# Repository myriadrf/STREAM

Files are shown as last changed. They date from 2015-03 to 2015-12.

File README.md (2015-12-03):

# STREAM

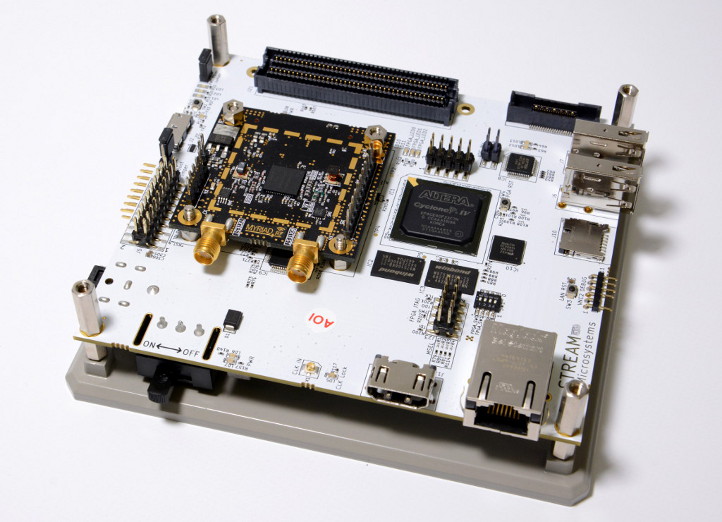
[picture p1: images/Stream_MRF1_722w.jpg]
STREAM board fitted with a Myriad-RF 1 module


[STREAM](https://myriadrf.org/projects/stream/) is a flexible platform for developing high-performance digital and RF designs using an Altera Cyclone IV FPGA and Lime Microsystems FPRF transceiver.

The original STREAM board incorporates SDRAM, Micro SD storage and a selection of other useful peripherals, with expansion via RFDIO and FMC mezzanine cards enabling use with both LMS6002-based Myriad-RF 1 and UNITE LMS7002M EVB RF modules.

uSTREAM is a low cost variant that incorporates a uRFDIO connector, enabling use with the uMyriadRF-6002 and uMyriadRF-7002 RF modules.

For more details about compatible Myriad-RF transceiver modules, see the [Reference Development Kit](https://myriadrf.org/projects/rdk/).

## Contents

The directory structure is as follows:

      apps/
          lms6_usb_distro_03v/        - uSTREAM + uMyriadRF-6002 examples
          lms7_usb_distro_01v/        - uSTREAM + uMyriadRF-7002 examples
          STREAM_LMS7EVB_distro_07v/  - STREAM + UNITE LMS7002EVB examples

      docs/                      - platform documentation

      hardware/<variant>/<version>/
          BOM/                   - bill of materials spreadsheet
          Case/                  - Aluminium case design
          Gerbers/               - Gerber CAM files
          KiCAD/                 - KiCAD schematic and layout files
          Manufacturing/         - Additional manufacturing information
          PDF/                   - Schematic and layout PDFs
          Reports/               - DRC, ERC and drill reports
              
      stream_openrisc_soc/
          bin/                   - pre-built FPGA and Linux images
          doc/                   - HTML documentation for the Stream OpenRISC SoC
          quartus/               - Quartus project archive for rebuilding the FPGA image
          src/                   - Source code for Stream-specific cores
          sw/                    - Example applications for communicating with LMS6002D

## Licensing

### Hardware

The hardware designs are licensed under a Creative Commons Attribution 3.0 Unported licence.

### FPGA design

For details of the FPGA design licensing please see the associated COPYING file(s). However, please note that this does not extend to any files provided with the Altera design tools and see the relevant files for the associated terms and conditions.

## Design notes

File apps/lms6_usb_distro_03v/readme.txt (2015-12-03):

CONTENTS
========

   I. Description of folders and files
  II. General notes
 III. ToDo

I. Description of folders and files
===================================

  readme.txt                - This file
  fx3/                      - FX3 USB microcontroller related
   |- firmware_img          - Contains compiled firmware image for FX3 USB microcontroller
  gateware                  - FPGA related
   |- bitstreams            - Contains compiled FPGA bitstreams
       |- lms6usb_trx.rbf   - FPGA biststream file. Download it to FPGA using LMS-suite Programmer
       |- lms6usb_trx_compresed.rbf   - FPGA biststream file. Download it to FPGA using LMS-suite Programmer
       |- lms6usb_trx.sof   - FPGA biststream file. Download it to FPGA using Quartus programmer
  gui                       - Software to control MyriadRF board
   |- lms-suite.exe         - Windows GUI to control/program FPGA
   |- lms6usb_settings_v1.ini  - GUI project file to test WFM Tx and FFT Viewer
   |- lms-suite_wfm
       |- onetone.wfm       - One tone test waveform file
       |- wcdma.wfm         - WCDMA test waveform file

II. General notes
==================

  Note 1: FX3 drivers, utilities and documentation must be downloaded from Cypress. 
  Note 2: FX3 MCU must be programmed before FPGA.
  Note 3: LD2 LED will start to flash after FX3 MCU is programmed successfully.
  Note 4: FPGA must be programmed before LMS6 configuration. LD5 starts to flash after succesfull FPGA programming.  
  Note 5: Set TX and RX interface clock and phase shift to 90deg. in "LMS6002USB Stick" module from "Modules" menu.	 
  Note 6: Set "Data format" to "Stream" in FFTviewer.
  Note 7: Set "Sampling frequency" to Rxfreq/2 in FFTviewer.
  Note 8: TCXO control voltage may be controlled using a "LMS6002USB Stick" module from "Modules" menu.

III. ToDo
=========

  1. RPi connector - needs to be considered what to implement.

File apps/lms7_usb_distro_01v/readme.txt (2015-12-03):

CONTENTS
========

   I. Description of folders and files
  II. General notes
 III. ToDo

I. Description of folders and files
===================================

  readme.txt                     - This file
  ReleaseNotes.txt              - Distribution release change log
  fx3/                           - FX3 USB microcontroller related
   |- firmware_img               - Contains compiled firmware image for FX3 USB microcontroller
  gateware                       - FPGA related
   |- bitstreams                 - Contains compiled FPGA bitstreams
       |- lms7_ustream_trx.rbf   - FPGA biststream file. Download it to FPGA using LMS-suite Programmer
       |- lms7_ustream_trx.sof   - FPGA biststream file. Download it to FPGA using Quartus programmer
  qii_projects                   - Quartus II project of gateware
  gui                            - Software to control MyriadRF board
   |- lms7suite.exe              - Windows GUI to control the boards
   |- ustream_trx.ini            - GUI project file to test WFM Tx and FFT Viewer
   |- lms7suite_wfm
   |   |- onetone.wfm            - One tone test waveform file
   |   |- wcdma.wfm              - WCDMA test waveform file
   |- lms7suite_mcu              - LMS7002M internal MCU related files

II. General notes
==================

  Note 1: FX3 drivers, utilities and documentation must be downloaded from Cypress. 
  Note 2: FX3 MCU must be programmed before FPGA.
  Note 3: LD2 LED will start to flash after FX3 MCU is programmed successfully.
  Note 4: FPGA must be programmed before LMS7 configuration. LD5 starts to flash after succesfull FPGA programming.  

III. ToDo
=========

  1. RPi connector - needs to be considered what to implement.

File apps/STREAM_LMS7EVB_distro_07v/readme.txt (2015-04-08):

CONTENTS
========

   I. Description of folders and files
  II. General notes
 III. Required PCB Modifications

I. Description of folders and files
===================================

  readme.txt                - this file
        docs/                     - Quick start and user guides
	fx3/                      - FX3 USB microcontroller related
	 |- firmware_img          - Contains compiled firmware image for FX3 USB microcontroller
	gateware                  - FPGA related
	 |- bitstreams            - Contains compiled FPGA bitstreams
	     |- lms7_trx_61MHz.rbf   - FPGA biststream file. Download it to FPGA using LMS-suite Programmer
             |- lms7_trx_61MHz.sof   - FPGA biststream file. Download it to FPGA using Quartus programmer
	     |- lms7_trx_122MHz.rbf  - FPGA biststream file. Download it to FPGA using LMS-suite Programmer
             |- lms7_trx_122MHz.sof  - FPGA biststream file. Download it to FPGA using Quartus programmer
	 |- qii_projects          - Contains FPGA projects
	gui                       - Software to control MyriadRF board
	 |- lms7suite.exe         - GUI to control/program FPGA
	 |- wfm_tx_rx_61MHz.ini   - GUI project file to test WFM Tx and FFT Viewer, with 61.44MHz
	 |- wfm_tx_rx_122MHz.ini  - GUI project file to test WFM Tx and FFT Viewer, with 122.88MHz
	 |- onetone1.wfm          - One tone test waveform file
	 |- wcdma31.wfm           - WCDMA test waveform file
	lms_vcp_drivers           - Windows Virtual COM Port drivres for LMS7EVB
        lms7evb
         |-LMS7002EVBv2_e.hex     - Firmware for LMS7EVB USB microcontroller

II. General notes
==================

  	Note 1: FX3 MCU must be programmed before FPGA.
	Note 2: LD1 LED will start to flash after FX3 MCU is programmed successfully.
	Note 3: FPGA must be programmed before LMS7EVB configuration. Led (lan_led in schematic) on Ethernet connector starts to blink after succesfull FPGA programming.  
	Note 4: After programming FPGA and LMS7EVB configuration FPGA GPIO0 (pin 1 of J1 connector) will on/off for ~1s period.
	Note 5: Jumpers J22 (STREAM board) and JP2 position 1-2 (LMS7EVB board) has to be on if power is required from FMC connector for LMS7EVB. 

III. Required PCB Modifications
===============================

  Some resistors must be fitted on Streamer and LMS7EVB boards to be able control LMS7EVB via FMC connector.

  Streamer board modifications:
  Fit these resistors: R189, R190, R191, R192, R193, R194

  EVB7 board modifications:
  Fit these resistors: 	R91, R92, R93, R94, R95, R96

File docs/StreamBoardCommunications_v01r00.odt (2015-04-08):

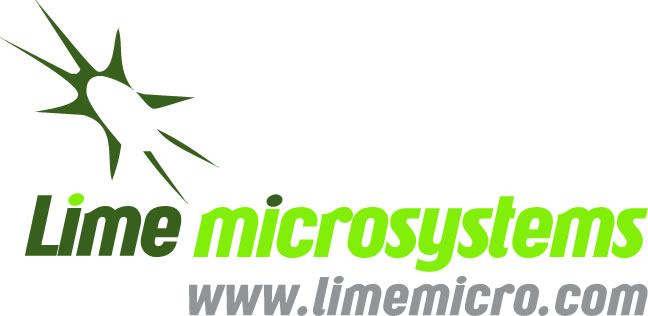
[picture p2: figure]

Lime Microsystems Limited

Surrey Tech Centre

Occam Road

The Surrey Research Park

Guildford, Surrey GU2 7YG

United Kingdom

Tel: +44 (0) 1483 685 063

Fax: +44 (0) 1428 656 662

e-mail: enquiries@limemicro.com

Stream Board Communications

Chip version: | LMS7002Mr2
Chip revision: | 02
Document version: | 03
Document revision: | 03
Last modified: | 03/04/2015 12:22:35

Contents

Revision History

Version v01r00

Released: 19 Jan, 2015

Initial version.

Version v01r01

Released: 03 Feb, 2015

Added FPGA programming description and example, changed document structure.

Version v01r02

Released: 18 Mar, 2015

Chapter 3 added.

Version v01r03

Released: 23 Mar, 2015

Chapter 4 added.

Chapter 2 updated.

IQ Samples data formats for PC and FX3 communications

### Uncompressed data format

Stream board samples uses 1 bit for I or Q channel selection and 12 bits for amplitude. One pair of I and Q samples makes up one frame. Each frame is transferred using 4 bytes as shown in Table 1.This data format is used for uploading and downloading samples.

Table 1 Samples data buffer

Buffer byte index | Data (8-bits) | Frame
0 | [7:0] I0 LSB | 0
1 | 0x00 + [3:0] I0 MSB
2 | [7:0] Q0 LSB
3 | 0x10 + Q0 MSB
4 | [7:0] I1 LSB | 1
5 | 0x00 + [3:0] I1 MSB
6 | [7:0] Q1 LSB
7 | 0x10 + Q1 MSB

Stream Board PC and FX3 communications

Stream board can be connected to the PC by USB 2.0 or USB 3.0. The software can perform SPI registers writing and reading operations over USB device’s control endpoints using LMS64C control protocol, see [1] for more information. The control endpoints should be configured as shown in Table 2.

Table 2 USB control endpoints configuration

Field | In Endpoint | Out Endpoint
Request Code | 0xC0 | 0xC1
Value | 0x0000 | 0x0000
Index | 0x0000 | 0x0000

The following commands are supported in Stream board bridge MCU (FX3):

- CMD_GET_INFO
- CMD_LMS_RST
- CMD_SI5351_WR
- CMD_SI5351_RD
- CMD_LMS6002_WR
- CMD_LMS6002_RD
- CMD_LMS7002_WR
- CMD_LMS7002_RD
- CMD_ADF4002_WR
- LMS_BRDSPI16_WR
- LMS_BRDSPI16_RD
- CMD_ALTERA_FPGA_GW_WR

### Getting board information

Send a CMD_GET_INFO command to the bridge MCU to get an infomation about the hardware as described in [1]. In case of Stream board information is returned by MCU as shown in Table 3.

Table 3 Board information

Field | Value
FW_ver | 2
Dev_type | 8
Protocol_ver | 1
HW_ver | 2
EXP_ID | 0

### Reseting LMS chip

Send a CMD_LMS_RST command to the bridge MCU to to reset the LMS chip as described in [1].

### Communicating with LMS transceivers

Variuos expansion boards may be connected to the Stream board. Expansion boards may be populated with LMS6002D or LMS7002M transceivers. The commands CMD_LMS6002_WR, CMD_LMS6002_RD, CMD_LMS7002_WR and CMD_LMS7002_RD are designed to setup and read setup data to these transceivers. Check [1] for more information.

### Communicating with Si5351

Stream board has Si5351 clock synthesizer onboard. The commands CMD_SI5351_WR and CMD_SI5351_RD are dedicated for Si5351 clock synthesizer setup. See [1] for more information.

### Communicating with ADF4002

Stream board has ADF4002 PLL onboard. The command CMD_ADF4002_WR is dedicated for ADF4002 setup. It is not possible to read the configuration data from ADF4002 hence no corresponding command. See [1] for more information.

### FPGA modules setup

FPGA gateware on Stream board is controlled by 16 bit memory registers, which can be read or written by using LMS64C data protocol and CMD_BRDSPI16_WR and CMD_BRDSPI16_RD commands as described in [1]. The SPI registers are shown in Table 4.

Table 4 Stream board registers

Address (15 bits) | Bits | Description
0x0005 | 15 – 5 4 3 2 1 0 | Unused CH_SEL: Selects Rx channel for streaming to FX3 0 – DIQ1(default) 1 – DIQ2 STREAM_RXDSRC: Selects Rx data source: 0 – NCO(default) 1 – ADC STREAM_RXEN: Enables data streaming from FPGA to FX3 0 – Disabled(default) 1 – Enabled STREAM_TXEN: Enables data streaming from RAM 0 – Disabled 1 – Enabled (default) STREAM_LOAD: Enables data loading 0 – Enabled(default) 1 – Disabled Default: 0000000 00000010

### FPGA programming

FPGA programming is performed by sending data to USB device’s control end point. Data needs to be encapsulated in LMS64C packet, using CMD_ALTERA_FPGA_GW_WR command, as described in [1].

Example C++ program for FPGA programming is given in 1.10.3 chapter.

### IQ samples writing

IQ Samples writing is performed by sending data to USB device’s bulk end point, which has address 0x01. Before that Stream board has to be configured to accept incoming data.

The general steps for IQ samples writing are:

1. Enable STREAM_LOAD and disable STREAM_TXEN, STREAM_RXEN.
2. Transfer samples data to USB Endpoint whose address is 0x01. Samples writing can be done either in one transaction, or several successive transactions.
3. Disable STREAM_LOAD and enable STREAM_TXEN.

Minimal C++ program for writing IQ samples is given in 21.10.1 chapter.

### IQ samples reading

IQ Samples reading is performed by reading data from USB device’s bulk end point, which has address 0x81. Before that Stream board has to be configured to send out data samples.

The general steps for IQ samples reading are:

1. Enable STREAM_RXEN.
2. Read data samples from USB Endpoint whose address is 0x81. Reading can be repeated indefinitely.
3. After reading is done. Disable STREAM_RXEN.

Minimal C++ program for reading IQ samples is given in 21.10.2 chapter.

### FX3 communication examples

#### IQ Samples writing example

This program is written in C++ on Windows operating system. USB communications are performed using CyAPI library, it can be downloaded from EZ-USB FX3 Software Development Kit for Windows (http://www.cypress.com/?docID=42388&dlm=1). The program reads given WFM file, converts it to 12 bit values and uploads to Stream board.

#include <windows.h>

#include "CyAPI/CyAPI.h"

#include <iostream>

#include <stdio.h>

#include <vector>

#define CTR_W_REQCODE 0xC1

#define CTR_W_VALUE 0x0000

#define CTR_W_INDEX 0x0000

#define CTR_R_REQCODE 0xC0

#define CTR_R_VALUE 0x0000

#define CTR_R_INDEX 0x0000

#define CMD_BRDSPI_WR 0x55//16 bit spi for stream

#define CMD_BRDSPI_RD 0x56//16 bit spi for stream

using namespace std;

int ReadWFM(const char *filename, std::vector< std::pair<int, int> > &iq_pairs)

{

FILE *fpin;

unsigned char c1, c2, c3, c4;

double iin, qin; // IQ inputs

int iint, qint; // IQ integer versions

int cnt = 0;

fpin = fopen(filename, "rb");

if( fpin == NULL)

{

printf("Input file can not be opened.");

return -1;

}

while( fscanf(fpin, "%c%c%c%c", &c1, &c2, &c3, &c4) == 4 )

{

cnt++;

c1 &= 0xFF;

c2 &= 0xFF;

c3 &= 0xFF;

c4 &= 0xFF;

if( c1&0x80 ) iin = (double)(-1*(1<<15) + ((c1&0x7F)<<8) + c2);

else iin = (double)(((c1&0x7F)<<8) + c2);

if( c3&0x80 ) qin = (double)(-1*(1<<15) + ((c3&0x7F)<<8) + c4);

else qin = (double)(((c3&0x7F)<<8) + c4);

iint = (int)(iin);

qint = (int)(qin);

iint = iint >> 4;

qint = qint >> 4;

iq_pairs.push_back( std::pair<int, int>(iint, qint) );

};

fclose(fpin);

return 0;

}

int main(int argc, char** argv)

{

if(argc < 2)

{

cout << "wfm filename required\n";

return 0;

}

vector< pair<int,int> > iq_pairs;

if(ReadWFM(argv[1], iq_pairs) != 0)

{

cout << "Error reading wfm file\n" << endl;

return -1;

}

const long dataBufLength = iq_pairs.size()*2*sizeof(short);

unsigned char *dataBuf = new unsigned char[dataBufLength];

//construct data buffer

int bufPos = 0;

for(int i=0; i<iq_pairs.size() && bufPos < dataBufLength; ++i)

{

short i_sample = iq_pairs[i].first;

short q_sample = iq_pairs[i].second;

dataBuf[bufPos] = i_sample & 0xFF; // I LSB

dataBuf[bufPos+1] = (i_sample>>8) & 0x0F; // iq select 0, I MSB

dataBuf[bufPos+2] = q_sample & 0xFF; // Q LSB

dataBuf[bufPos+3] = 0x10 | ((q_sample>>8) & 0x0F); // iq select 1, Q MSB

bufPos += 4;

}

CCyUSBDevice USBDevice;

//end points for spi communications

CCyControlEndPoint *InCtrlEndPt = NULL;

CCyControlEndPoint *OutCtrlEndPt = NULL;

//end point for samples uploading

CCyUSBEndPoint *OutEndPt = NULL;

if( USBDevice.DeviceCount() == 0)

{

cout << "USB device not found\n";

return -1;

}

//expecting that only one device is connected

else if(USBDevice.Open(0))

{

InCtrlEndPt = new CCyControlEndPoint(*USBDevice.ControlEndPt);

OutCtrlEndPt = new CCyControlEndPoint(*USBDevice.ControlEndPt);

InCtrlEndPt->ReqCode = CTR_R_REQCODE;

InCtrlEndPt->Value = CTR_R_VALUE;

InCtrlEndPt->Index = CTR_R_INDEX;

OutCtrlEndPt->ReqCode = CTR_W_REQCODE;

OutCtrlEndPt->Value = CTR_W_VALUE;

OutCtrlEndPt->Index = CTR_W_INDEX;

for (int i=0; i<USBDevice.EndPointCount(); ++i)

{

if(USBDevice.EndPoints[i]->Address == 0x01)

{

OutEndPt = USBDevice.EndPoints[i];

long len = OutEndPt->MaxPktSize * 64;

OutEndPt->SetXferSize(len);

break;

}

}

}

else

{

cout << "Failed to open USB device\n";

return -2;

}

if(InCtrlEndPt && OutCtrlEndPt && OutEndPt)

{

unsigned char ctrbuf[64];

unsigned char inbuf[64];

long len = 64;

//Read memory register

memset(ctrbuf, 0, 64);

memset(inbuf, 0, 64);

ctrbuf[0] = CMD_BRDSPI_RD;

ctrbuf[1] = 0;

ctrbuf[2] = 0x01;

ctrbuf[8] = 0x00;

ctrbuf[9] = 0x05;

OutCtrlEndPt->Write(ctrbuf, len);

len = 64;

InCtrlEndPt->Read(inbuf, len);

memset(ctrbuf, 0, 64);

ctrbuf[0] = CMD_BRDSPI_WR;

ctrbuf[1] = 0;

ctrbuf[2] = 0x01;

ctrbuf[8] = 0x00;

ctrbuf[9] = 0x05;

ctrbuf[10] = inbuf[10];

//enable STREAM_LOAD, disable STREAM_TXEN, STREAM_RXEN

ctrbuf[11] = inbuf[11] & ~0x7;

len = 64;

OutCtrlEndPt->Write(ctrbuf, len);

len = 64;

InCtrlEndPt->Read(inbuf, len);

//transfer data buffer to board

long bToSend = dataBufLength;

OutEndPt->XferData(dataBuf, bToSend);

//Read memory register

memset(ctrbuf, 0, 64);

memset(inbuf, 0, 64);

ctrbuf[0] = CMD_BRDSPI_RD;

ctrbuf[1] = 0;

ctrbuf[2] = 0x01;

ctrbuf[8] = 0x00;

ctrbuf[9] = 0x05;

len = 64;

OutCtrlEndPt->Write(ctrbuf, len);

len = 64;

InCtrlEndPt->Read(inbuf, len);

memset(ctrbuf, 0, 64);

ctrbuf[0] = CMD_BRDSPI_WR;

ctrbuf[1] = 0;

ctrbuf[2] = 0x01;

ctrbuf[8] = 0x00;

ctrbuf[9] = 0x05;

ctrbuf[10] = inbuf[10];

ctrbuf[11] = inbuf[11] | 0x3; //disable STREAM_LOAD, enable STREAM_TXEN

len = 64;

OutCtrlEndPt->Write(ctrbuf, len);

len = 64;

InCtrlEndPt->Read(inbuf, len);

}

else

{

cout << "Failed to find USB end points\n";

return -3;

}

return 0;

}

#### IQ Samples reading example

This program is written in C++ on Windows operating system. USB communications are performed using CyAPI library, it can be downloaded from EZ-USB FX3 Software Development Kit for Windows (http://www.cypress.com/?docID=42388&dlm=1). The program reads single buffer of IQ samples from Stream board.

#include <windows.h>

#include "CyAPI/CyAPI.h"

#include <iostream>

#include <vector>

#define CTR_W_REQCODE 0xC1

#define CTR_W_VALUE 0x0000

#define CTR_W_INDEX 0x0000

#define CTR_R_REQCODE 0xC0

#define CTR_R_VALUE 0x0000

#define CTR_R_INDEX 0x0000

#define CMD_BRDSPI_WR 0x55//16 bit spi for stream

#define CMD_BRDSPI_RD 0x56//16 bit spi for stream

using namespace std;

int main(int argc, char** argv)

{

CCyUSBDevice USBDevice;

//end points for spi communications

CCyControlEndPoint *InCtrlEndPt = NULL;

CCyControlEndPoint *OutCtrlEndPt = NULL;

//end point for samples uploading

CCyUSBEndPoint *InEndPt = NULL;

if( USBDevice.DeviceCount() == 0)

{

cout << "USB device not found\n";

return -1;

}

//expecting that only one device is connected

else if(USBDevice.Open(0))

{

InCtrlEndPt = new CCyControlEndPoint(*USBDevice.ControlEndPt);

OutCtrlEndPt = new CCyControlEndPoint(*USBDevice.ControlEndPt);

InCtrlEndPt->ReqCode = CTR_R_REQCODE;

InCtrlEndPt->Value = CTR_R_VALUE;

InCtrlEndPt->Index = CTR_R_INDEX;

OutCtrlEndPt->ReqCode = CTR_W_REQCODE;

OutCtrlEndPt->Value = CTR_W_VALUE;

OutCtrlEndPt->Index = CTR_W_INDEX;

for (int i=0; i<USBDevice.EndPointCount(); ++i)

{

if(USBDevice.EndPoints[i]->Address == 0x81)

{

InEndPt = USBDevice.EndPoints[i];

long len = InEndPt->MaxPktSize * 64;

InEndPt->SetXferSize(len);

break;

}

}

}

else

{

cout << "Failed to open USB device\n";

return -2;

}

if(InCtrlEndPt && OutCtrlEndPt && InEndPt)

{

const int buffer_size = 4096*64; // single transaction size

unsigned char *buffer = NULL;

buffer = new unsigned char[buffer_size];

if(buffer == 0)

{

cout << "error allocating buffers\n";

return -4;

}

memset(buffer, 0, buffer_size);

unsigned char ctrbuf[64];

unsigned char inbuf[64];

long len = 64;

//Read memory register

memset(ctrbuf, 0, 64);

memset(inbuf, 0, 64);

ctrbuf[0] = CMD_BRDSPI_RD;

ctrbuf[1] = 0;

ctrbuf[2] = 0x01;

ctrbuf[8] = 0x00;

ctrbuf[9] = 0x05;

OutCtrlEndPt->Write(ctrbuf, len);

len = 64;

InCtrlEndPt->Read(inbuf, len);

memset(ctrbuf, 0, 64);

ctrbuf[0] = CMD_BRDSPI_WR;

ctrbuf[1] = 0;

ctrbuf[2] = 0x01;

ctrbuf[8] = 0x00;

ctrbuf[9] = 0x05;

ctrbuf[10] = 0;

ctrbuf[11] = inbuf[11] | 0x4; //Enable STREAM_RXEN

len = 64;

OutCtrlEndPt->Write(ctrbuf, len);

len = 64;

InCtrlEndPt->Read(inbuf, len);

//read IQ samples to buffer

long bToSend = buffer_size;

InEndPt->XferData(buffer, bToSend); //this is blocking operation, if board //is not sending any data, program will be stuck at this point

short tempInt = 0;

short* buf;

buf = (short*)buffer;

vector<short> iq_samples;

int framestart = 0; // can be either 1 or 0, depending from chip parameters

//frame start might change it's position in data buffer, so it is

//needed to find the start of the first frame for each transfer

unsigned int fs = 0;

for(fs=0; fs<buffer_size/sizeof(short); ++fs)

{

if( ((buf[fs]&0x1000)>0) == framestart)

break;

++fs;

}

for(; fs<buffer_size/sizeof(short); ++fs)

{

tempInt = buf[fs] & 0x0FFF;

//shifting 4 bits to left then right, to restore number sign

tempInt = tempInt << 4;

tempInt = tempInt >> 4;

iq_samples.push_back(tempInt);

}

delete[] buffer;

//Here iq_samples will be ready for further processing

//Inside the iq_samples, depending on detected frame start position,

//there might be non equal count of I and Q samples.

//Read memory register

memset(ctrbuf, 0, 64);

memset(inbuf, 0, 64);

ctrbuf[0] = CMD_BRDSPI_RD;

ctrbuf[1] = 0;

ctrbuf[2] = 0x01;

ctrbuf[8] = 0x00;

ctrbuf[9] = 0x05;

len = 64;

OutCtrlEndPt->Write(ctrbuf, len);

len = 64;

InCtrlEndPt->Read(inbuf, len);

//write memory register

memset(ctrbuf, 0, 64);

ctrbuf[0] = CMD_BRDSPI_WR;

ctrbuf[1] = 0;

ctrbuf[2] = 0x01;

ctrbuf[8] = 0x00;

ctrbuf[9] = 0x05;

ctrbuf[10] = 0;

ctrbuf[11] = inbuf[11] & ~0x4; // Disable STREAM_RXEN

len = 64;

OutCtrlEndPt->Write(ctrbuf, len);

len = 64;

InCtrlEndPt->Read(inbuf, len);

}

else

{

cout << "Failed to find USB end points\n";

return -3;

}

return 0;

}

#### FPGA programming example

This program is written in C++ on Windows operating system. USB communications are performed using CyAPI library, it can be downloaded from EZ-USB FX3 Software Development Kit for Windows (http://www.cypress.com/?docID=42388&dlm=1). The program reads given RBF file, and uploads it to FPGA.

#include <windows.h>

#include "CyAPI/CyAPI.h"

#include <iostream>

#include <fstream>

#include <vector>

#define CTR_W_REQCODE 0xC1

#define CTR_W_VALUE 0x0000

#define CTR_W_INDEX 0x0000

#define CTR_R_REQCODE 0xC0

#define CTR_R_VALUE 0x0000

#define CTR_R_INDEX 0x0000

#define STATUS_COMPLETED_CMD 0x01

#define BITSTREAM_FILE "bitstream.rbf"

using namespace std;

int main(int argc, char** argv)

{

CCyUSBDevice USBDevice;

//end points for spi communications

CCyControlEndPoint *InCtrlEndPt = NULL;

CCyControlEndPoint *OutCtrlEndPt = NULL;

if( USBDevice.DeviceCount() == 0)

{

cout << "USB device not found\n";

return -1;

}

//expecting that only one device is connected

else if(USBDevice.Open(0))

{

InCtrlEndPt = new CCyControlEndPoint(*USBDevice.ControlEndPt);

OutCtrlEndPt = new CCyControlEndPoint(*USBDevice.ControlEndPt);

InCtrlEndPt->ReqCode = CTR_R_REQCODE;

InCtrlEndPt->Value = CTR_R_VALUE;

InCtrlEndPt->Index = CTR_R_INDEX;

OutCtrlEndPt->ReqCode = CTR_W_REQCODE;

OutCtrlEndPt->Value = CTR_W_VALUE;

OutCtrlEndPt->Index = CTR_W_INDEX;

}

else

{

cout << "Failed to open USB device\n";

return -2;

}

if(InCtrlEndPt && OutCtrlEndPt)

{

unsigned char *m_data = NULL; //bitstream data

long m_data_size = 0; // bitstream file size

//First load bitstream file into memory

fstream fin;

fin.open(BITSTREAM_FILE, ios::in|ios::binary);

if(!fin.good())

{

fin.close();

cout << "File " << BITSTREAM_FILE << " not found\n";

return -2;

}

fin.seekg(0, ios_base::end);

m_data_size = fin.tellg();

m_data = new unsigned char[m_data_size];

fin.seekg(0, ios_base::beg);

fin.readsome((char*)m_data, m_data_size); //read file into memory

fin.close();

//set programming mode

// 0-bitstream to FPGA

// 1-bitstream to FLASH

// 2-bitstream from FLASH

int prog_mode = 0;

//Split bitstream data into 32 byte chunks and send to board

int pktSize = 32;

int data_left = m_data_size; //data left to send

unsigned char* data_src = m_data; //data source pointer

//total number of packet that will be sent, +1 programming end packet

int portionsCount = m_data_size/pktSize + (m_data_size%pktSize > 0) + 1;

int portionNumber; //packet index counter

int status = 0;

unsigned char ctrbuf[64];

unsigned char inbuf[64];

memset(ctrbuf, 0, 64);

ctrbuf[0] = 0x53; // CMD_ALTERA_FPGA_GW_WR = 0x53

ctrbuf[1] = 0;

ctrbuf[2] = 56; // indicate that 56 data bytes will be in the packet

for(portionNumber=0; portionNumber<portionsCount; ++portionNumber)

{

int offset = 8; //control packet offset to data field

memset(&ctrbuf[offset], 0, 56); //set packet data to zeros

ctrbuf[offset+0] = prog_mode;

//set set bitstream chunk index

ctrbuf[offset+1] = (portionNumber >> 24) & 0xFF;

ctrbuf[offset+2] = (portionNumber >> 16) & 0xFF;

ctrbuf[offset+3] = (portionNumber >> 8) & 0xFF;

ctrbuf[offset+4] = portionNumber & 0xFF;

//set how many bytes of bitstream will be in the packet

//on the end of programming last packet with data_cnt 0 needs to be sent

unsigned char data_cnt = data_left > pktSize ? pktSize : data_left;

ctrbuf[offset+5] = data_cnt;

memcpy(&ctrbuf[offset+24], data_src, data_cnt); //copy chunk of bitstream to packet

data_src+=data_cnt; //advance the source pointer

cout << "portion: " << portionNumber << "/" << portionsCount << endl;

//send packet to board

long len = 64;

OutCtrlEndPt->Write(ctrbuf, len);

len = 64;

memset(inbuf, 0, 64);

InCtrlEndPt->Read(inbuf, len);

//calculate data left to send

data_left -= data_cnt;

status = inbuf[1]; //check sent packet status

if(status != STATUS_COMPLETED_CMD)

{

//error occoured, terminate programming

cout << "Programming failed! Status: " << (int)status << endl;

return -1;

}

}

cout << "Programming finished, " << m_data_size << " bytes sent!\n";

delete []m_data;

return 0;

}

else

{

cout << "Failed to find USB end points\n";

return -3;

}

return 0;

}

Stream Board FX3 and FPGA communications

### Introduction

Communication between FX3 USB microcontroller and FPGA are performed using GPIF II interface configured as slave FIFO with 16 bit width data bus. Implementation is based on AN65974 application note from Cypress.

### GPIF II related connections between FX3 and FPGA

FX3 and FPGA GPIF II related connections are as shown in Figure 1.

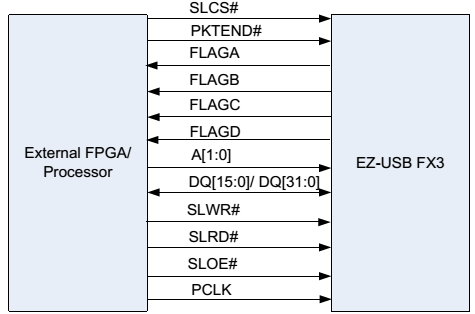
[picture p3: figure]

Figure 1 FX3 and FPGA GPIF II related connection

Detailed description of the signals is provided in Table 5.

Table 5 FX3 and FPGA GPIF II related connection details

Signal Name | Schematic Signal Name | FPGA Pin | Signal Description
SLCS# | FX3_CTL[0] | L7 | Chip select signal for the Slave FIFO interface. It must be asserted to access Slave FIFO.
SLWR# | FX3_CTL[1] | M4 | Write strobe for the Slave FIFO interface. It must be asserted for performing write transfers to Slave FIFO.
SLRD# | FX3_CTL[3] | M7 | Read strobe for the Slave FIFO interface. It must be asserted for performing read transfers from Slave FIFO.
SLOE# | FX3_CTL[2] | M8 | Output enable signal. It causes the data bus of the Slave FIFO interface to be driven by FX3. It must be asserted for performing read transfers from Slave FIFO.
FLAGA, FLAGB, FLAGC, FLAGD | FX3_CTL[4], FX3_CTL[5], FX3_CTL[6], FX3_CTL[8] | M5, P7, M3, N8 | Flag outputs from FX3. The FLAGs indicate the availability of an FX3 socket. FLAGA, FLAGB are used for Slave FIFO write operation and FLAGC, FLAGD are used for Slave FIFO read operation.
A[1:0] | FX3_CTL[11], FX3_CTL[12] | N7, N5 | 2-bit address bus of Slave FIFO.
DQ[15:0] | FX3_DQ[0..15] | R2, R1, V2, V1, U2, U1, R5, T3, P4, P5, N2, P2, P1, M1, N1, P3 | 16-bit data bus of Slave FIFO.
PKTEND# | FX3_CTL[7] | L6 | Assert to write a short packet or a zero-length packet to Slave FIFO.
PCLK | FX3_PCLK | M2 | Slave FIFO interface clock.

### StreamIN data transfers (from FPGA to FX3)

StreamIN data transmits the data from FPGA to FX3 and then to the PC.

To implement StreamIN data transfers some signals, listed in Table 5, may be connected to the high or low level, as shown in Table 6. note please that active (asserted) signal level is low.

Table 6 Used and unused signals to drive GPIF II interface from FPGA for StreamIN

Signal Name | Connect to | Explanation
SLCS# | Low | Assert to access Slave FIFO.
SLWR# | From FPGA data write logic. | Assert for performing write transfers to Slave FIFO.
SLRD# | High | Read strobe for the Slave FIFO interface is not used for StreamIN transfers.
SLOE# | High | Data are driven from FPGA.
FLAGA | To FPGA data write logic. | FLAGA indicates Slave FIFO full when asserted.
FLAGB | To FPGA data write logic. | FLAGB is partial flag and indicates Slave FIFO water level. Becomes asserted when there is room for 2 words to write.
FLAGC | To FPGA data write logic. | Not used.
FLAGD | To FPGA data write logic. | Not used.
A[1:0] | Low, Low | 2-bit address bus of Slave FIFO is "00".
DQ[15:0] | From FPGA data write logic. | 16-bit data bus of Slave FIFO.
PKTEND# | High | Do not use a short packet or a zero-length packet feature.
PCLK | From FPGA | Slave FIFO interface clock, provided from FPGA.

Check an application note AN65974 from Cypress, chapter " Design Example 1: Interfacing an Xilinx FPGA to FX3’s Synchronous Slave FIFO Interface" for more detailed explanation on how to implement StreamIN interface between FX3 and FPGA.

### StreamOUT data transfers (from FX3 to FPGA)

StreamOUT data transmits the data from PC to FX3 and then to FPGA.

To implement StreamIN data transfers some signals, listed in Table 5, may be connected to the high or low level, as shown in Table 7. note please that active (asserted) signal level is low.

Table 7 Used and unused signals to drive GPIF II interface from FPGA for StreamOUT

Signal Name | Connect to | Explanation
SLCS# | Low | Assert to access Slave FIFO.
SLWR# | High | Write strobe for the Slave FIFO interface is not used for StreamOUT transfers.
SLRD# | From FPGA data read logic. | Assert for performing read transfers from Slave FIFO.
SLOE# | From FPGA data read logic. | Assert when data are driven from FX3.
FLAGA | To FPGA data write logic. | Not used.
FLAGB | To FPGA data write logic. | Not used.
FLAGC | To FPGA data write logic. | FLAGC indicates Slave FIFO empty when asserted.
FLAGD | To FPGA data write logic. | FLAGD is partial flag and indicates Slave FIFO water level. Becomes asserted when there 0 not read words.
A[1:0] | High, High | 2-bit address bus of Slave FIFO is "11".
DQ[15:0] | To FPGA data read logic. | 16-bit data bus of Slave FIFO.
PKTEND# | High | Do not use a short packet or a zero-length packet feature.
PCLK | From FPGA | Slave FIFO interface clock, provided from FPGA.

Check an application note AN65974 from Cypress, chapter " Design Example 1: Interfacing an Xilinx FPGA to FX3’s Synchronous Slave FIFO Interface" for more detailed explanation on how to implement StreamIN interface between FX3 and FPGA.

References

1. Lime Microsystems, LMS64C Control Protocol, Description.

Serial Port Interface

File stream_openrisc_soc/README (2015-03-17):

doc/
- HTML documentation for the Stream OpenRISC SoC
bin/
- stream.sof : Pre-built FPGA image
- vmlinux    : Pre-built Linux image
quartus/
- Quartus project archive for rebuilding the FPGA image
src/
- Source code for Stream-specific cores
- src/fx3 : FX3 communication controller
- src/myriadrf : Peripheral core for communicating with LMS6002D transceivers
- src/or1k_bootloaders : A collection of bootloaders for OpenRISC 1000
- src/stream : Stream OpenRISC SoC top-level core
- src/wb_ram : Altera-specific version of the Wishbone Block RAM core
- src/wb_streamer : Wishbone-compatible DMA Streamer

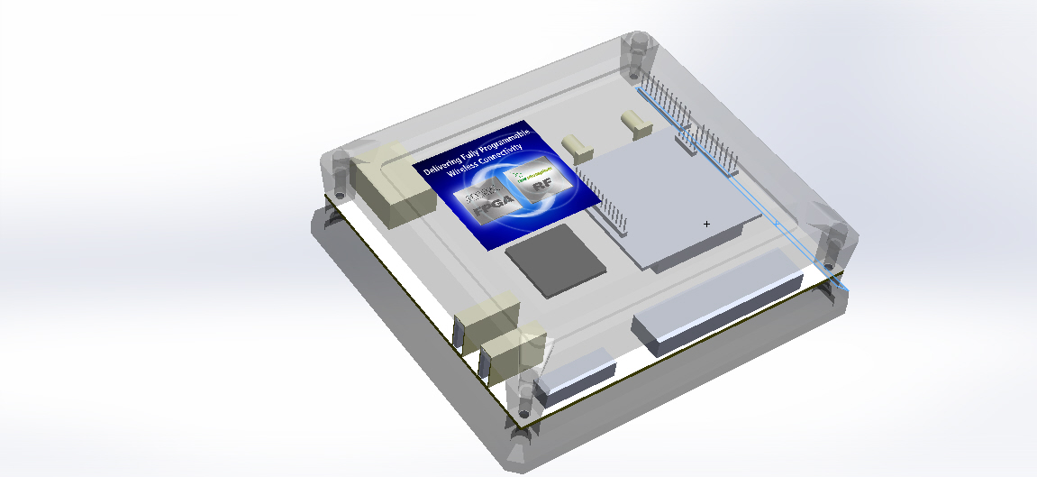
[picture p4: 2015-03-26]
hardware/STREAM/v2/v2r1/Case/STREAM_enclosure_render.jpg

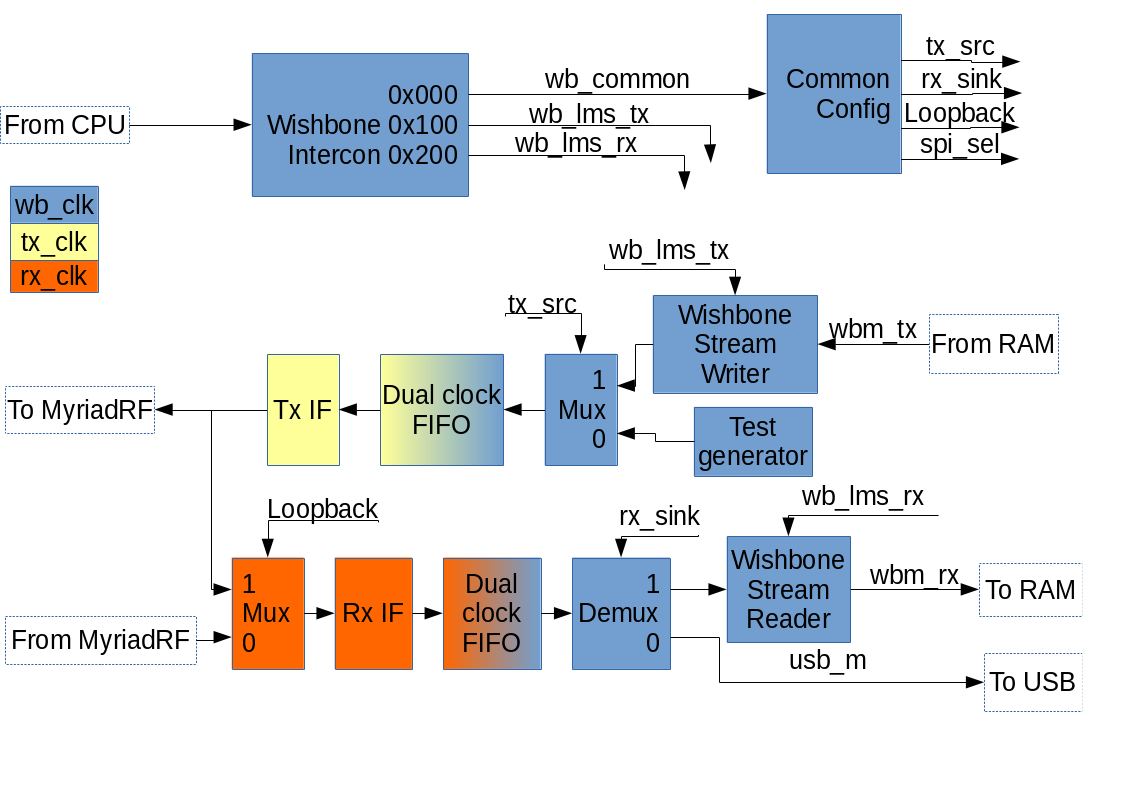
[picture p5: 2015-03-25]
stream_openrisc_soc/doc/dataflow.png

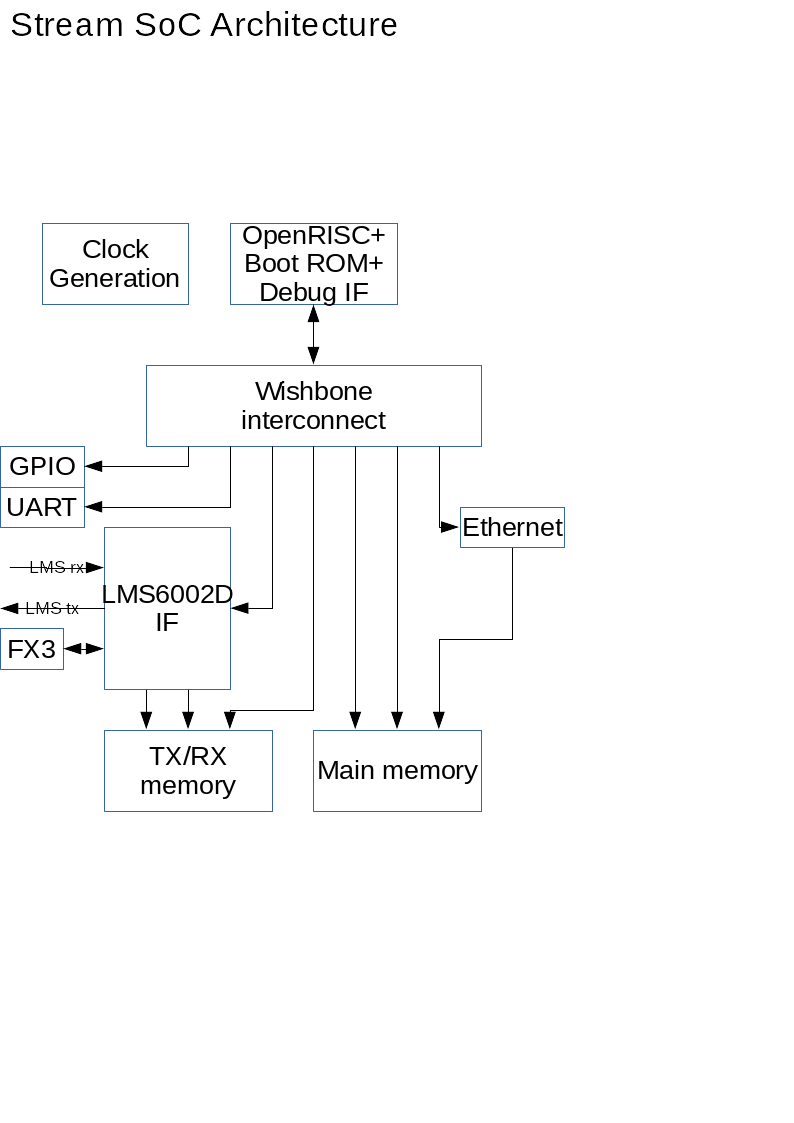
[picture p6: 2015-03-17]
stream_openrisc_soc/doc/arch.png

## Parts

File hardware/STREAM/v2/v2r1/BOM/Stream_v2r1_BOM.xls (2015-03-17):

Component | QTY | Reference | Footprint | Supplier | Supllier Part Nr | Manufacturer | Manu Part Nr | Description | Value | Assemble
0.22UF_0402 | 1 | C192 | C_SM0402 | Digi-Key | 445-5944-1-ND | TDK Corporation | C1005X5R1E224K050BC | CAP CER, 0.22UF, 25V, 10%, X5R, 0402, | 0.22uF
0.33UF_0603 | 2 | C144 C161 | SMD0603 | Farnell | 1759404RL | MULTICOMP | MCCA000526 | MLCC 0603 X5R 16V 0.33UF | 0.33uF
2.2UF_0603 | 9 | C146 C147 C148 C149 C150 C176 C177 C178 C259 | C_SM0603 | Digi-Key | 311-1450-1-ND | Yageo | CC0603ZRY5V6BB225 | CAP CER, 2.2UF, 10V, Y5V, 0603, | 2.2uF
2.2NF_0402 | 2 | C142 C157 | SMD0402 | Digi-Key | 1276-1054-1-ND | Samsung Electro-Mechanics America, Inc | CL05B222KB5NNNC | CAP CER 2200PF 50V 10% X7R 0402 | 2.2nF
4.7UF_0805 | 8 | C210 C212 C296 C298 C299 C300 C301 C303 | C_SM0805 | DigiKey | 490-6450-1-ND | Murata Electronics North America | GRM219R60J475KE19D | CAP CER, 4.7UF, 6.3V, 10%, X5R, 0805, | 4.7uF
220UF_AL_CAP | 1 | C164 | 6.3mm_Al_cap | 493-6367-1-ND | CAP ALUM 220UF 16V 20% SMD | Digi-Key | UCD1C221MCL1GS | Nichicon | 220uF
100NF_0402 | 89 | C1 C2 C3 C4 C5 C6 C7 C8 C9 C10 C11 C12 C13 C14 C15 C16 C17 C18 C19 C20 C21 C22 C23 C24 C25 C26 C27 C28 C29 C30 C31 C34 C37 C38 C39 C40 C41 C44 C45 C46 C47 C48 C63 C64 C66 C67 C68 C69 C70 C71 C74 C75 C76 C77 C78 C82 C83 C84 C85 C86 C87 C88 C89 C90 C91 C92 C104 C154 C171 C173 C175 C179 C180 C186 C195 C196 C203 C204 C221 C224 C227 C230 C239 C249 C304 C305 C313 C314 C315 | C_SM0402 | DigiKey | 399-3027-1-ND | KEMET | C0402C104K8PACTU | CAP, CER, 0.1UF, 10V, 10%, X5R, 0402, | 100nF
13PF_0402 | 2 | C42 C43 | C_SM0402 | DigiKey | 490-5925-1-ND | Murata Electronics North America | GRM1555C1H130JA01D | CAP CER, 13PF, 50V, 5%, NPO, 0402, | 13pF
1UF_0402 | 15 | C49 C55 C73 C153 C169 C170 C198 C208 C209 C222 C225 C228 C231 C240 C254 | C_SM0402 | Digi-Key | 490-6298-1-ND | Murata Electronics North America | GRM155R61A105KE15J | CAP, CER, 1UF, 10V, 10%, X5R, 0402, | 1uF
47PF_0402 | 4 | C51 C53 C54 C56 | C_SM0402 | DigiKey | 311-1021-1-ND | Yageo | CC0402JRNPO9BN470 | CAP CER, 47PF, 50V, 5%, NPO, 0402, | 47pF
1UF_0402 | 2 | C57 C151 | C_SM0402 | Digi-Key | 311-1377-1-ND | Yageo | CC0402ZRY5V5BB105 | CAP, CER, 1UF, 6.3V, Y5V, 0402, | 1uF
10NF_0402 | 14 | C58 C118 C127 C128 C129 C130 C132 C133 C135 C138 C139 C159 C165 C172 | C_SM0402 | DigiKey | 311-1349-1-ND | Yageo | CC0402KRX7R9BB103 | CAP CER, 10000PF, 50V, 10%, X7R, 0402, | 10nF
7PF_0402 | 2 | C80 C81 | C_SM0402 | DigiKey | 445-10817-1-ND | TDK Corporation | C1005CH1H070C050BA | CAP CER, 7PF, 50V, CH, 0402, | 7pF
100NF_0402 | 20 | C93 C99 C111 C112 C113 C114 C115 C117 C119 C120 C122 C123 C125 C126 C131 C134 C136 C137 C167 C168 | C_SM0402 | DigiKey | 399-3027-1-ND | KEMET | C0402C104K8PACTU | CAP, CER, 0.1UF, 10V, 10%, X5R, 0402, | 100nF
100PF_0402 | 10 | C100 C101 C102 C103 C105 C106 C107 C108 C109 C110 | C_SM0402 | Digi-Key | 311-1024-1-ND | Yageo | CC0402JRNPO9BN101 | CAP CER, 100PF, 50V, 5%, NPO, 0402, | 100pF
10UF_0805 | 1 | C166 | C_SM0402 | Digi-Key | 445-11388-1-ND | TDK Corporation | C2012JB0J106K125AB | CAP CER, 10UF, 6.3V, 10%, JB, 0805, | 10uF
15PF_0402 | 1 | C183 | C_SM0402 | DigiKey | 1276-1179-1-ND | Samsung Electro-Mechanics America, Inc | CL05C150JB5NNNC | CAP CER 15PF 50V 5% NP0 0402 | 15pF
10NF_0402 | 7 | C187 C220 C223 C226 C229 C235 C244 | C_SM0402 | DigiKey | 311-1349-1-ND | Yageo | CC0402KRX7R9BB103 | CAP CER, 10000PF, 50V, 10%, X7R, 0402, | 10nF
47NF_0402 | 1 | C190 | C_SM0402 | DigiKey | 490-6042-1-ND | Murata Electronics North America | GCM155R71C473KA37D | CAP CER, 0.047uF, 16V, 10%, X7R, 0402, | 47nF
1UF_0402 | 3 | C191 C194 C200 | C_SM0402 | Digi-Key | 490-6298-1-ND | Murata Electronics North America | GRM155R61A105KE15J | CAP, CER, 1UF, 10V, 10%, X5R, 0402, | 1uF
47NF_0402 | 1 | C193 | C_SM0402 | DigiKey | 490-6042-1-ND | Murata Electronics North America | GCM155R71C473KA37D | CAP CER, 0.047uF, 16V, 10%, X7R, 0402, | 47nF
7PF_0402_NF | 2 | C219 C316 | C_SM0402 | DigiKey | 445-10817-1-ND | TDK Corporation | C1005CH1H070C050BA | CAP CER, 7PF, 50V, CH, 0402, | 7pF | NOFIT
1UF_0603 | 1 | C59 | C_SM0603 | Digi-Key | 311-1372-1-ND | Yageo | CC0603ZRY5V7BB105 | CAP, CER, 1UF, 16V, Y5V, 0603, | 1uF
10UF_0603 | 4 | C62 C72 C79 C306 | C_SM0603 | Digi-Key | 311-1448-1-ND | Yageo | CC0603MRX5R5BB106 | CAP, CER, 10UF, 6.3V, 20%, X5R, 0603, | 10uF
22UF_0805 | 1 | C65 | C_SM0805 | Digi-Key | 445-1422-1-ND | TDK Corporation | C2012X5R0J226M125AC | CAP CER, 22UF, 6.3V, 20%, X5R, 0805, | 22uF
22UF_0805 | 8 | C116 C121 C124 C317 C318 C319 C320 C321 | C_SM0805 | Digi-Key | 587-1958-1-ND | Taiyo Yuden | LMK212BJ226MG-T | CAP CER, 22UF, 10V, 20%, X5R, 0805, | 22uF
10UF_0805 | 3 | C152 C158 C163 | C_SM0805 | Digi-Key | 445-11388-1-ND | TDK Corporation | C2012JB0J106K125AB | CAP CER, 10UF, 6.3V, 10%, JB, 0805, | 10uF
22UF_0805 | 4 | C199 C205 C206 C207 | C_SM0805 | Digi-Key | 587-1958-1-ND | Taiyo Yuden | LMK212BJ226MG-T | CAP CER, 22UF, 10V, 20%, X5R, 0805, | 22uF
100UF_1206 | 9 | C50 C52 C182 C197 C211 C214 C216 C217 C218 | C_SM1206 | DigiKey | 490-4539-1-ND | Murata Electronics North America | GRM31CR60J107ME39L | CAP CER, 100UF, 6.3V, 20%, X5R, 1206, | 100uF
47UF_1206 | 1 | C181 | C_SM1206 | DigiKey | 490-3907-1-ND | Murata Electronics North America | GRM31CR60J476ME19L | CAP CER, 47UF, 6.3V, 20%, X5R, 1206, | 47uF
22UF_1206_X5R | 2 | C188 C189 | C_SM1206 | Digi-Key | 490-4739-1-ND | Murata Electronics North America | GRM31CR61C226ME15L | CAP CER, 22UF, 16V, 20%, X5R, 1206, | 22uF
47UF_1206 | 2 | C201 C202 | C_SM1206 | DigiKey | 490-3907-1-ND | Murata Electronics North America | GRM31CR60J476ME19L | CAP CER, 47UF, 6.3V, 20%, X5R, 1206, | 47uF
100NF_0201 | 52 | C32 C33 C35 C36 C174 C185 C232 C233 C234 C236 C237 C238 C241 C242 C243 C245 C246 C247 C248 C250 C251 C252 C253 C255 C256 C257 C258 C260 C261 C262 C263 C266 C267 C268 C270 C271 C272 C273 C274 C275 C276 C277 C279 C280 C284 C285 C288 C289 C290 C291 C292 C293 | SM0402 | DigiKey | 490-3167-1-ND | Murata Electronics North America | GRM033R60J104KE19D | CAP CER 0.1UF 6.3V 10% X5R 0201 | 100nF
10PF_0402 | 4 | C60 C61 C184 C308 | SMD0402 | Digi-Key | 311-1014-1-ND | Yageo | CC0402JRNPO9BN100 | CAP, CER, 10PF, 50V, 5%, NPO, 0402, | 10pF
22PF_0402 | 5 | C94 C95 C96 C143 C160 | SMD0402 | DigiKey | 311-1018-1-ND | Yageo | CC0402JRNPO9BN220 | CAP CER, 22PF, 50V, 5%, NPO, 0402, | 22pF
100NF_0402 | 3 | C97 C98 C307 | SMD0402 | DigiKey | 311-1047-1-ND | Yageo | CC0402ZRY5V7BB104 | CAP, CER, 0.1UF, 16V, Y5V, 0402, | 100nF
22NF_0402 | 2 | C141 C156 | SMD0402 | DigiKey | 311-1378-1-ND | Yageo | CC0402KRX7R9BB103 | CAP CER, 0.022UF, 16V, 10%, X7R, 0402, | 22nF
10NF_0402 | 2 | C309 C311 | SMD0402 | DigiKey | 311-1349-1-ND | Yageo | CC0402KRX7R9BB103 | CAP CER, 10000PF, 50V, 10%, X7R, 0402, | 10nF
220PF_0402 | 1 | C310 | SMD0402 | DigiKey | 311-1035-1-ND | Yageo | CC0402KRX7R9BB221 | CAP CER, 220PF, 50V, 10%, X7R, 0402, | 220pF
22UF_0805 | 2 | C145 C162 | SMD0805 | Digi-Key | 445-1422-1-ND | TDK Corporation | C2012X5R0J226M125AC | CAP CER, 22UF, 6.3V, 20%, X5R, 0805, | 22uF
10UF_1206 | 2 | C140 C155 | SMD1206 | Digi-Key | 311-1376-1-ND | Yageo | CC1206ZKY5V7BB106 | CAP, CER, 10UF, 16V, Y5V, 1206, | 10uF
PMEG2010AEB_NF | 1 | D6 | SC-79 | Digi-Key | 568-6502-1-ND | NXP Semiconductors | PMEG2010AEB,115 | DIODE SCHOTTKY, 20V, 1A, SOD523, | NF | NOFIT
TS4148 | 2 | D2 D12 | SM0805 | Farnell | 8150206RL | TAIWAN SEMICONDUCTOR | TS4148 RY | DIODE 0.5A 0805 100V | TS4148
20BQ030 | 2 | D1 D10 | SMB | Digi-Key | 20BQ030PBFCT-ND | Vishay Semiconductor Diodes Division | VS-20BQ030TRPBF | DIODE SCHOTTKY, 30V, 2A, DO214AA, | 20BQ030
MMSZ5222BT1G | 1 | D7 | SOD-123 | Digi-Key | MMSZ5222BT1GOSCT-ND | ON Semiconductor | MMSZ5222BT1G | DIODE ZENER 2.5V 500MW SOD123 | MMSZ5222BT1G
FB_600R_0402 | 1 | FB1 | SM0402 | Digi-Key | 445-2162-1-ND | TDK Corporation | MMZ1005S601C | FERRITE CHIP BEAD, 600 OHM, SMD, | 600 Ohm @ 100MHz, 0.3A
FIDUCIAL | 6 | FD1 FD2 FD3 FD4 FD5 FD6 | Fiducial
FR_220R_0402 | 2 | FR1 FR2 | R_SM0402 | Digi-Key | 445-9329-1-ND | TDK Corporation | MPZ1005S221E | FERRITE, CHIP, 220 OHM, 0402, | 100MHz/220/0.9A
FR_600R_0402 | 3 | FR8 FR10 FR12 | R_SM0402 | 445-2162-1-ND | Digi-Key | FERRITE, CHIP, BEAD, 600 OHM, SMD, | MMZ1005S601C | TDK Corporation | 600R
FR_600R_0402 | 1 | FR21 | R_SM0402 | 445-2162-1-ND | Digi-Key | FERRITE, CHIP, BEAD, 600 OHM, SMD, | MMZ1005S601C | TDK Corporation | 100MHz/600/0.3A
FR_600R_0805_2A | 8 | FR13 FR14 FR15 FR16 FR17 FR18 FR19 FR20 | R_SM0805 | 445-2206-1-ND | Digi-Key | FERRITE, CHIP, BEAD, 600 OHM, SMD, | MPZ2012S601AT000 | TDK Corporation | 100MHz/600/2A
TPS51100DGQ | 1 | IC16 | 10MSOP | Digi-Key | IC REG, 3A, SINK/SOURCE, DDR, 10MSOP, | TPS51100DGQ | 296-17851-5-ND | Texas Instruments | TPS51100DGQ
SN74AVC2T245 | 1 | IC13 | 10UQFN | 296-23684-1-ND | Digi-Key | IC BUS, TRANSCVR, TRI-ST DL, 10UQFN | SN74AVC2T245RSWR | Texas Instruments | SN74AVC2T245
CYUSB3013 | 1 | IC6 | 121-TFBGA | Mouser | 727-CYUSB3013-BZXC | Cypress Semiconductor | CYUSB3013-BZXC | USB Interface, IC EZUSB, SuperSpeedCtrl X16, 256KB, | CYUSB3013
LMK00105 | 1 | IC12 | 24LLP | Digi-Key | LMK00105SQ/NOPBCT-ND | Texas Instruments | LMK00105SQ/NOPB | IC, CLK BUFFER, 2:5, 200MHZ, 24LLP, | LMK00105
EN5339QI | 1 | IC23 | 24QFN | Digi-Key | DC/DC CONVERTER, 0.6-4.6V, 14W, | EN5339QI | 544-2854-1-ND | Altera | EN5339QI
VNC2-48L1B | 1 | IC8 | 48-LQFP | Digi-Key | 768-1049-1-ND | FTDI, Future Technology Devices International Ltd | VNC2-48L1B-REEL | IC USB, HOST/DEVICE, CTRL, 48-LQFP, | VNC2-48L1B
TFP410 | 1 | IC9 | 64-TQFP | Digi-Key | 296-21249-1-ND | Texas Instruments | TFP410MPAPREP | IC, TRANSMITTER DIGITAL, 64-HTQFP, | TFP410
EN2390_2PARTS | 1 | IC22 | 76QFN | Digi-Key | DC/DC CONVERTER, 0.75-3.3V, 30W, | EN2390QI | 544-2942-1-ND | Altera | EN2390QI
W9751G6KB-25 | 2 | IC2 IC3 | 84WBGA | Digi-Key | W9751G6KB-25-ND | Winbond Electronics | W9751G6KB-25 | IC, DDR2, SDRAM, 512M, 2.5NS, 84WBGA, | W9751G6KB-25
NCP59151-ADJ | 1 | IC24 | D2PAK-5 | Digi-Key | NCP59151DS50R4GOSCT-ND | ON Semiconductor | NCP59151DS50R4G | IC REG LDO 5V 1.5A D2PAK | NCP59151
EP4CE40F23C7N | 1 | IC1 | LMS_SyntCLK1 | EP4CE40F23C7N | Altera | IC, FPGA, 328 I/O, 484FBGA, | EP4CE40F23C7N | Digi-Key | 544-2687-ND
SI5351C | 1 | IC11 | QFN20 | DigiKey | 336-2402-5-ND | Silicon Laboratories Inc | SI5351C-B-GM | IC, CLK GENERATOR, 160MHZ, 20QFN, | SI5351C
KSZ9021GN | 1 | IC10 | QFN64 | Farnell | KSZ9021GN | MICREL SEMICONDUCTOR | LAN8720A-CP-TR | TXRX, ETHERNET, GB GMII/MII, 64QFN | KSZ9021GN
M25P40 | 1 | IC5 | SOIC-8 | Digi-Key | IC FLASH, 4MBIT, 75MHZ, 8SO, | M25P40-VMN6TPB | M25P40-VMN6TPBCT-ND | Micron Technology Inc | M25P40
M25P16 | 1 | IC15 | SOIC-8 | Digi-Key | IC FLASH, 16MBIT, 75MHZ, 8SO, | M25P16-VMN6TP | M25P16-VMN6TPCT-ND | Micron Technology Inc | M25P16
MIC37122Y_ADJ | 5 | IC14 IC18 IC19 IC20 IC21 | SOIC8 | Digi-Key | 576-4334-1-ND | Micrel Inc | MIC37122YM TR | IC, REG LDO, ADJ, 1A, 8SOIC, | MIC37122
SRV05-4 | 1 | IC7 | SOT-23-6 | F4204CT-ND | SRV05-4HTG | Digi-Key | TVS, DIODE, 6VWM, 15VC, SOT23-6, | Littelfuse Inc | SRV05-4
SP3010-04UTG | 1 | IC4 | uDFN-10 | Digi-Key | F3507TR-ND | Littelfuse Inc | SP3010-04UTG | TVS ARRAY, ESD, 4CH, .45PF, 8KV, UDFN, | SP3010-04UTG
AMP_MICTOR38 | 1 | J13 | AMP_Mictor38 | 2-5767004-2 | A32308-ND | CONN RECEPT, 38POS, .025, VERT SMD, | TE Connectivity | Digi-Key | AMP_Mictor38
FMC_FEMALE_LOW_COUNT | 1 | J21 | FMC_Female | ASP-134603-01 | ASP-134603-01 | FMC | Samtec | Samtec | ASP-134603-01_Socket
FX10B_80S_8 | 1 | J20 | FX10B_80S_8 | CONN RECEPT, 80POS, W/O, POST, SMD, | Digi-Key | FX10B-80S/8-SV(71) | H11236-ND | Hirose Electric Co Ltd | FX10B_80S_8
HDMI | 1 | J12 | HDMI_Conn | 10029449-111RLF | 609-4614-1-ND | CONN HDMI, RECPT, 19POS, SMT, R/A, | FCI | Digi-Key | HDMI
USD | 1 | J10 | MicroSD | 114-00841-68 | 114-00841-68-1-ND | CONN MICRO SD CARD PUSH-PULL R/A | Amphenol Commercial Products | Digi-Key | MicroSD_card
PINHEADER_1X2_TH | 1 | J22 | Pinhead_1x2_TH | 5-146285-2 | 5-146285-2-ND | CONN, HEADR, BRKWAY, .100 2POS, STR, | Digi-Key | TE Connectivity | PinH_2_TH
PINHEADER_1X6_2MM_TH_RIGHT | 1 | J11 | Pinhead_1x6_2mm_TH_right | 952-2286-ND | M22-2530605 | SIL VERTICAL PC TAIL PIN HEADER | Digi-Key | Harwin Inc | PinH_1x6_2mm_TH_right
JTAG_PIN_2X10_SMD_WALL | 1 | J5 | Pinhead_2x10_SMD_wall | S9188-ND | SBH11-NBPC-D10-SM-BK | CONN HEADER, 2.54MM, 20POS, GOLD | Digi-Key | Sullins Connector Solutions | JTAG_Connetor
PINHEADER_2X5_TH_WALL | 1 | J1 | Pinhead_2x6_TH_WALL | Digi-Key | S9169-ND | Sullins Connector Solutions | SBH11-PBPC-D05-ST-BK | CONN HEADER, 2.54MM, 10POS, GOLD, | PinH_2x5_TH
PINHEADER_2X5_TH_WALL | 1 | J23 | Pinhead_2x6_TH_WALL | S9169-ND | SBH11-PBPC-D05-ST-BK | CONN HEADER, 2.54MM, 10POS, GOLD, | Digi-Key | Sullins Connector Solutions | PinH_2x5_TH
PINHEADER_1X2_SMD | 1 | J3 | PINHEADER_1x2_SMD | M20-8770246 | 952-1913-ND | 2POS, SIL, VERTICAL, SMT, HEADER, | Digi-Key | Harwin Inc | PinH_2_SMD
PINHEADER_2X2 | 1 | J8 | PINHEADER_2X2 | Digi-Key | WM9514-ND | Molex Inc | 15912040 | CONN HEADER 4POS TIN SMD
PINHEADER_2X8_SMD_RA | 1 | J4 | PINHEADER_2X8_SMD_RA | Digi-Key | 3M9508TR-ND | 3M | 961216-5500-AR-PR | CONN, HEADER, R/A, 16POS, GOLD, SMD, | PinH_2X8_SMD_RA
PWR_JACK__FC681495 | 1 | J18 | PWR_JACK_TH | 2353934 | Farnell | CLIFF ELECTRONIC COMPONENTS | CONNECTOR, RECEPTACLE, DC POWER, 2.5MM, | FC681495 | PWR_JACK
RJ45_L829-1J1T-43 | 1 | J9 | RJ45_L829-1J1T-43 | Digi-Key | 380-1110-ND | Bel Fuse Inc | L829-1J1T-43 | CONN MAGJACK 1PORT 1000 BASE-T | RJ45
USB2_A | 2 | J6 J7 | TH-USB2_A | DigiKey | AE10400-ND | Assmann WSW Components | A-USB/2-A-E-R | CONN, USB-A, RECEPT, VERTICAL, 2.0, | USB2_A
USB3_MICROB_SMD | 1 | J2 | USB3_microB_SMD | 151-1130-1-ND | Digi-Key | EDAC Inc | MICRO USB 3.0 SMD TYPE | 690-010-295-484 | MICRO_USB3_B
470NH_0603 | 1 | L1 | L_SM0603 | Coilcraft | 0603AF-271XJRU | Coilcraft | 0603AF-271XJRU | Inductor, 470 nH, 0603, 5%, | 470nH
22UH_XAL60XX_SERIES | 2 | L2 L3 | XAL60xx series | Coilcraft | XAL6060-223MEB | Coilcraft | XAL6060-223MEB | SMT power inductor 22 uH | 22uH
LED_0603_YELLOW | 3 | LD1 LD2 LD3 | LD_0603 | 160-1836-1-ND | Lite-On Inc | DigiKey | LTST-C194KSKT | LED, YELLOW, RECT, CLEAR, 0603, | Yellow
LED_0603_GREEN | 9 | LD4 LD6 LD7 LD8 LD9 LD10 LD11 LD12 LD13 | LD_0603 | 516-1425-1-ND | Avago Technologies US Inc. | DigiKey | HSMG-C190 | LED, 570NM, GREEN, DIFF, 0603, SMD, | Green
LED | 1 | LD5 | LED_0603 | Digi-Key | 475-1409-1-ND | OSRAM Opto Semiconductors Inc | LG Q971-KN-1 | LED, CHIPLED, 570NM, GREEN, 0603, SMD, | Green
MOUNTHOLLE | 4 | MH1 MH2 MH3 MH4 | MH
BSS138PS | 2 | Q1 Q2 | SOT-363 | DigiKey | 568-8393-1-ND | NXP Semiconductors | BSS138PS,115 | MOSFET 2N-CH 60V 0.32A 6TSSOP | BSS138PS
0R_0402_NF | 20 | R1 R2 R3 R4 R22 R104 R105 R146 R189 R190 R191 R192 R193 R194 R266 R268 R272 R273 R274 R276 | R_SM0402 | Digi-Key | 311-0.0JRCT-ND | Yageo | RC0402JR-070RL | RES, 0.0 OHM,1/16W, JUMP, 0402 SMD, | 0R | NOFIT
0R_0402 | 25 | R38 R39 R40 R41 R42 R46 R58 R79 R80 R81 R113 R114 R118 R137 R139 R150 R155 R161 R162 R208 R269 R275 R278 R279 R281 | R_SM0402 | Digi-Key | 311-0.0JRCT-ND | Yageo | RC0402JR-070RL | RES, 0.0 OHM,1/16W, JUMP, 0402 SMD, | 0R
0R_0402_NF | 5 | R119 R125 R127 R151 R277 | R_SM0402 | Digi-Key | 311-0.0JRCT-ND | Yageo | RC0402JR-070RL | RES, 0.0 OHM,1/16W, JUMP, 0402 SMD, | 0R | NOFIT
0R_0402_NF | 1 | R199 | R_SM0402 | Digi-Key | 311-0.0JRCT-ND | Yageo | RC0402JR-070RL | RES, 0.0 OHM,1/16W, JUMP, 0402 SMD, | 0R
0R_0805 | 2 | R145 R160 | SM0805 | Digi-Key | P0.0ACT-ND | Panasonic Electronic Components | ERJ-6GEY0R00V | RES 0.0 OHM 1/8W JUMP 0805 SMD | 0R
10R_0402 | 1 | R116 | SMD0402 | Digi-Key | 311-10JRCT-ND | Yageo | RC0402JR-0710RL | RES, 10 OHM, 1/16W, 5%, 0402, SMD, | 10R
22R_0402 | 10 | R56 R57 R59 R60 R61 R62 R102 R103 R128 R300 | R_SM0402 | Digi-Key | 311-22.0LRCT-ND | Yageo | RC0402FR-0722RL | RES, 22.0 OHM, 1/16W, 1%, 0402, SMD, | 22R
47R_0402 | 3 | R122 R123 R124 | SMD0402 | Digi-Key | 311-47.0LRCT-ND | Yageo | RC0402FR-0747RL | RES, 47 OHM, 1/16W, 1%, 0402, SMD, | 47R
51R_0402 | 2 | R67 R143 | SMD0402 | Digi-Key | 311-51JRCT-ND | Yageo | RC0402JR-0751RL | RES, 51 OHM, 1/16W, 5%, 0402, SMD, | 51R
56R_0201 | 82 | R6 R7 R8 R9 R10 R11 R13 R14 R15 R16 R17 R18 R71 R126 R138 R152 R172 R173 R174 R178 R182 R183 R184 R185 R186 R187 R188 R209 R210 R211 R212 R213 R214 R215 R216 R217 R218 R219 R220 R221 R222 R223 R224 R225 R226 R227 R228 R229 R230 R231 R232 R233 R234 R235 R236 R237 R238 R239 R240 R241 R242 R243 R244 R245 R246 R247 R248 R249 R250 R251 R252 R253 R254 R255 R256 R257 R258 R259 R260 R261 R262 R263 | SMD0201 | Digi-Key | 1276-3594-1-ND | Samsung Electro-Mechanics America, Inc | RC0603F560CS | RES 56 OHM 1/20W 1% 0201 | 56R
100R_0402_1% | 1 | R99 | R_SM0402 | Digi-Key | 311-100LRCT-ND | Yageo | RC0402FR-07100RL | RES, 100 OHM, 1/16W, 1%, 0402, SMD, | 100R, 1%
200R/1%_0402 | 1 | R31 | R_SM0402 | Digi-Key | 311-200LRCT-ND | Yageo | RC0402FR-07200RL | RES, 200 OHM, 1/16W, 1%, 0402 SMD, | 200R/1%
200R/1%_0402 | 1 | R280 | R_SM0402 | Digi-Key | 311-200LRCT-ND | Yageo | RC0402FR-07200RL | RES, 200 OHM, 1/16W, 1%, 0402 SMD, | 200R/1%
220R_0402 | 1 | R83 | R_SM0402 | Digi-Key | 311-220JRCT-ND | Yageo | RC0402JR-07220RL | RES, 220 OHM, 1/16W, 5%, 0402, SMD, | 220R
330R_0402 | 1 | R112 | SMD0402 | Digi-Key | 311-330JRCT-ND | Yageo | RC0402JR-07330RL | RES, 330 OHM, 1/16W, 5%, 0402, SMD, | 330R
470R_0402 | 7 | R19 R20 R21 R63 R64 R140 R157 | R_SM0402 | Digi-Key | P470DECT-ND | Panasonic Electronic Components | ERA-2AED471X | RES, 470 OHM, 1/16W, .5%, 0402 SMD, | 470R
470R_0402 | 2 | R111 R117 | SMD0402 | Digi-Key | P470DECT-ND | Panasonic Electronic Components | ERA-2AED471X | RES, 470 OHM, 1/16W, .5%, 0402 SMD, | 470R
510R_0603 | 1 | R65 | R_SM0603 | DigiKey | 311-510HRCT-ND | Yageo | RC0603FR-07510RL | RES, 510 OHM, 1/10W, 5%, 0603, SMD, | 510
750R_0402 | 2 | R12 R159 | R_SM0402 | Digi-Key | 541-750LCT-ND | Vishay Dale | CRCW0402750RFKED | RES, 680 OHM, 1/16W, 1%, 0402, SMD, | 750R
806R_0402 | 2 | R135 R154 | R_SM0402 | Digi-Key | P806DCCT-ND | Panasonic Electronic Components | ERA-2AEB8060X | RES, 806,OHM, 1/16W .1%, 0402 SMD, | 806R
1K_0402 | 14 | R5 R87 R91 R93 R97 R101 R107 R109 R110 R133 R134 R153 R156 R201 | R_SM0402 | Digi-Key | RMCF0402FT1K00CT-ND | Stackpole Electronics Inc | RMCF0402FT1K00 | RES, 1K OHM, 1/16W, 1%, 0402, | 1K
1K_0402_NF | 1 | R95 | R_SM0402 | Digi-Key | RMCF0402FT1K00CT-ND | Stackpole Electronics Inc | RMCF0402FT1K00 | RES, 1K OHM, 1/16W, 1%, 0402, | 1K | NOFIT
1K_0402 | 1 | R120 | SMD0402 | Digi-Key | RMCF0402FT1K00CT-ND | Stackpole Electronics Inc | RMCF0402FT1K00 | RES 1K OHM 1/16W 1% 0402 | 1k
1K5_0402 | 1 | R136 | R_SM0402 | Digi-Key | 311-1.5KJRCT-ND | Yageo | RC0402JR-071K5L | RES,1.5K OHM, 1/16W, 5%, 0402, SMD, | 1K5
2K2_0402 | 1 | R115 | SMD0402 | Digi-Key | 311-2.20KLRCT-ND | Yageo | RC0402FR-072K2L | RES, 2.20K OHM, 1/16W, 1%, 0402, SMD, | 2K2
2K32_0402 | 1 | R70 | R_SM0402 | Digi-Key | RMCF0402FT2K32CT-ND | Stackpole Electronics Inc | RMCF0402FT2K32 | RES, 2.32K, OHM, 1/16W, 1%, 0402,, | 2K32
2K4_0402 | 1 | R165 | R_SM0402 | Digi-Key | 311-2.4KJRCT-ND | Yageo | RC0402JR-072K4L | RES, 2.4K OHM, 1/16W, 5%, 0402, SMD, | 2K4
3K_0402 | 1 | R158 | R_SM0402 | Digi-Key | 541-3.00KLCT-ND | Vishay Dale | CRCW04023K00FKED | RES 3.00K OHM 1/16W 1% 0402 SMD | 3k
3K9_0402 | 1 | R270 | R_SM0402 | DigiKey | P3.90KLCT-ND | Panasonic Electronic Components | ERJ-2RKF3901X | RES SMD 3.9K OHM 1% 1/10W 0402 | 3K9
4K7_0402 | 6 | R73 R74 R163 R167 R283 R284 | R_SM0402 | DigiKey | 311-4.7KJRCT-ND | Yageo | RC0402JR-074K7L | RES, 4.7K OHM, 1/16W, 5%, 0402, SMD, | 4K7
4K7_0402 | 10 | R23 R24 R25 R27 R28 R29 R72 R76 R77 R271 | R_SM0603 | DigiKey | 311-4.7KJRCT-ND | Yageo | RC0402JR-074K7L | RES, 4.7K OHM, 1/16W, 5%, 0402, SMD, | 4K7
4K75_0402 | 1 | R169 | R_SM0402 | Digi-Key | 311-4.75KLCT-ND | Yageo | RC0402FR-074K75L | RES, 4.75K OHM, 1/16W, 1%, 0402, SMD, | 4K75
4K99_0603 | 1 | R82 | R_SM0603 | Digi-Key | 311-4.99KHRCT-ND | Yageo | RC0603FR-074K99L | RES, 4.99K OHM, 1/10W, 1%, 0603, SMD, | 4k99
5K1_0402 | 1 | R176 | R_SM0402 | Digi-Key | 311-5.10KLRCT-ND | Yageo | RC0402FR-075K1L | RES 5.1K OHM 1/16W 1% 0402 SMD | 5k1
5K49_0402 | 2 | R52 R144 | SMD0402 | Digi-Key | 311-5.49KLRCT-ND | Yageo | RC0402FR-075K49L | RES, 5.49K, OHM, 1/16W, 1%, 0402, SMD, | 5K49
6.04K/1%_0402 | 1 | R30 | R_SM0402 | Digi-Key | 541-6.04KLCT-ND | Vishay Dale | CRCW04026K04FKED | RES, 6.04K OHM, 1/16W, 1%, 0402 SMD, | 6.04K/1%
10K_0402 | 33 | R32 R33 R34 R35 R36 R37 R44 R66 R68 R69 R75 R78 R85 R88 R89 R94 R98 R121 R129 R141 R142 R147 R148 R149 R164 R166 R196 R198 R200 R202 R264 R265 R267 | R_SM0402 | Digi-Key | 311-10.0KLRCT-ND | Yageo | RC0402FR-0710KL | RES 10K OHM 1/16W 1% 0402 SMD | 10K
10K_0402_NF | 12 | R45 R47 R84 R86 R90 R92 R96 R100 R106 R108 R195 R197 | R_SM0402 | Digi-Key | 311-10.0KLRCT-ND | Yageo | RC0402FR-0710KL | RES, 10.0K OHM, 1/16W, 1%, 0402, SMD, | 10K | NOFIT
15K_0402 | 1 | R170 | R_SM0402 | Digi-Key | 311-15.0KLRCT-ND | Yageo | RC0402FR-0715KL | RES, 15.0K OHM, 1/16W, 1%, 0402, SMD, | 15K
15K8_0402 | 2 | R49 R130 | SMD0402 | Digi-Key | 541-15.8KLCT-ND | Vishay Dale | CRCW040215K8FKED | RES, 15.8K OHM, 1/16W, 1%, 0402, SMD, | 15K8
16K5_0402 | 1 | R177 | R_SM0402 | Digi-Key | A102643CT-ND | TE Connectivity | 5-1879215-5 | RES, 16.5K OHM, 1/16W, 0.1%, 0402, SMD, | 16K5
22K1_0402 | 1 | R132 | SMD0402 | Digi-Key | 311-22.1KLRCT-ND | Yageo | RC0402FR-0722K1L | RES, 22.1K, OHM, 1/16W, 1%, 0402, SMD, | 22K1
24K9_0402 | 1 | R51 | SMD0402 | Digi-Key | 1276-3454-1-ND | Samsung Electro-Mechanics America, Inc | RC1005F2492CS | RES 24.9K OHM 1/16W 1% 0402 | 24k9
28K_0402 | 2 | R50 R131 | SMD0402 | Digi-Key | 311-28.0KLRCT-ND | Yageo | RC0402FR-0728KL | RES, 28.0K, OHM, 1/16W, 1%, 0402, SMD, | 28K
33K_0402 | 1 | R282 | R_SM0402 | Digi-Key | RHM33KCDCT-ND | Rohm Semiconductor | MCR01MRTF3302 | RES SMD 33K OHM 1% 1/16W 0402 | 33K
75K_0402 | 1 | R175 | R_SM0402 | Digi-Key | RMCF0402FT75K0CT-ND | Stackpole Electronics Inc | RMCF0402FT75K0 | RES 75K OHM 1/16W 1% 0402 | 75k
100K_0402 | 3 | R26 R168 R179 | R_SM0402 | Digi-Key | 311-100KJRCT-ND | Yageo | RC0402JR-07100KL | RES, 100K OHM, 1/16W, 5%, 0402, SMD, | 100K
100K_0402 | 4 | R43 R48 R171 R203 | R_SM0402 | Digi-Key | 311-100KJRCT-ND | Yageo | RC0402JR-07100KL | RES, 100K OHM, 1/16W, 5%, 0402, SMD, | 100K
348K_0402 | 2 | R180 R181 | R_SM0402 | Digi-Key | 1276-4247-1-ND | Samsung Electro-Mechanics America, Inc | RC1005F3483CS | RES, 348K OHM, 1/16W, 1%, 0402, | 348K
RA4_22R | 7 | R53 R54 R55 R204 R205 R206 R207 | R_array | Digi-Key | RES ARRAY, 22 OHM, 4 RES, 0804, | Yageo | YC124-JR-0722RL | YC124J-22CT-ND | 22R
SW_TACTILE | 2 | SW2 SW4 | SW_B3U-1000P | B3U-1000P | Digi-Key | Omron Electronics Inc-EMC Div | SW1020CT-ND | SWITCH, TACTILE, SPST-NO, 0.05A, 12V, | SW_Tactile
SW_TACTILE | 1 | SW3 | SW_B3U-1000P | B3U-1000P | Digi-Key | Omron Electronics Inc-EMC Div | SW1020CT-ND | SWITCH, TACTILE, SPST-NO, 0.05A, 12V, | SW_Tactile
SW_DIP_4POLES | 1 | SW1 | SW_DIP_4poles | Digi-Key | SW1080-ND | Omron Electronics Inc-EMC Div | A6H-4101 | SWITCH DIP 4POLES STD SMD 24V | SW_4way
SW_ON-OFF | 1 | SW5 | Switch_On_Off | Digi-Key | CKC5102-ND | C&K Components | L102021ML04Q | SWITCH SLIDE, SPDT, 4A, 125V, | SW_On-Off
TP | 4 | TP1 TP2 TP4 TP5 | ~
NCP380HSN05AAT1G | 3 | U4 U5 U6 | 5-TSOP | Digi-Key | NCP380HSN05AAT1GOSCT-ND | ON Semiconductor | NCP380HSN05AAT1G | IC CURRENT LIMIT SWITCH 5-TSOP | NCP380HSN05AAT1G
ADF4002 | 1 | U2 | LFCSP 20 | Digi-Key | ADF4002BCPZ-RL7CT-ND | Analog Devices Inc | ADF4002BCPZ-RL7 | IC, PLL, FREQUENCY, SYNTH, 20-LFCSP, | ADF4002
LP5900SD-3.3 | 1 | U8 | SC70 | Digi-Key | LP5900SD-3.3/NOPBCT-ND | NATIONAL SEMICONDUCTOR | LP5900SD-3.3/NOPB | IC REG, LDO, 3.3V, 0.15A, 6WSON, | LP5900SD-3.3
SC4524 | 2 | U3 U7 | SOIC-8 | Farnell | 1892639 | SEMTECH | SC4524CSETRT | IC, DC-DC CONV, 2MHz, 8-SOIC | SC4524
ADCS7476AIMF | 2 | U9 U10 | SOT-23-6 | Digi-Key | ADCS7476AIMF/NOPBCT-ND | Texas Instruments | ADCS7476AIMF/NOPB | IC ADC 12BIT 1MSPS SOT-23-6
U.FL | 1 | X1 | U.FL | Digi-Key | WM5587CT-ND | Molex Inc | 734120110 | CONN UMC RCPT STR 50 OHM SMD
TCXO_19.2MHZ | 1 | XO1 | 4-SMD | 405C35B19M20000 | CRYSTAL 19.200000MHZ, 13PF, SMD, | CTS-Frequency Controls | CTX648CT-ND | Digi-Key | 19.2MHz
TCXO_12MHZ_7M | 1 | XO2 | 4-SMD | 887-1316-1-ND | 7M-12.000MEEQ-T | TXC CORPORATION | CRYSTAL, 12MHZ, 10PF, SMD, | Digi-Key | 12MHz
TCXO_25MHZ_ABM8 | 1 | XO3 | 4-SMD | 535-9140-1-ND | ABM8-25.000MHZ-B2-T | ABRACON | CRYSTAL, 25MHZ, 18PF, SMD, | Digi-Key | 25MHz
TCXO_25MHZ_ABM8 | 1 | XO4 | 4-SMD | 535-9140-1-ND | ABM8-25.000MHZ-B2-T | ABRACON | CRYSTAL, 25MHZ, 18PF, SMD, | Digi-Key | 25MHz | NOFIT
RACON_TXCO_PLUTO+ | 1 | XO5 | SMD_TXCO_Pluto+ | 30.72MHz, RPT7050A, Pluto+, | E6245LF | E6245LF | Rakon | Rakon | E6245LF_30.72MHz

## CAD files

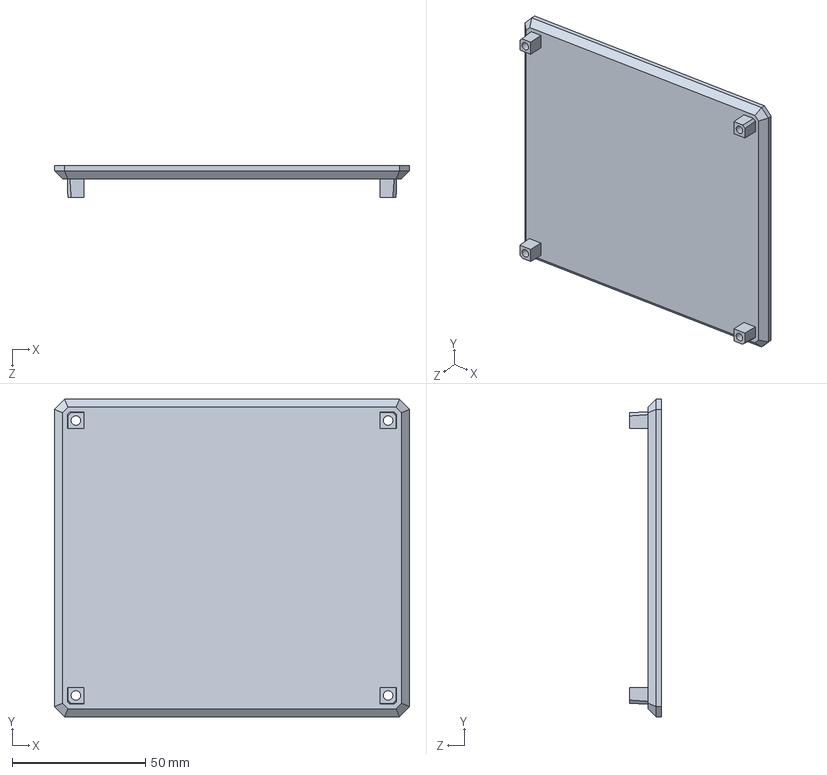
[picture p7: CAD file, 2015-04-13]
hardware/STREAM/v2/v2r1/Case/STREAM_enclosure_base.SLDPRT
133.0 x 119.0 x 12.0 mm

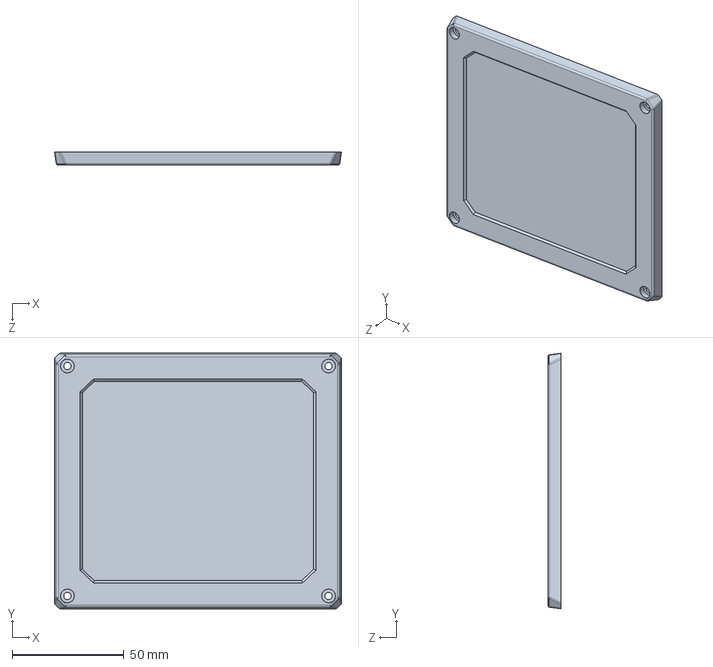
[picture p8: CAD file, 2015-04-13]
hardware/STREAM/v2/v2r1/Case/STREAM_enclosure_top.SLDPRT
128.6 x 114.6 x 6.00 mm

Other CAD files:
apps/lms7_usb_distro_01v/gateware/qii_projects/uStream_mrf7_trx_restored/signal_tap/pll_phase.stp
apps/lms7_usb_distro_01v/gateware/qii_projects/uStream_mrf7_trx_restored/signal_tap/phy_clk.stp
hardware/STREAM/v2/v2r1/Case/STREAM_enclosure_base.IGS
hardware/STREAM/v2/v2r1/Case/STREAM_enclosure_top.IGS

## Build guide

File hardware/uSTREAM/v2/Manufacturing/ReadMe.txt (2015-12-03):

Board Description
-----------------

board designation           : uSTREAM
board version		    : v2	
board type                  : Lead Free
board size                  : 122.6 mm x 45.8 mm
board thickness             : 1.6 mm +/- 10 %
board material              : IT-180A
number of layers            : 12

Top layer copper foil thickness: 17.5 um
Dielectric thickness between Top layer and 2nd, Bottom and 11th layers: 173 um (6.8 mils)
Dielectric between Top layer and 2nd, Bottom and 11th layers relative permittivity (Er): 4.2

minimum finished hole size  :  200 um
minimum spacing             :  100 um
minimum track width         :  100 um

drill diameters             : finished hole

plating finish (both sides) : immersion gold
                              0.05-0.10 um of gold over
                              2.50-5.00 um of nickel

Important Notes
---------------

DRCs must be run on Gerber files before building boards.

All through hole vias may be plated shut.

Solder mask : white, both sides.

Silkscreen : black epoxy ink, both sides.

Electrical test : 100 % netlist.

Boards are to be individually bagged.

Design software used:  KiCad

Controlled Impedance
--------------------
  * 90 Ohm coupled microstrip line (Top, Bottom layers) track width 0.3 mm

Board Stackup
----------------

 Solder Paste Front		: uSTREAM-F_Paste.gtp
 Silk Screen Front		: uSTREAM-F_SilkS.gto
 SolderMask Front		: uSTREAM-F_Mask.gts

1. Front Layer			: uSTREAM-F_Cu.gtl
2. Inner 10			: uSTREAM-Inner10_Cu.gbr 
3. Inner 9			: uSTREAM-Inner9_Cu.gbr
4. Inner 8		        : uSTREAM-Inner8_Cu.gbr
5. Inner 7	                : uSTREAM-Inner7_Cu.gbr
6. Inner 6		        : uSTREAM-Inner6_Cu.gbr
7. Inner 5	                : uSTREAM-Inner5_Cu.gbr
8. Inner 4                      : uSTREAM-Inner4_Cu.gbr
9. Inner 3                      : uSTREAM-Inner3_Cu.gbr
10. Inner 2                     : uSTREAM-Inner2_Cu.gbr
11. Inner 1                     : uSTREAM-Inner1_Cu.gbr																
12. Back Layer			: uSTREAM-B_Cu.gbl

 SolderMask Back		: uSTREAM-B_Mask.gbs
 Silk Screen Back		: uSTREAM-B_SilkS.gbo
 Solder Paste Back      	: uSTREAM-B_Paste.gbp

--------------------------------------------------
 PCB edges           	: uSTREAM-Edge_Cuts.gbr

 Drill map            	: uSTREAM-drl_map.pho
         	 	: uSTREAM-NPTH-drl_map.pho

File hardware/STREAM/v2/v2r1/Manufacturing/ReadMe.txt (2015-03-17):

Board Description
-----------------

board designation           : STREAM
board version		    : v2 r1	
board type                  : Lead Free
board size                  : 130 mm x 145 mm
board thickness             : 1.6 mm +/- 10 %
board material              : IT-180A
number of layers            : 12

Top layer copper foil thickness: 17.5 um
Dielectric thickness between Top layer and 2nd layer: 173 um (6.8 mils)
Dielectric between Top layer and 2nd layer relative permittivity (Er): 4.2

minimum finished hole size  :  200 um
minimum spacing             :  100 um
minimum track width         :  100 um

drill diameters             : finished hole

plating finish (both sides) : immersion gold
                              0.05-0.10 um of gold over
                              2.50-5.00 um of nickel

Important Notes
---------------

DRCs must be run on Gerber files before building boards.

All through hole vias may be plated shut.

Solder mask : white, both sides, halogen free.

Silkscreen : black epoxy ink, halogen free, both sides.

Electrical test : 100 % netlist.

Boards are to be individually bagged.

Design software used:  KiCad

Controlled Impedance
--------------------

  * 100 Ohm coupled microstrip line (Top layer) track width 0.28 mm

Board Stackup
----------------

 Solder Paste Front		: Stream-F_Paste.gtp
 Silk Screen Front		: Stream-F_SilkS.gto
 SolderMask Front		: Stream-F_Mask.gts

1. Front Layer			: Stream-F_Cu.gtl
2. Inner 1                      : Stream-Inner1_Cu.gbr
3. Inner 2                      : Stream-Inner2_Cu.gbr
4. Inner 3                      : Stream-Inner3_Cu.gbr
5. Inner 4                      : Stream-Inner4_Cu.gbr
6. Inner 5	                : Stream-Inner5_Cu.gbr
7. Inner 6		        : Stream-Inner6_Cu.gbr
8. Inner 7	                : Stream-Inner7_Cu.gbr
9. Inner 8		        : Stream-Inner8_Cu.gbr	
10. Inner 9			: Stream-Inner9_Cu.gbr
11. Inner 10			: Stream-Inner10_Cu.gbr 																
12. Back Layer			: Stream-B_Cu.gbl

 SolderMask Back		: Stream-B_Mask.gbs
 Silk Screen Back		: Stream-B_SilkS.gbo
 Solder Paste Back      	: Stream-B_Paste.gbp

--------------------------------------------------
 PCB edges           	: Stream-Edge_Cuts.gbr
 Drawings		: MYRIAD_RF-Dwgs_User.gbr

 Drill map            	: Stream-drl_map.pho
         	 	: Stream-NPTH-drl_map.pho

Reports folder
--------------
                  
Stream.net
Stream-drl.rpt
Stream.cmp
Stream.rpt

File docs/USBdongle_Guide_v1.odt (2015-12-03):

Lime Microsystems Ltd


Surrey Technology Centre

Occam Road

Surrey Research Park

Guildford, Surrey GU2 7YG

United Kingdom

Tel: +44 (0) 1483 685 063

Fax: +44 (0) 1428 656 662

e-mail: enquiries@limemicro.com

LMS6002/LMS7002

USB Dongle User Guide

- User guide to configure dongle with lms_suite and Raspbian OS -

REVISION HISTORY

The following table shows the revision history of this document:

Date | Version | Description of Revisions
01/12/15 | 1.0 | Initial version

Table of Contents

# Introduction

USB dongle consist of uSTREAM and uMyriadRF6002 or uMyriadRF7002. It is a low cost, software defined radio (SDR) platform, based on LMS6002D/LMS7002M transceiver and Altera Cyclone IV FPGA. The platform connects to a standard PC via the USB3 interface and turns it to a universal wireless communication tool.

The highly flexible LMS6002D/LMS7002M transceiver enables developers to work on the wide range of wireless communications applications in industry, education and research, which are used in a frequency range from 300MHz to 3.8GHz (LMS6002D) and 100kHz to 3.8GHz (LMS7002M).

The USB dongle is an open source platform and all example applications/software is available to download from myriadrf.org website [link (https://myriadrf.org/)].

This document provides the following information:

- SDR hardware description
- Programming with FX3 firmware and running FPGA bitstreams
- Working with Raspberry Pi

# Complete Development Package

Complete USB dongle content showed in Figure 1.

Figure 1 Complete USB dongle package

Development kit content:

- uSTREAM board and uMyriadRF6002 or uMyriadRF7002 board
- 2 x UFL to SMA cable
- USB stick containing:
  - lms-suite GUI and register setup for LMS6002D/LMS7002M transceiver
  - FPGA demo bitstreams and project design files
  - USB3 controller drivers
  - Waveforms
  - Windows drivers
  - Raspbian OS scripts

# uSTREAM Key Features

The main uSTREAM components are highlighted in the Figure 2.

Figure 2 uSTREAM components

- FPGA Features
  - Cyclone IV EP4CE10F17C8N device in 256-pin FBGA
  - 10’320 LEs
  - 414 Kbits embedded memory
  - 23 embedded 18x18 multipliers
  - 4 PLLs
- FPGA Configuration
  - JTAG mode configuration
  - Serial mode configuration via Cypress FX3
- Memory Devices
  - 512M (32M x 16) bit DDR2 SDRAM
- USB Interface
  - Cypress FX3 Supper Speed USB 3rd generation controller (CYUSB3013)
- Connections
  - 40-pin Raspberry Pi socket
- Clock System
  - 30.72MHz on board TCXO
  - 8-bit DAC (TCXO frequency adjustment)
- Board Size 31mm x 108mm (1.22” x 4.25”)

## USB Dongle architecture

The digital signals are driven from the PC via USB3.0 controller (or Raspberry Pi connector), Altera FPGA and to the DAC within the LMS6002D to produce analog I&Q output, then mixed with an adjustable frequency RF carrier through the quadrature modulator. The resulting RF signal is transmitted to the analyser through the TX RF output, see Figure 3.

The incoming RF signal is converted to baseband through the quadrature de-modulator, digitized through the ADC, processed in the FPGA and sent to the PC via USB3.0 controller (or Raspberry Pi connector). The digitized signal can be analysed with LimeSuite software.

uSTREAM

uMyriadRF

6002/7002

TXRF TXdig

RXRF RXdig

connector

Raspberry Pi connector

USB3.0 A connector

Altera

Cyclone IV

FX3

USB3.0 MCU

FLASH

DDR2 SDRAM

CLKs

circuit

Figure 3. USB dongle block diagram

The TCXO frequency (+/- 100 Hz) can be adjusted via FPGA to correct for the frequency error.

# Getting Started with USB dongle

The USB dongle comes with LimeSuite software, which enables to control the LMS6002D or LMS7002M transceiver, run the “FFTviewer” to analyse the ADC spectrum, load wanted waveforms to FPGA. Two example waveforms are available in the kit:

- Single tone generated in the digital domain by a programmable logic-based
- W-CDAM TM1 with 64ch waveform

## DEMO Setup

The demo setup is showed in Figure 4 . This demo uses single control software “lms-suite.exe” to control USB dongle.

Figure 4 Demo Setup for USB dongle

## DEMO Procedure

The DEMO procedure is common for both uMyriadRF6002 and uMyriadRF7002.

Steps are showed below:

1. Connect USB dongle to PC/Laptop
2. Connect lms-suite.exe software to the dongle
3. Setup USB dongle by loading register pre-set file
4. Load waveform for Tx Path
5. Run FFTviewer to analyse receiver

### Connect USB dongle to PC/Laptop

The USB dongle comes preprogrammed and ready to use. Once board is connected to PC or laptop, after few seconds firmware will load from memory and LD6, LD7 will lit and LD2, LD5 start flashing indicating that the board is ready for operation.

### Connect lms-suite.exe software to the dongle

When DEMO setup is ready, run the “lms-suite.exe” software, select Options, Communication Settings in top menu. New pop-up window should appear. Select COM port dedicated to the USB dongle. See figure Figure 5.

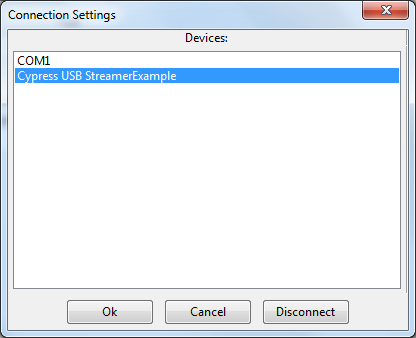
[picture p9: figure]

Figure 5 Comunicaton port selection for USB dongle

When board is successfully connected, you should see the indication in bottom of the main GUI window, see figure Figure 6.

Figure 6 lms7suite board connections indication

NOTE: If Communication Setting window shows up as empty, install windows drivers for the board. Please follow the procedures described in the chapter “USB3 Windows driver installation procedure USB3 Windows driver installation procedure”.

### Setup USB dongle by loading LMS6002D/LMS7002M register pre-set file

When board is connected to the lms_suite software, the registers for the transceiver IC can be configured by loading the configuration file. In order to do that, press Open button in the GUI front panel. See Figure 7.

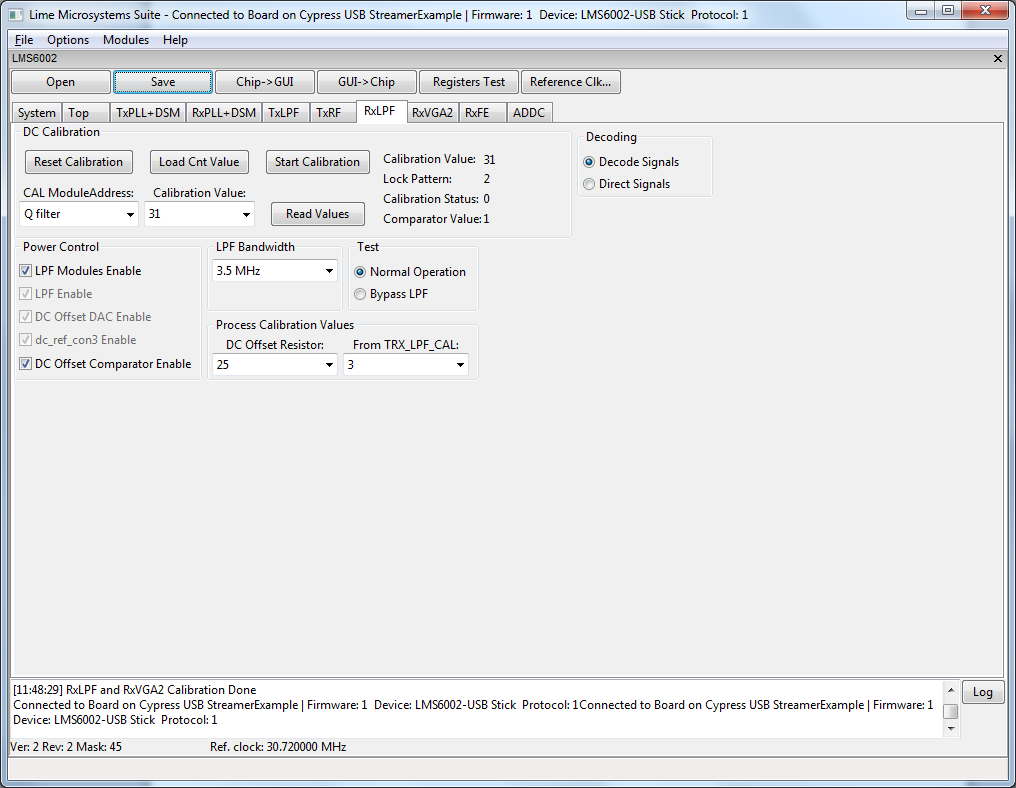
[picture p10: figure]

Figure 7 Select the pre-set file for transceiver

Select the lms6usb_reguister_settings.ini file in the ..\ lms6_usb_distro_03v\gui location, and press OPEN (for LMS7002M - lms7usb_reguister_settings.ini file in the ..\ lms7_usb_distro_01v\gui location).

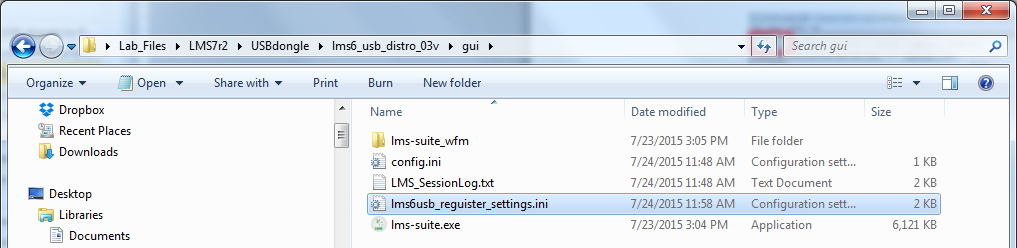
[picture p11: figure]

Figure 8 Select the lms6usb_reguister_settings.ini file

In order for the changes to take effect press GUI Chip, as shown below in .

At this point you should see the TX LO at 2140 MHz on analyser screen.

NOTE: If TX LO appears to be not locked, select the TxPLL+ DSM tab on the GUI, press Calculate and Tune.

NOTE: The register pre-set file configures transceiver to transmit 2140 MHz and receive signal at 1950 MHz.

### Load waveform for Tx Path

The programed FPGA is acting as waveform player for LMS6002D/LMS7002M transceiver. In order to load the waveform, select Modules from top menu, then FPGA Controls from the drop down menu. See Figure 9.

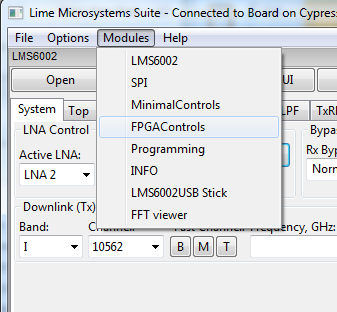
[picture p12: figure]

Figure 9 Select FPGA Control window

New window will appear in the bottom of the GUI, offering you to load supplied waveforms or custom waveforms. Please select to load WCDMA waveform by clocking on W-CDMA button. See Figure 10.

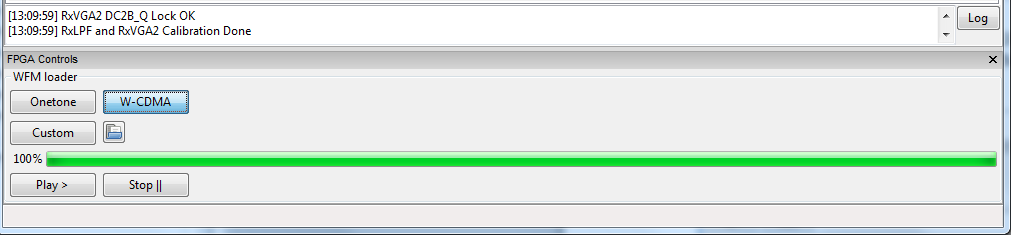
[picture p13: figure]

Figure 10 Waveform selection

### Run FTTviewer to analyze receiver spectrum

FFTviewer module is a part of lms_suite software. To run FFTviewer, go to top menu, select Modules and choose FFTviewer.

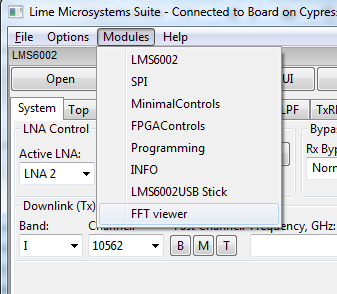
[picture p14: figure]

Figure 11 lms_suite module menu to select FFTviewer

FFTviewer control window will appear. Before start capturing data, set the Sampling frequency, select windowing function and press Start. See Figure 12.

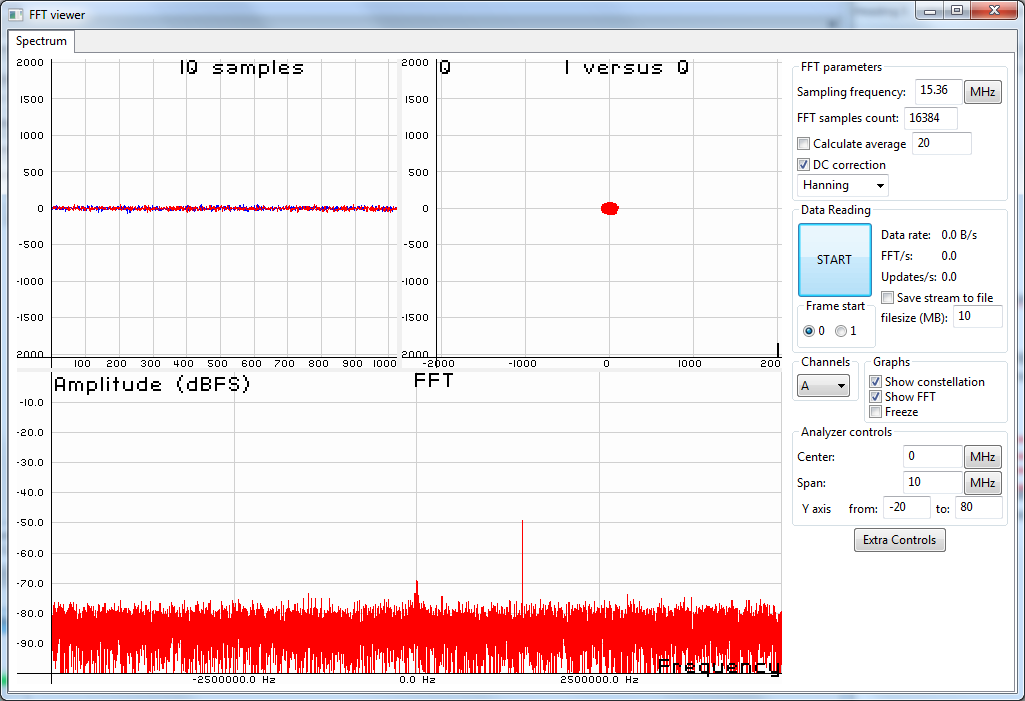
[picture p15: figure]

Figure 12 FFTviewer Controls

At this point, the FFTviewer start capturing data. Connect the generator to USB dongle receiver path. In the Figure 13 showed the FFTviewer data capture with 1 MHz CW signal offset from LO.

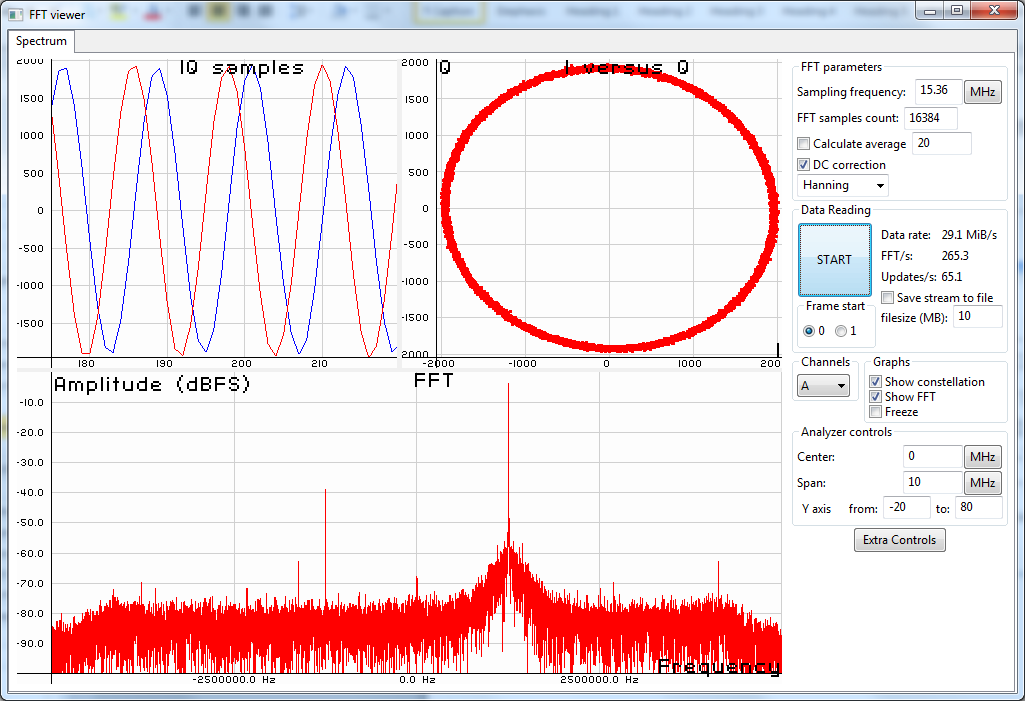
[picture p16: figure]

Figure 13 FFTviewer window in operation

# Connecting USB dongle to Raspberry Pi

The USB dongle has an option to connect to Raspberry Pi board through 40-pin connector, as shown in the Figure 14.

Figure 14. USB dongle (uMyriadRF6002 ver.) connected to Raspberry Pi

## Controlling USB dongle (uMyriadRF6002 version)via Raspbian OS

Before connecting both board together, the FPGA bitsream has to be updated. To do that, please follow the instructions showed in “Load bitstream to FPGALoad bitstream to FPGA” chapter, and load the …/RPi_prog/LMS6002spi_150721.rbf file. This enables the SPI interface control for LMS6002D chip through the Raspberry Pi connector.

### Enabling Raspberry Pi SPI interface

Plug the USB dongle on the Raspberry Pi and power ON. Once Raspbian OS is loaded, follow the steps below to setup up the SPI interface:

1. Use Raspberry Pi Software configuration tool - in LXTerminal * run command:

sudo raspi-config

2. Enable SPI interface through Advanced options. For detailed guidance please use “Enabling The SPI Interface On The Raspberry Pi” tutorial from this [link (http://www.raspberrypi-spy.co.uk/2014/08/enabling-the-spi-interface-on-the-raspberry-pi/)].
3. Set up the SPI interface on the Raspberry Pi Computer with python. The detailed constructions can be found in the “Simple SPI on Raspberry Pi” tutorial from this [link (http://www.100randomtasks.com/simple-spi-on-raspberry-pi)].

*NOTE: It is strongly recommended to update LXTerminal tool to the latest version, to do that select Advanced -> Update in start menu.

### Run Python script from command line

Copy LMS6002spi_latest.py and TXsetup_latest.py to Python SPI development directory:

pi/py-spidev/

Then run TXsetup script – in LXTerminal run command:

cd /home/pi/py-spidev

sudo python TXsetup_latest.py

See Figure 15

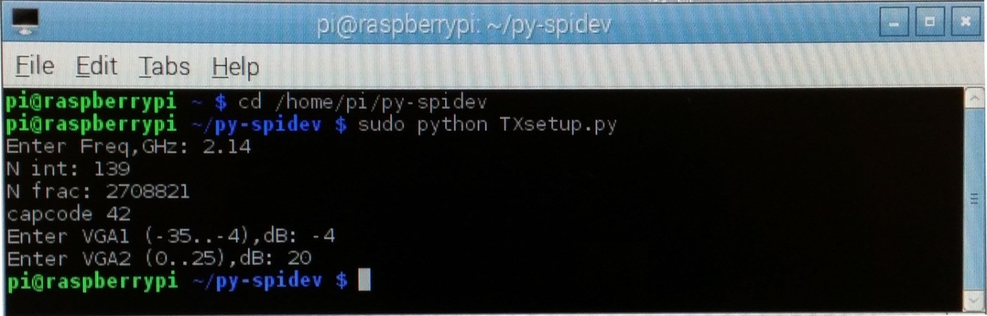
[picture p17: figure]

Figure 15 LMS6002D TX setup using Raspberry Pi command line

This will configure LMS6002D chip to transmit LO at 2140MHz as shown in the Figure 16.

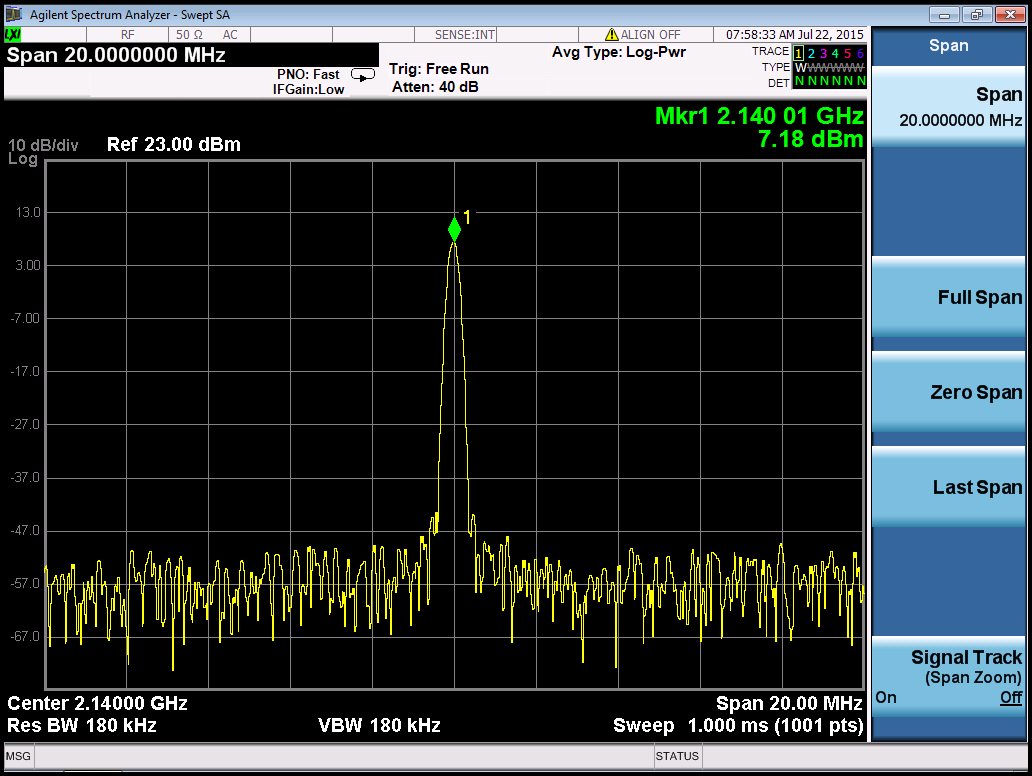
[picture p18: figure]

Figure 16 TXsetup.py sets LMS6002D LO to 2.14GHz

Also LMS6002D registers can be set by command line running LMS6002spi_150721.py script.

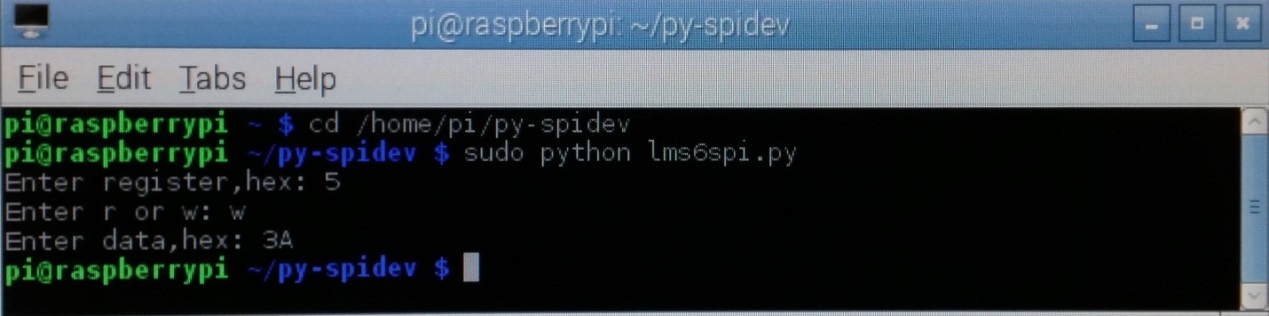
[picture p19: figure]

Figure 17 LMS6002D registers setup using Raspberry Pi command line

# Single-board PCs suitable for USB dongle

Table 1. Single-board PCs

Single-board PC | Connection to USB dongle | Comments
Raspberry Pi (https://www.raspberrypi.org/) | 40-pin Pinheader
BeagleBoneBlack (http://www.ti.com/tool/beaglebk?DCMP=PPC_Google_TI&k_clickid=2dda6974-ff30-4db1-84c1-457b59fd3d32) | 2x 46-pin sockets | Adapter needed
Odroid-XU3 (http://www.hardkernel.com/main/products/prdt_info.php?g_code=G140448267127) | USB3.0 Host
Odroid-C1 (http://www.hardkernel.com/main/products/prdt_info.php?g_code=G141578608433) | 40-pin Pinheader
UDOO (http://www.udoo.org/) | 36-pin socket | Adapter needed
Cudieboard (http://cubieboard.org/) | 48-pin Pinheader | External dongle supply needed
Marsboard (http://www.marsboard.com/) | 2x 50-pin sockets | Adapter needed
A13-OLinuXino (https://www.olimex.com/wiki/A13-OLinuXino) | 40-pin Pinheader | Connect pin 39 to dongle’s 2 pin, external dongle supply needed

# Appendix I

This chapter guides through the USB3 interface installation for the USB dongle on Windows.

## FX3 microcontroller drivers installation

The communication between USB dongle and PC (lms_suite) is done via the USB3 interface. Initially, USB dongle comes with preprogramed drivers and ready to use. If new drivers require to be installed or firmware update, the steps have to be taken:

- Install windows drivers. Follow chapter “USB3 Windows driver installation procedure USB3 Windows driver installation procedure”.
- Install USB3 microcontroller drivers. Follow chapter “Firmware installation for USB microcontroller Firmware installation for USB microcontroller”.

## USB3 Windows driver installation procedure

When USB dongle is connected, follow the installation procedure below.

1. Press “Start Menu” and right click on “Computer”, select “Properties” and “Device Manager”.

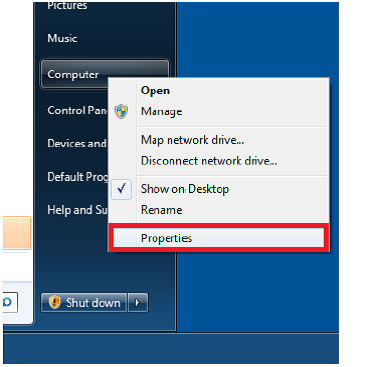
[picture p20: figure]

Figure 18 Open computer properties

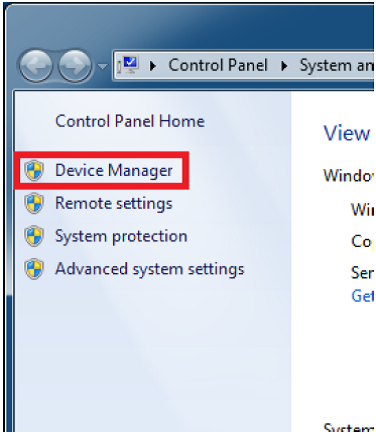
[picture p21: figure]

Figure 19 Open device manager

2. When USB dongle is plugged in, on “Device Manager” menu it appears as “WestBridge” under “Other devices”. Right click on the “WestBridge” and select “Update Driver Software”.

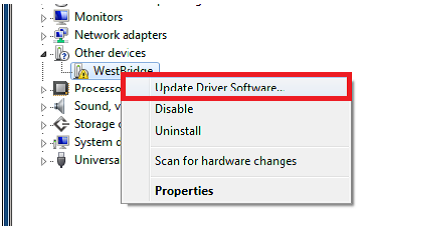
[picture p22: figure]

Figure 20 Update driver software

3. Select driver installation manually and choose driver from the following location:

..\lms6_usb_distro_03v\fx3\drivers\bin.

Choose the driver which is suitable for the operating system running:

- Windows XP (wxp)
- Windows Vista (vista)
- Windows 7 (win7)
- Windows 8 (win8)

CPU type:

- x86(32bit-i386)
- x64(64bit-amd64)

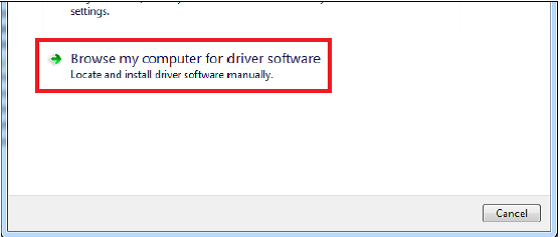
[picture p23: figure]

Figure 21 Browse for driver software

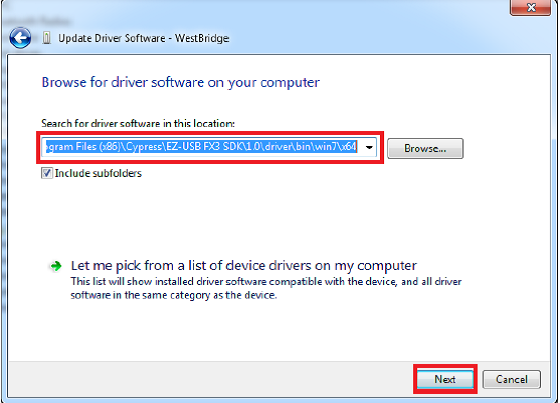
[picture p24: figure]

Figure 22 Select driver location

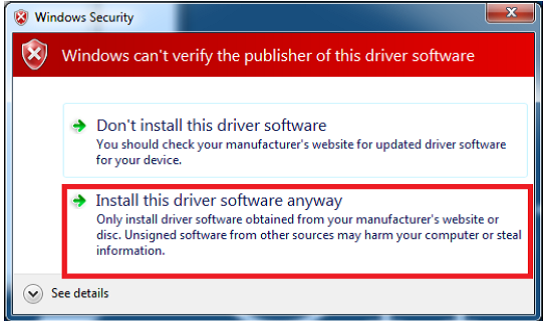
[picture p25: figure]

Figure 23 Confirm installation of unsigned driver

4. After successful installation “Cypress USB BootLoader” will appear under USB controller devices.

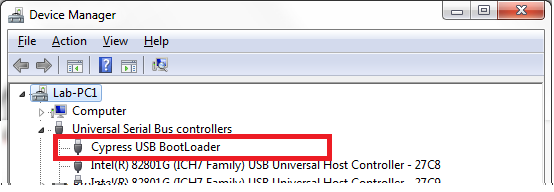
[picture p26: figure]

Figure 24 Device manager window after installation

NOTE: If you are using Windows 7 64 bit OS, you must disable Driver Signature Enforcement. To do this, Restart you PC, press F8 at startup and choose Disable Driver Signature Enforcement. This step is required to done once.

NOTE: If you are using Windows 8 or later, to disable driver signature enforcement manual can be found in this [link (https://learn.sparkfun.com/tutorials/disabling-driver-signature-on-windows-8/disabling-signed-driver-enforcement-on-windows-8)].

## Firmware installation for USB microcontroller

For USB microcontroller firmware installation, please use the “CyControl.exe” (..\lms6_usb_distro_03v\fx3\software folder).

Cypress FX3 USB microcontroller has an integrated boot loader, which starts automatically after power-up or reset.

If FLASH memory is empty or connector J5 (on uSTREAM) is open, USB3 microcontroller boots-up with factory firmware. Run the “USB Control Center” application and in the menu select "Cypress USB BootLoader" line as shown in Figure 25.

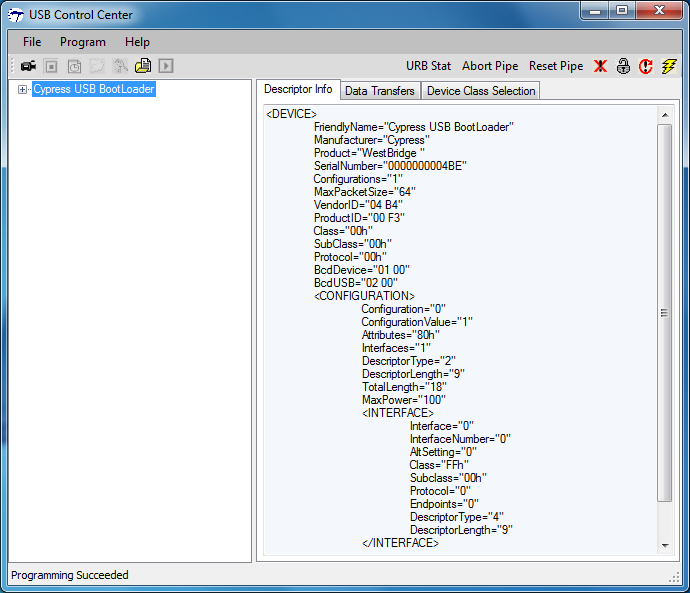
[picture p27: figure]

Figure 25 Default FX3 firmware, supplied by internal logic

There are two ways of uploading the firmware to USB3 microcontroller:

- Program internal RAM memory. Follow procedure described in chapter “Uploading firmware to the FX3 RAM Uploading firmware to the FX3 RAM”. The memory will be cleared after first power cycle.
- Program external FLASH memory connected to USB3 controller. Follow procedure described in chapter “Uploading firmware to empty FLASH Uploading firmware to empty FLASH”. The USB3 microcontroller will boot from FLASH memory after every power-on.

### Uploading firmware to the FX3 RAM

Start “CyControl.exe” application and select Cypress USB BootLoader as shown in Figure 25. Choose menu command Program FX3 RAM. In the new pop-up window, select lms6002-usb (GPIO PS, FLASH, compressed ) 2015 06 25.img file provided (..\\lms6_usb_distro_03v\fx3\firmware_img folder) and press Open. Status bar of the USB Control Center application will indicate Programming RAM. This message will change to the Programming succeeded after programming is done.

If you expand Cypress USB StreamerExample line in USB Control Center application now, you will see different USB configuration as shown in Figure 26.

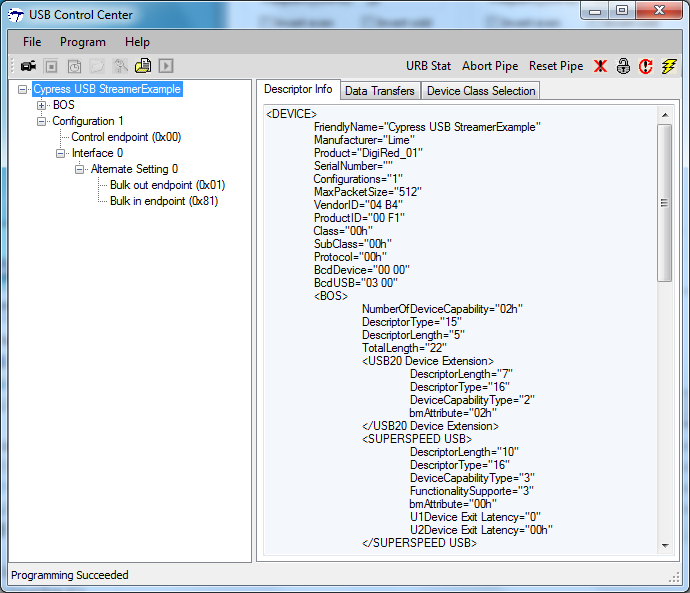
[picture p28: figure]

Figure 26 FX3 after custom firmware is downloaded

### Uploading firmware to empty FLASH

If external FLASH is empty, short the jumper J5 and connect USB dongle to the PC. Start “CyControl.exe” application and select Cypress USB BootLoader as shown in Figure 25. Choose menu command Program FX3 SPI FLASH. In the status bar you will see Waiting for Cypress Boot Programmer device to enumerate.... and after some time window will appear. Select provided lms6002-usb (GPIO PS, FLASH, compressed ) 2015 06 25.img file (..\lms6_usb_distro_03v \fx3\firmware_img folder) and press Open. Status bar of the USB Control Center application will indicate Programming of SPI FLASH in Progress…. This message will change to the Programming succeeded after FLASH programming is done.

NOTE: USB3 microcontroller mi will boot firmware uploaded to FLASH each time after power-on if jumper J5 is shorted.

### Uploading firmware to non-empty external FLASH memory

To update external FLASH memory with new firmware, follow these steps:

1. Disconnect USB dongle from USB port.
2. Make sure that jumper J5 is open.
3. Connect USB dongle to USB port.
4. Short jumper J5.
5. Do the steps described in section Uploading firmware to empty FLASH.

# Appendix II

This section describes how to load custom bitstream to USB dongle FPGA.

## Load bitstream to FPGA

The Altera Cyclone IV FPGA which sits on the USB dongle can be programmed using “lms7suite”software. To call FPGA programing function, go to Modules form top menu and select Programing form the drop down menu. See Figure 27.

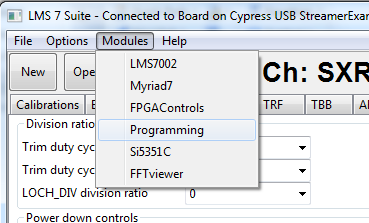
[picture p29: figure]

Figure 27 lms7suite module menu to select FPGA programing tool

New control section should appear in the bottom of the main window, as shown in the Figure 28.

Figure 28 FPGA programing tool interface

Software loads raw binary files (*.rbf) to FPGA and it offers couple options to do that, see Figure 29.

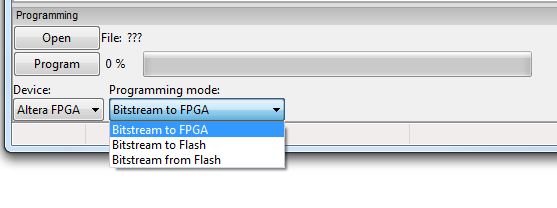
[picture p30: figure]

Figure 29 FPGA programing options

The programing functions are described below:

1. Bitstream to FPGA – this function loads selected *.rbf file from PC to FPGA. Select your wanted bitstream file by clicking Open and initiate FPGA programing by clicking on Program.
2. Bitstream to FLASH – this function loads selected *.rbf file from PC to external FPGA FLASH memory. Select your wanted bitstream file by clicking Open and initiate FLASH memory programing by clicking on Program.
3. Bitstream from FLASH - loads bitstream from external FPGA FLASH memory to FPGA. To initiate programing click on Program button.

The new massage will come up when the programing is finished.

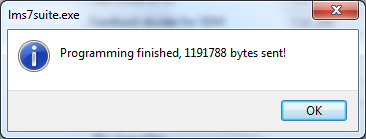
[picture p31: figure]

Figure 30 Successfully FPGA programing massage

USB Dongle User Guide

Version: 1.0 Last modified: 01/12/2015

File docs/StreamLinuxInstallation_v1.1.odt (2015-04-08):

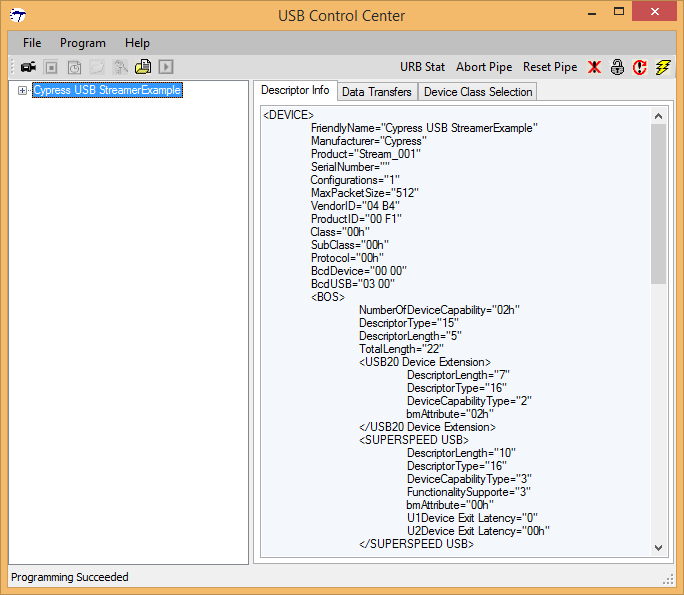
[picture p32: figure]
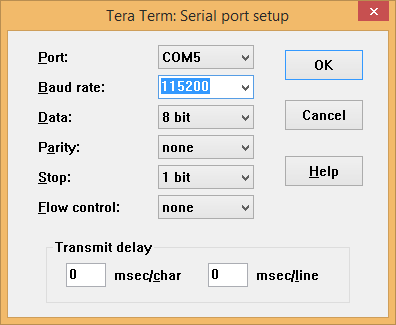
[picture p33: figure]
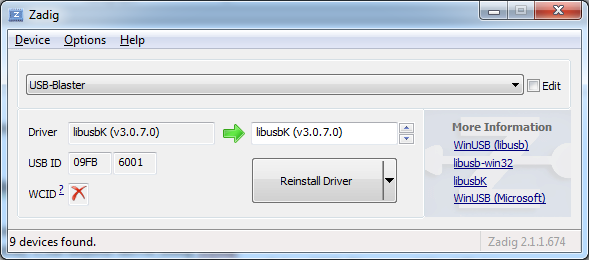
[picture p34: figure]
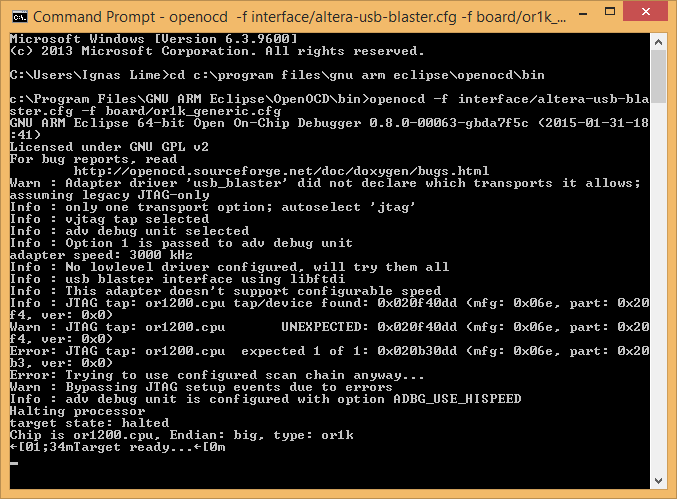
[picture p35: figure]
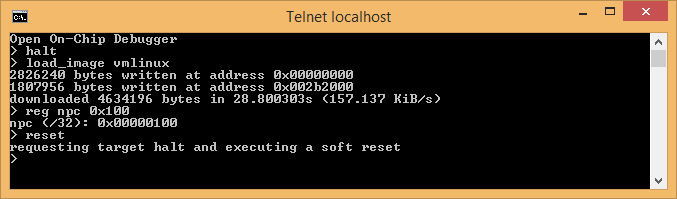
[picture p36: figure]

Lime Microsystems Limited

Surrey Technology Centre

Occam Road

The Surrey Research Park

Guildford, Surrey GU2 7YG

United Kingdom

Tel: +44 (0) 1483 685 063

Fax: +44 (0) 1428 656 662

e-mail: enquiries@limemicro.com

STREAM Development kit

User Guide

- User Guide for Linux OS Installation -

REVISION HISTORY

The following table shows the revision history of this document:

Date | Version | Description of Revisions
27/02/2015 | 1.0 | Initial version
03/04/2015 | 1.1 | Added document licence info (Creative Commons Attribution 3.0 Unported)

Table of Contents

Table of Figures

# Requirements

Required Software:

- CyControl (Cypress USB control center)
- OpenOCD (>=0.8.0) (http://sourceforge.net/projects/gnuarmeclipse/files/OpenOCD/)
- Tera Term (http://logmett.com/index.php?/download/tera-term-485-freeware.html)
- Zadig (http://zadig.akeo.ie/)

Required Hardware:

- Altera USB Blaster
- 3.3V USB-to-Serial cable (http://www.digikey.com/product-search/en?pv493=455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)
- USB A to microB cable

Current manual describes how to load Linux image to FPGA via FX3 controller.

Information regarding software architecture and links to source codes are available in \Stream\stream_openrisc_soc_v2\doc directory.

# Step by step instructions

## Step 1. Installing USB drivers

Use J2 USB3.0 to connect to PC.

To install Cypress FX3 USB3.0 (IC6) drivers navigate driver installer to \Stream\Stream_LMS7EVB_distro_05v\fx3\drivers\bin\

## Step 2. Load FX3 firmware

Run CyControl from \Stream\Stream_LMS7EVB_distro_05v\fx3\software

Press Program → FX3 → RAM → navigate to …\fx3\firmware_img\usb_trx_V2 → Open.

“Cypress USB BootLoader” should change to “Cypress USB StreamerExample”.

Figure . CyControl Cypress USB StreamerExample should appear

## Step 3. LMS7Suite for FPGA programming

Run LMS7Suite from \Stream\Stream_LMS7EVB_distro_05v\gui directory.

Go to Options → Connection Settings → Cypress USB StreamerExample (Stream) → OK

Now connection between FX3 controller and PC is set.

Now it is time to load RISC architecture in to FPGA: go to Programming section. Press Open and navigate to \Stream\stream_openrisc_soc_v2\bin\stream.rbf. Press Program.

Figure . FPGA programming via LMS7Suite

## Step 4. Serial connection setup

Connect 3.3V USB-to-Serial cable to J1 (FPGA GPIOs header).

Pin 1: FPGA RX pin (orange)

Pin 3: FPGA TX pin (yellow)

Pin 10: GND (black)

Establish connection using Tera Term via Serial Port.

Figure . Tera Term Serial Port setup

FPGA is not ready yet, so Terminal window is empty.

## Step 5. Altera USB Blaster

Connect Altera USB Blaster to J23 FPGA JTAG header.

Install USB-Blaster driver using Zadig.

Run Zadig → Options → List All Devices. Select USB-Blaster and libusbK driver.

Figure . Zadig driver installer

## Step 6. OpenOCD installation

Install OpenOCD.

Copy vmlinux (Linux image) from \stream_openrisc_soc_v2\bin to OpenOCD installation directory C:\Program Files\GNU ARM Eclipse\OpenOCD\bin

Run Windows Command Prompt.

Change current directory to OpenOCD installation directory:

cd C:\Program Files\GNU ARM Eclipse\OpenOCD\bin

Launch OpenOCD with:

Openocd –f interface/altera-usb-blaster.cfg –f board/or1k_generic.cfg

Figure . Launching OpenOCD

## Step 7. Installing Linux

Turn ON Windows Telnet (Control Panel → Programs → Turn Windows features on or off)

Open a new Command Prompt window and connect to the OpenOCD proxy with telnet localhost 4444.

Run the following command to load the Linux image halt; load_image vmlinux; reg npc 0x100; reset.

Figure . Loading Linux image

The Linux boot process should now start in the terminal connected to the serial console.

After the boot is complete you should be greeted by a message saying Please press Enter to activate this console.

Press Enter and you can start using Linux commands.

Figure . Linux loading completed

LMS7002EVB and Stream board User Guide

© Copyright 2015 Lime Microsystems CC BY 3.0 Version: 1.1

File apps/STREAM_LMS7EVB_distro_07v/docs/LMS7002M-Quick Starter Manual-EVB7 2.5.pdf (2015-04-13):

LMS7002M Quick Starter Manual for EVB7 kit

Lime Microsystems

Surrey Tech Centre
Occam Road
The Surrey Research Park
Guildford
Surrey GU2 7YG
United Kingdom
Tel: | +44 (0) 1483 685 063
Fax: | +44 (0) 1428 656 662
e-mail: | enquiries@limemicro.com

# LMS7002EVB Quick Start Manual

© Copyright 2014-2015 Lime Microsystems CC BY 3.0

Version: 2.5 Last modified: 04/13/2015

The information contained in this document is subject to change without prior notice. Lime Microsystems assumes no responsibility for its use, nor for infringement of patents or other rights of third parties. Lime Microsystems' standard terms and conditions apply at all times.

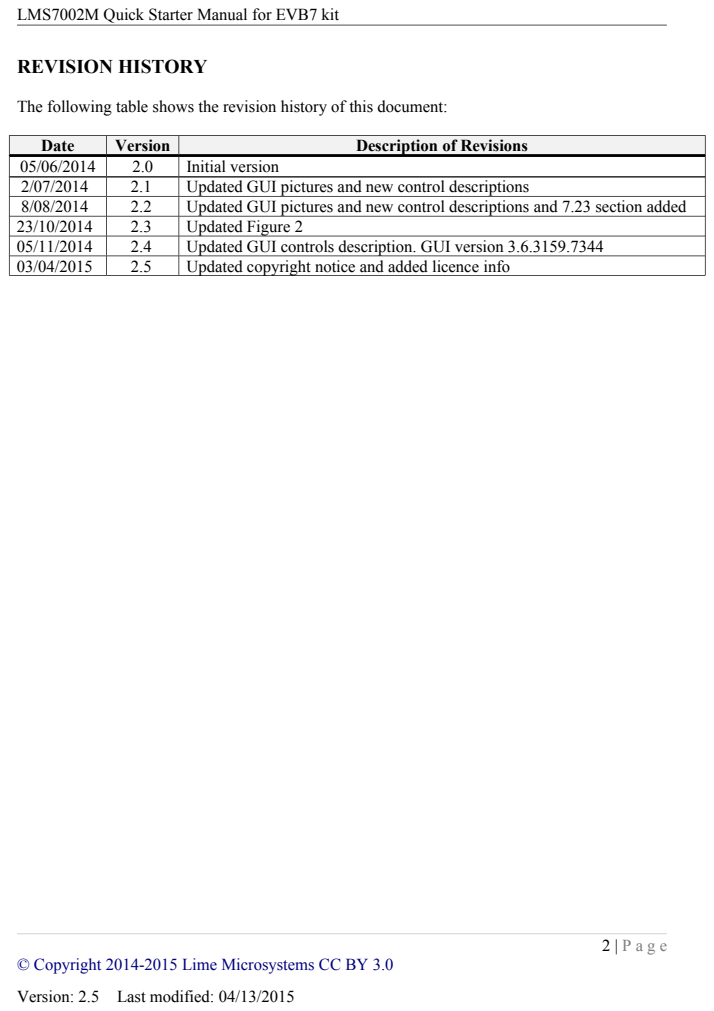
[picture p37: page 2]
REVISION HISTORY; Date; Version; Description of Revisions; Initial version; Updated GUI pictures and new control descriptions; Updated GUI pictures and new control descriptions and 7.23 section added; Updated Figure 2; Updated GUI controls description. GUI version 3.6.3159.7344; Updated copyright notice and added licence info

The following table shows the revision history of this document:

© Copyright 2014-2015 Lime Microsystems CC BY 3.0

# Contents

3 | P a g e
© Copyright 2014-2015 Lime Microsystems CC BY 3.0

4 | P a g e
© Copyright 2014-2015 Lime Microsystems CC BY 3.0

### 1.35 CDS | 72 1.36 BIST | 73 1.37 SPI | 74 1.38 Introduction | 77 1.39 Recommended Test Equipment | 77 1.40 Agilent MXG Setup | 78

1.40.1. Setting Common Mode Voltage | 78
1.40.2. Enabling the Arbitrary Waveform Generator | 79
1.40.3. Downloading *.wfm Files to the Signal Generator | 80
| 82
NOTICE OF DISCLAMER | 83

### Table of Figures

Figure 1 Development System Content | 9
Figure 2 Board block diagram | 11
Figure 3 Device Manager content | 14
Figure 4 Device properties | 15
Figure 5 Update Driver Wizard | 15
Figure 6 Hardware wizard. Install driver manually | 16
Figure 7 Check for new communication port | 17
Figure 8 GUI communication settings | 18
Figure 9 GUI detected device and firmware version | 19
Figure 10 Tx Test Setup | 21
Figure 11 SXT register setup procedure | 22
Figure 12 TBB register setup procedure | 23
Figure 13 Basic TX testing using DC offset resulting in LO leakage | 23
Figure 14 Basic TX testing using WCDMA modulation | 24
Figure 15 Rx Test Setup | 25
Figure 16 SXR register setup procedure | 26
Figure 17 SXR register setup procedure | 27
Figure 18 SXR register setup procedure | 28
Figure 19 RX analog output on Spectrum Analyser | 29
5 | P a g e
© Copyright 2014-2015 Lime Microsystems CC BY 3.0

6 | P a g e
© Copyright 2014-2015 Lime Microsystems CC BY 3.0

# Introduction

The Lime Development System is a comprehensive hardware and software combination that allows users to evolve and refine a wireless sub-system. It can be combined with a baseband processor such as an FPGA or DSP processor to develop a comprehensive wireless solution.

The EVB7 module is a high-speed wireless communication module, based on the LMS7002M fully programmable RF transceiver. It is designed to support 2G, 3G, 4G/LTE radio systems with both time-division duplex (TDD) and frequency-division duplex (FDD) applications, M2M and software defined radios. The wireless communication module covers the frequency range of 100 kHz to 3.8 GHz, including licensed and unlicensed bands. The channel bandwidth is programmable from less than 100 kHz to 108 MHz through a combination of analog and digital filtering via the easy-to-use GUI software.

The EVB7 provides system designers with the ability to connect the board to any type of baseband, FPGA or CPU and allow them to implement their ideas for various wireless communication applications.
This document describes how to make a quick start with the LMS7002M using the EVB7 module. Section begins by listing the contents of the Quick Start kit. Section gives a general description of the evaluation board features. Section describes the procedure for obtaining and installing the LMS7002M control software “Control LMS7002M” for both Windows and Linux platforms. Section describes how to connect and use the EVB and LMS7002M control software “Control LMS7002M” for the Quick Start example configurations. Section describes in detail the EVB connectors and hardware options. Section describes in detail how to use the
LMS7002M control software “Control LMS7002M”. Section 1.38 describes calibration procedures. Appendix 1 details the recommended test and measurement equipment, and how to set up the test equipment to work with EVB7 and the LMS7002M.
7 | P a g e
© Copyright 2014-2015 Lime Microsystems CC BY 3.0

# Development System Content

Figure 1 Development System Content

Complete development kit content consists of:
- Hardware
- 1 – LMS7002EVB v3 board
- 1 - Power supply cable that connects the EVB7 board to any lab power supply unit
- 1 - USB-A to Micro-USB-B cable
- USB stick with software
- Software:
- LMS7002M GUI “Control_LMS7002M”
- Windows drivers
- Documentation:
- Quick Starter Manual
- LMS7002M datasheet
- Complete PCB database
- Register map document
- Generator waveforms
8 | P a g e
© Copyright 2014-2015 Lime Microsystems CC BY 3.0

# Overview of the Development Board

Figure 2 Board block diagram

A photograph of the development board is shown in Figure 1. A block diagram of the board is shown in Figure 2. The connections are shown in blue, the LMS7002M chip is shown in green, and the other parts are shown in orange. The core of the board is the LMS7002M transceiver chip, which has multiple RF, analogue and digital interfaces.

The evaluation board includes RF matching networks for the LMS7002M. These matching networks include wideband transformers to allow operation over the entire frequency range. However, the matching networks have been optimized for operation over selected frequency bands and offer the best performance in these bands. Connectors are provided for 4 RF transmitter outputs and 6 RF receiver inputs. Further details of the matching networks are provided in section 1.16.5.

The evaluation board includes connectors for the baseband analogue differential receiver outputs and differential transmitter inputs. Additionally, on board high speed differential to single ended converters allow the EVB7 receivers to indirectly drive 50R test equipment such as spectrum analysers for baseband testing.

The evaluation board includes a clock generation block, which by default, is a standalone 30.72 MHz low phase noise TXCO. TXCOs at other frequencies can also be fitted and three different footprints are supported. The EVB7 can be easily modified to operate with external clock sources. It can also be synchronized to the standard 10 MHz reference of measurement equipment via an on board PLL. Details of the required changes on EVB7 are given in section 1.16.1 and 1.16.2.
9 | P a g e
© Copyright 2014-2015 Lime Microsystems CC BY 3.0

EVB7 includes two kinds of digital I/O, one for control only, and two for data and control.

The USB interface is used to control the LMS7002M SPI via the LMS7002M control software. The USB port is converted to SPI by an on board microcontroller.

The FMC connector or the 44 pin header can be used for the buffered digital interface and can be connected to compatible platforms such as the Lime “Stream” board. The Lime “Stream” board also provides connections to general purpose lab equipment such as pattern generators and logic analysers. A pin list for the digital interface can be found in section 1.15. The logic level for the digital interface can be set by modifying EVB7 and is described in section 1.16.4. Additionally these connectors can be used to control the SPI but require the board modifications described in 1.16.3.

A 7th order LC filter can be selected between the analogue output of the LMS7002M and its digital inputs by using the LMS7002M control software. This allows additional filtering at 100 kHz (IF BW) for 2G applications.

The board includes memory to work with the LMS7002M internal microcontroller. This is intended to provide calibration support for the LMS7002M and is currently under development. The memory is programmed via the LMS7002M control software and the USB/SPI interface.

Test points are provided for various test signals including the LMS7002M internal peak and RSSI detectors as well as various PLL test signals.

More detailed information on the connectors for the evaluation board can be found in section
1.14. Information about PCB options supported is in section 1.16.
10 | P a g e
© Copyright 2014-2015 Lime Microsystems CC BY 3.0

# Installing the LMS7002M Control Software

### 1.1 Introduction to installing the software

To operate the EVB7 board, the LMS7002M Control Software, “LMS7002M Control” has to be downloaded from http://www.limemicro.com and installed. The software consists of three parts.
- The main LMS7002M control Software, which provides a GUI to control the chip.
- The USB driver “USB to LMS7002M”, which provides an interface between the PC and the EVB7 SPI microcontroller.
- The EVB7 microcontroller firmware, which is preinstalled on the board prior to shipping.

Section 1.1 describes the how to download the software from the Lime Microsystems web page.

Sections 1.2, 1.3 and 1.4 describe the set up for the Windows Operating System. Section 1.2 describes the installing of the “USB to LMS7002M” driver. Section 1.3 describes the Windows OS set up. Section 1.4 describes how to identify which USB port is being used.

Section 1.5 describes installing the USB driver in a typical Linux distribution. Section 1.6 describes how to start the “LMS7002M Control Software”.

Section 1.7 describes how to connect the EVB7 with the “LMS7002M Control Software” via the USB interface.

A simple demonstration of the “LMS7002M Control Software” is given in section . A detailed description of the “LMS7002M Control Software” is given in section .

### 1.2 Downloading the Software

To get started with the EVB7 board control software, download the latest version from www.limemicro.com.

### 1.3 Windows USB Setup

The steps to setup “Control LMS7002M” software are as follows (please note that these steps may vary based on the specific version of Windows software being used and you may need to be logged in as Administrator to accomplish them):

1. Connect EVB7 board to your PC via the USB cable.
11 | P a g e
© Copyright 2014-2015 Lime Microsystems CC BY 3.0

2. Go to Control Panel > System > Device Manager
3. Locate USB to LMS7002M under Other devices and press right click to select Properties (Figure 3)

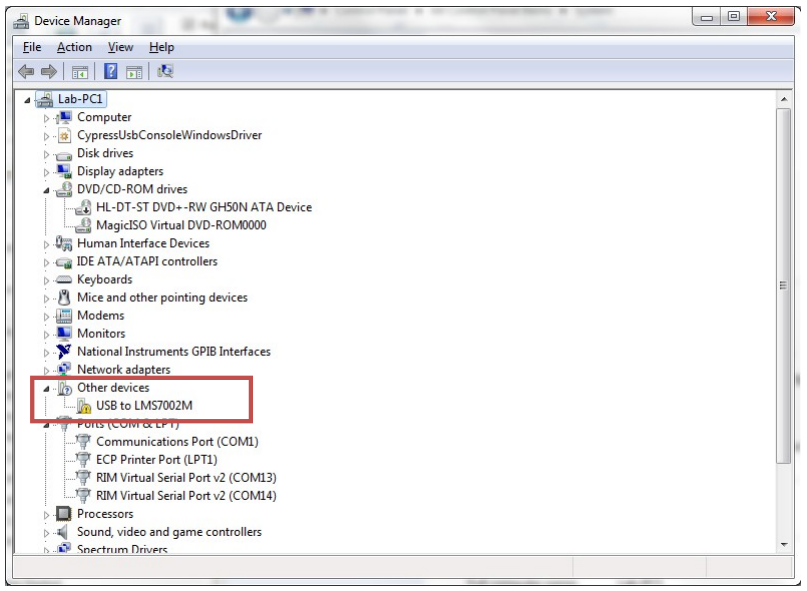
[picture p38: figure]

Figure 3 Device Manager content

4. When a new window pops-up press Update driver (Figure 4)
12 | P a g e
© Copyright 2014-2015 Lime Microsystems CC BY 3.0

Figure 4 Device properties

5. Select Browse my computer for driver software, locate the driver provided with EVB7 board and press Next (Figure 5)

Figure 5 Update Driver Wizard.

6. If the Windows Security window appears, select Install this driver software anyway (Figure 6)
13 | P a g e
© Copyright 2014-2015 Lime Microsystems CC BY 3.0

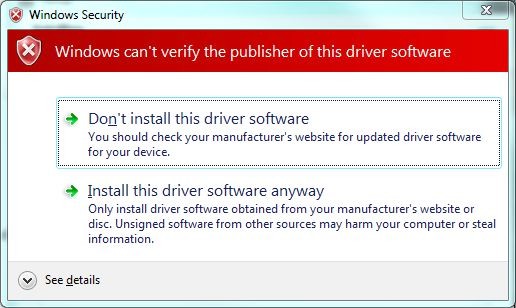
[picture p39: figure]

Figure 6 Hardware wizard. Install driver manually

Windows should proceed to install drivers at this stage. Generally, once the above steps have been taken for the EVB7, these steps do not need to be repeated.

IMPORTANT:
Before running the control software, unplug then plug your device back into your computer.
14 | P a g e
© Copyright 2014-2015 Lime Microsystems CC BY 3.0

### 1.4 Determining Serial Port

After driver installation, Windows will assign to your EVB7 board a serial port. To check your board serial port number, please follow these steps:

1. Go to Control Panel > System > Device Manager
2. Locate USB Virtual Serial Port under Ports (COM & LPT)

Note that in this system example it has enumerated as COM2 (Figure 7).

Figure 7 Check for new communication port

15 | P a g e
© Copyright 2014-2015 Lime Microsystems CC BY 3.0

### 1.5 Linux Setup

For Linux users, there is no need to install USB drivers, as the system will assign drivers automatically once the EVB7 board is connected to PC.

To determine port number the easiest is via the command line and type command:

$ setserial -g /dev/ttyS[0123]

### 1.6 Starting Control LMS7002M Software

Apply +5V to the board and start “Control LMS7002M” software. The application must be run under administrator privileges. To do that, right click on the “Control LMS7002M” icon and select Run as an Administrator. This will provide administrator privileges, which are required for EVB7 board communication via USB.

### 1.7 Connecting

Once the Windows driver is installed and the control software has been lunched, click on Options>Connection Settings. The Connection Setting windows will pop-up (Figure 8).

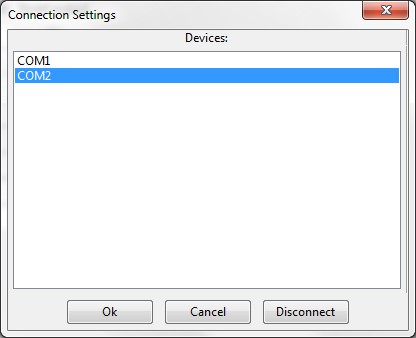
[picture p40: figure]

Figure 8 GUI communication settings.

Select the dedicated USB port number of the EVB board. In this case, it is COM2, and press OK.

16 | P a g e
© Copyright 2014-2015 Lime Microsystems CC BY 3.0

The GUI device name and firmware version will appear in the bottom (Figure 9), once connection with the board is established.

Figure 9 GUI detected device and firmware version

# Getting started with the EVB

### 1.8 Introduction to using the EVB7

The EVB7 allows powerful demonstrations of the LMS7002M transceiver. In this quick start guide, we demonstrate the board operating with analogue inputs and outputs. A future version is planned to demonstrate the board operating with digital inputs and outputs and the Lime “Speed” board.

Section 1.9 describes the set up of the transmitter, with section 1.9.1 describing how to set up the SXT (TX PLL) and section 1.9.2 describing how to set up the TX analogue baseband and RF tabs of the LMS7002M Control software. Section 1.11 describes the set up of the transceiver for basic tests, with section 1.11.1 describing how to set up the SXR (RX PLL) and section 1.11.2 and 1.11.3 describing how to set up the RX analogue baseband and RF tabs of the LMS7002M Control software.

The analogue quick start demonstration assumes the user has all the equipment listed in Appendix 1.39. Users with less equipment can use the set up of Section 1.13.

17 | P a g e
© Copyright 2014-2015 Lime Microsystems CC BY 3.0

### 1.9 Transmitter Setup and Basic Testing

To test the Tx path, the Agilent generator is used as an external baseband source. This is connected to the Tx path via the analog inputs and generates a WCDMA modulation signal at socket X1 (TX1_A) as shown in Figure 10. To generator settings are described in section 1.40 (Appendix A).

Figure 10 Tx Test Setup

### 1.9.1. SXT/SXR tab setup

After power up, connect the GUI to the board and select the SXT/SXR tab. To configure the Tx LO to 2140 MHz, do the following:

1. Select the B/SXT in the configuration channels window to control TxPLL
2. Enable Tx PLL VCO (Deselect).
3. Type the wanted frequency in Frequency, GHz box. In this case, 2140 MHz.
4. Press Calculate followed by Tune.

See Figure 11 below to check selections.

18 | P a g e
© Copyright 2014-2015 Lime Microsystems CC BY 3.0

Figure 11 SXT register setup procedure

### 1.9.2. TRF tab setup

The TRF tab controls the TX RF gain and output path. By default the Tx RF gain is set to maximum ( TXPAD gain control set to ‘0’) and TXFE output selection set to Band 1 ( to X1 on EVB7 board) as the output path. For this test, we are not going to change these settings.

### 1.9.3. TBB tab setup

In the TBB tab the baseband gain and filter bandwidth are controlled. Follow the instructions below set up TBB:

1. Select the A/SXR to control channel A.
2. Enabled Tx IQ analog input path to current amplifier.
3. Set Frontend gain to your wanted.
4. Configure the base band filter settings. By default, high band filter (LPFH_TBB) is power on.

See Figure 12 below to check selections.

19 | P a g e
© Copyright 2014-2015 Lime Microsystems CC BY 3.0
Step 1

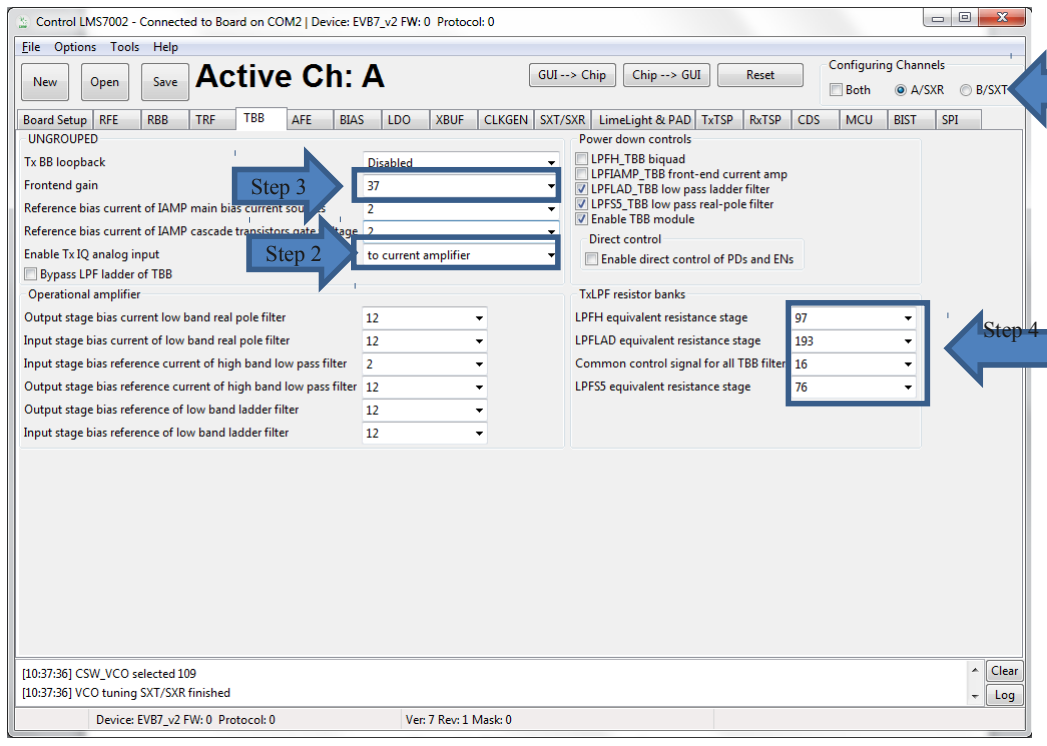
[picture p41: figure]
Step 4; Step 2; Step 3

Figure 12 TBB register setup procedure

Note: the register preset file for Tx test ‘TX_2140_MHz_demo_setup.ini’ is supplied with design kit. You can load it by clicking menu button Open>> locate and select the file in ../LMS7GUI folder/ ‘TX_2140_MHz_demo_setup.ini’ >> select Open, followed by GUI--> Chip button. The select SXT/SXR tab and retune synthesizer.

### 1.10 Testing the TX Output

When the transmitter is configured as shown in section 1.9, the TX1_A output (socket X1) can be connected to a spectrum analyzer (SA). With the SA you can now observe the results of this basic operational test (Figure 13). The test is looking at the DC offset from the un-programmed data DAC as LO leakage and the example shown below is measuring a value of -26.8dBm.

Figure 13 Basic TX testing using DC offset resulting in LO leakage

20 | P a g e
© Copyright 2014-2015 Lime Microsystems CC BY 3.0
Step 1

When the baseband is enabled, the WCDMA modulation can be tested and the results of Figure 14 can be obtained with the MXG Spectrum Analyser.

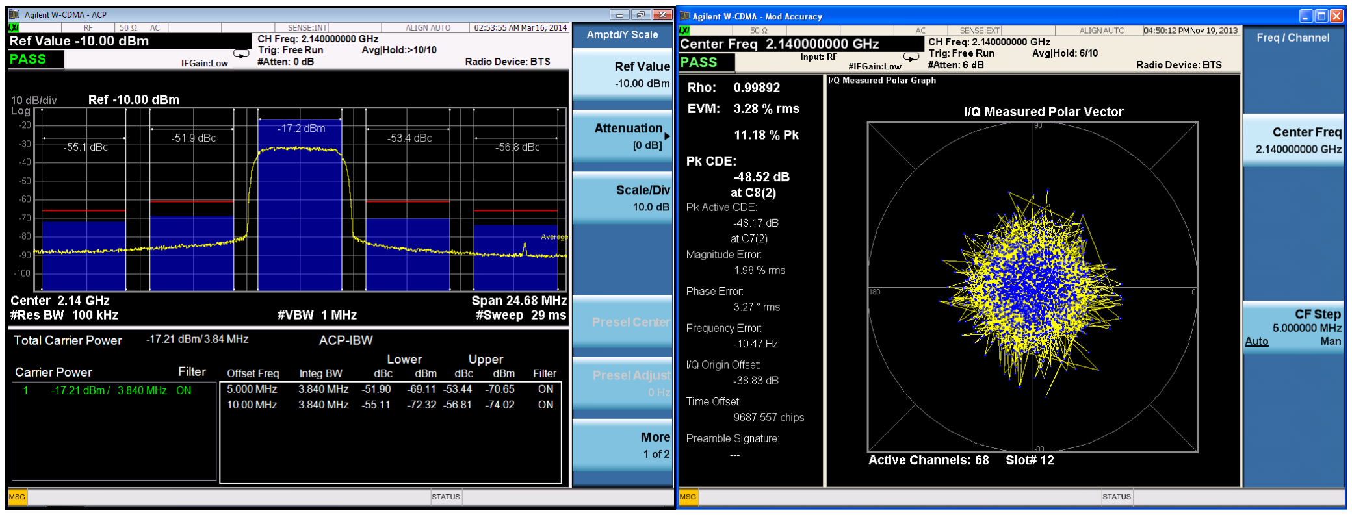
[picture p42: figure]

Figure 14 Basic TX testing using WCDMA modulation

### 1.10.1. TX Basic Operation Checks

To check the basic TX frequency and gain control, conduct some tests changing frequencies and gain settings. The following four tests are recommended:

TRF – TXPAD gain change setting from 0 to 31 and observe results. LO should vary by approx. 1 dB steps, 31dB range.
Change frequency from 2.14 GHz to 2.11 GHz and press ‘Calculate’/’Tune’ (CAP value should change), check the Spectrum Analyzer.
Change frequency from 2.11 GHz to 2.17 GHz and press ‘Calculate’/’Tune’ (CAP value should change), check the Spectrum Analyzer.
21 | P a g e
© Copyright 2014-2015 Lime Microsystems CC BY 3.0

### 1.11 Receiver Setup and Basic Testing

The test bench for the receiver is shown in Figure 15. Basic functionality checks on the receiver side are achieved by using the Analog output from connector X20.

Figure 15 Rx Test Setup

### 1.11.1. SXT/SXR tab setup

Select the SXT/SXR tab. To configure the Rx LO to 1950 MHz, do the following:

1. Select the A/SXR in the configuration channels window to control RxPLL
2. Enable Rx PLL VCO (Deselect).
3. Type the wanted frequency in Frequency, GHz box. In this case, 1950 MHz.
4. Press Calculate followed by Tune.

See Figure 16 below to check selections.

22 | P a g e
© Copyright 2014-2015 Lime Microsystems CC BY 3.0

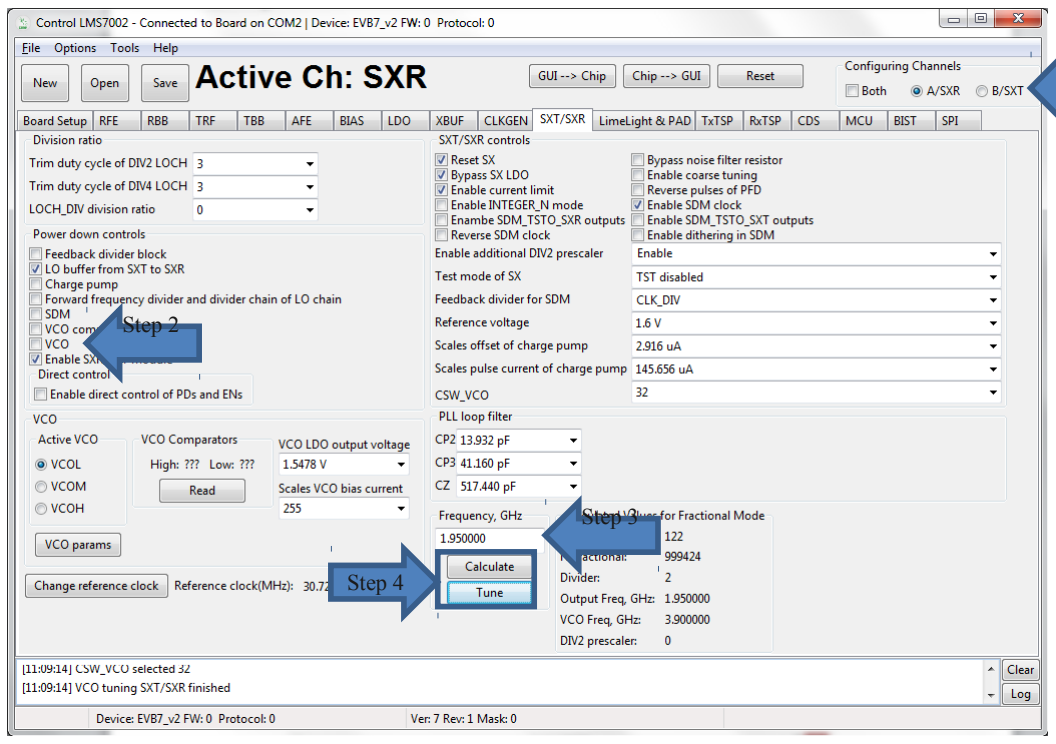
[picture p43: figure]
Step 2; Step 3; Step 4

Figure 16 SXR register setup procedure

### 1.11.2. RFE tab setup

Select the RFE tab to configure the receiver RF front–end. Follow the configuration steps below:

1. Enable LNA_RFE, RXFE mixer LO buffer and RFFE Quadrature LO generator.
2. Select Active path to the RXFE. Select LNAH for this test. By default the is preselected.
3. The LNA and TIA gain are preset to maximum.

See Figure 17 below to check selections.

23 | P a g e
© Copyright 2014-2015 Lime Microsystems CC BY 3.0
Step 1

Figure 17 SXR register setup procedure

### 1.11.3. RBB tab setup

Select the TBB tab to configure the PGA gain and baseband filter bandwidths. Follow the configuration steps below:

1. Select PGA output to output pads. This selection enables receiver analog outputs.
2. Set PGA gain to 19 dB.
3. Configure filter bandwidth. By default the LPFL is selected.

See Figure 18 below to check selections.

24 | P a g e
© Copyright 2014-2015 Lime Microsystems CC BY 3.0

Figure 18 SXR register setup procedure

Note: the register preset file for Rx test ‘RX_1950MHz_demo_setup.ini’ is supplied with design kit. You can load it by clicking menu button Open>> locate and select the file in ../LMS7GUI folder/ ‘RX_1950MHz_demo_setup.ini’ >> select Open, followed by GUI--> Chip button. The select SXT/SXR tab and retune synthesizer.

25 | P a g e
© Copyright 2014-2015 Lime Microsystems CC BY 3.0

### 1.12 Testing the RX Output

Set the signal generator to 1955 MHz (i.e. 5 MHz offset from PLL frequency selected) and input a sine wave at -70 dBm into the evaluation board antenna connector (LNAH_A, connector X4). Configure the receiver as showed in section 1.10. Connect an Analyser to X20 or X19. If everything is correctly setup, you should see the 1 MHz peak. See Figure 19 below.

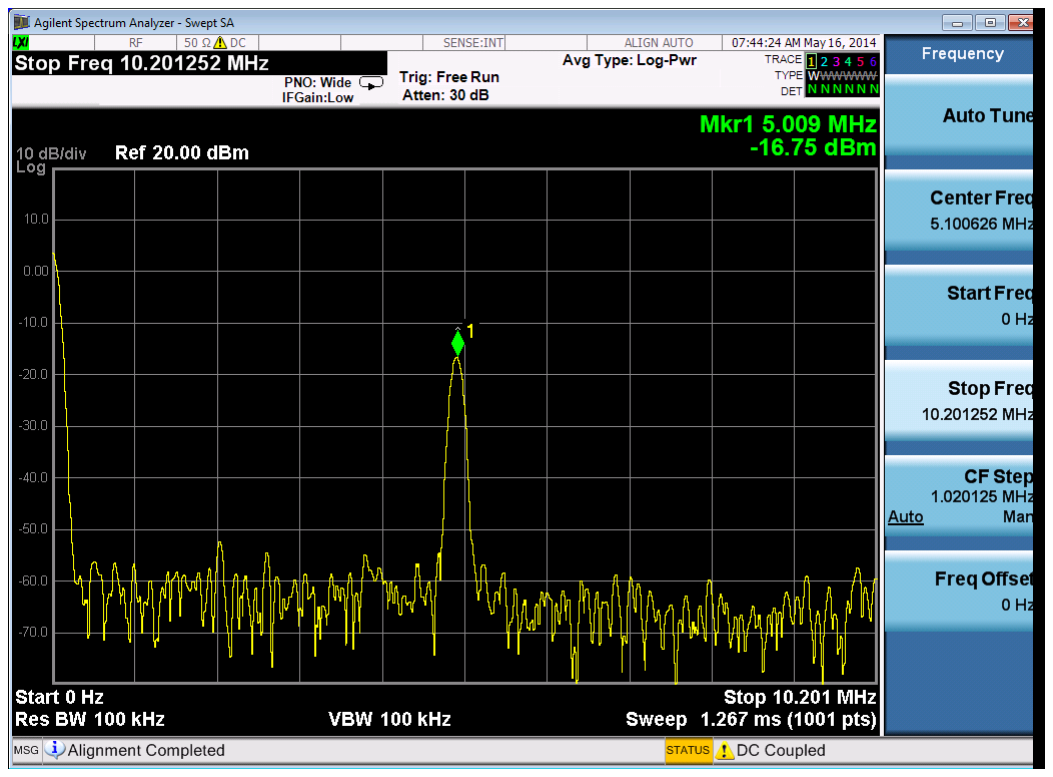
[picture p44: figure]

Figure 19 RX analog output on Spectrum Analyser.

### 1.12.1. RX Basic Operation Checks

To check the basic Rx frequency and gain control, conduct some tests changing frequencies and gain settings. The following six tests are recommended:

a. RBB – change PGA gain setting from 19 to -12, observe results, gain should decrease.
b. RFE – change TIA gain settings from Gmax to Gmin, observe results, gain should decrease.
c. RFE – LNA gain change from Gmax to Gmax -30, observe results, gain should decrease.
d. Change frequency from 1.95 GHz to 1.92 GHz and press ‘Calculate’/’Tune’. Change Signal Generator to 1.925 GHz (1MHz offset from PLL). Observe results.
e. Change frequency from 1.92 GHz to 1.98 GHz and press ‘Calculate’/’Tune’. Change Signal Generator to 1.985 GHz (1MHz offset from PLL). Observe results.
26 | P a g e
© Copyright 2014-2015 Lime Microsystems CC BY 3.0

### 1.13 Testing With Minimal Equipment

For users without all the equipment specified in section 1.39 (Appendix A) it is possible to link the TX1_A output (X1) to the receiver input LNAH_A input (X4) and rely on the LO leakage to provide an input signal to the RX.

Using the methods of section 1.9 and section 1.11 set the SXT to 2140 MHz and SXR to 2145 MHz and measure a 5 MHz signal with an oscilloscope to observe the RXI output at X19. The magnitude of the output signal can be controlled with the various gain controls in the RFE and TRF.

27 | P a g e
© Copyright 2014-2015 Lime Microsystems CC BY 3.0

# EVB7 Connectors and Options

### 1.14 Introduction to the EVB7 Connectors and Options

Section 1.15 describes the various connectors available on the EVB7. Section 1.16 describes the hardware options available on the EVB7, including reference clocks and the SPI control. The top and bottom of the board are shown in Figure 20 and Figure 21 respectively.

### 1.15 Board Connections

Figure 20 Design kit connection descriptions, Top view.

28 | P a g e
© Copyright 2014-2015 Lime Microsystems CC BY 3.0

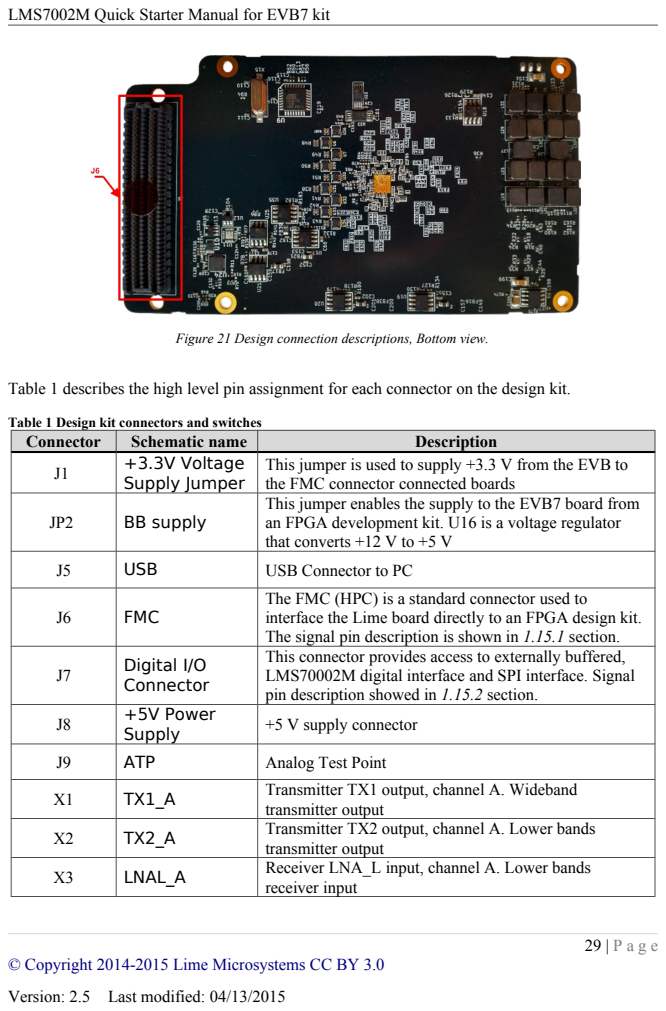
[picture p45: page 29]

Figure 21 Design connection descriptions, Bottom view.

Table 1 describes the high level pin assignment for each connector on the design kit.

Table 1 Design kit connectors and switches

This jumper is used to supply +3.3 V from the EVB to
the FMC connector connected boards
This jumper enables the supply to the EVB7 board from
an FPGA development kit. U16 is a voltage regulator
that converts +12 V to +5 V

The FMC (HPC) is a standard connector used to
interface the Lime board directly to an FPGA design kit.
The signal pin description is shown in 1.15.1 section.
This connector provides access to externally buffered,
LMS70002M digital interface and SPI interface. Signal
pin description showed in 1.15.2 section.

© Copyright 2014-2015 Lime Microsystems CC BY 3.0

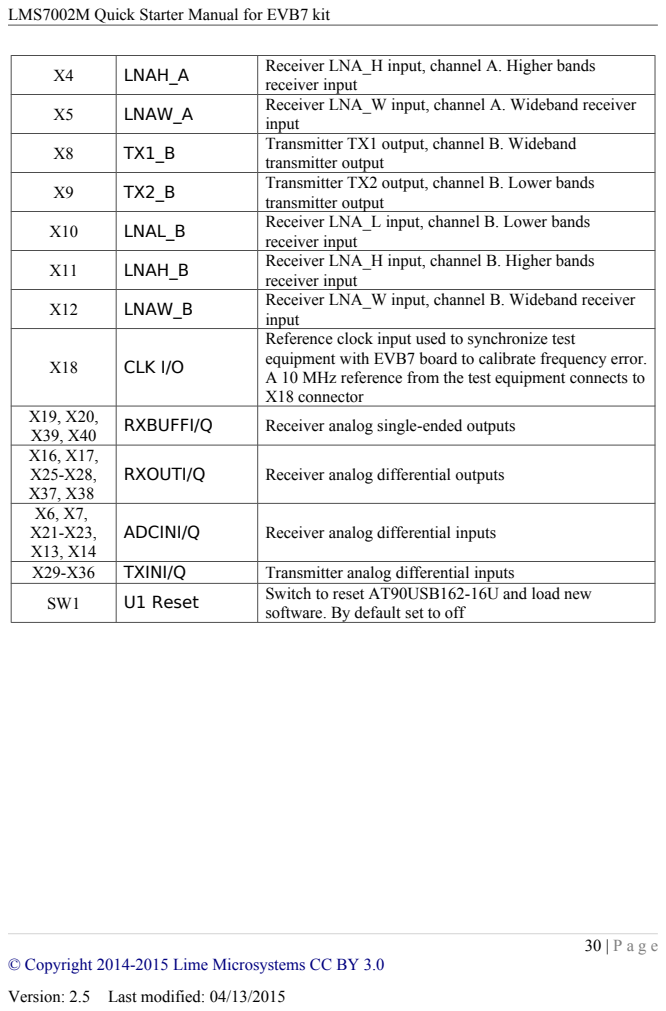
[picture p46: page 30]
LNAH_A; Receiver LNA_H input, channel A. Higher bands; receiver input; LNAW_A; Receiver LNA_W input, channel A. Wideband receiver; input; Transmitter TX1 output, channel B. Wideband; transmitter output; Transmitter TX2 output, channel B. Lower bands; LNAL_B; Receiver LNA_L input, channel B. Lower bands; LNAH_B; Receiver LNA_H input, channel B. Higher bands; LNAW_B; Receiver LNA_W input, channel B. Wideband receiver; CLK I/O; RXBUFFI/Q; Receiver analog single-ended outputs; RXOUTI/Q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

input
Reference clock input used to synchronize test
equipment with EVB7 board to calibrate frequency error.
A 10 MHz reference from the test equipment connects to
X18 connector

software. By default set to off

© Copyright 2014-2015 Lime Microsystems CC BY 3.0

### 1.15.1. FMC connector pin description

The digital baseband interface can be established via the FMC connector J6. The signal pin description is shown in Table 2.

Note: FMC HPC connector has 400 pins, but not all pins are used. Some pins are not connected and some are connected to GND. Please refer to EVB7 schematic for more details.

Table 2 FMC connector signal pin description
Pin number | Schematic name | Function
D8 | SyntCLK1 | Clock Out, CMOS
D9 | SyntCLK2 | Clock Out, CMOS
H7 | IQSEL2_DIR | IQSEL direction control for port 2. If ‘1’ – input, ‘0’ – output
H8 | DIO_DIR_CTRL
| 1 | Data direction control for port 2. If ‘1’ – input, ‘0’ – output
G9 | SDIO | Serial port data in/out, CMOS
G10 | DIG_RST
H10 | INTR | I2C port interrupt line, CMOS
H11 | SCLK | Serial port clock, positive edge sensitive, CMOS
H13 | RXFCLK | Clock from BBIC to RFIC during JESD207 mode, Port 2
H14 | RXEN | RX hard power off
G12 | RXMCLK | Clock from RFIC to BBIC during JESD207 mode, Port 2
G13 | RXIQSEL | IQ flag in RXTXIQ mode enable flag in JESD207 mode, Port 2
D14 | RESET | Hardware reset, active low, CMOS
D15 | IQSEL1_DIR | IQSEL direction control for port 1. If ‘1’ – input, ‘0’ – output.
C14 | SDO | Serial port data out, CMOS
C15 | DIO_DIR_CTRL
| 2 | Data direction control for port 1. If ‘1’ – input, ‘0’ – output.
H16 | RXD11 | DIQ bus, bit 11, Port 2
H17 | RXD8 | DIQ bus, bit 8, Port 2
G15 | TXNRX1 | LimeLight protocol control
G16 | RXD10 | DIQ bus, bit 10, Port 2
D17 | SAEN | Serial port A enable, active low, CMOS
H19 | RXD7 | DIQ bus, bit 7, Port 2
H20 | RXD4 | DIQ bus, bit 4, Port 2
G18 | RXD9 | DIQ bus, bit 9, Port 2
G19 | RXD6 | DIQ bus, bit 6, Port 2
H22 | RXD3 | DIQ bus, bit 3, Port 2
H23 | RXD2 | DIQ bus, bit 2, Port 2
G21 | TXNRX2 | LimeLight protocol control
G22 | RXD5 | DIQ bus, bit 5, Port 2
H25 | TXMCLK | Clock from RFIC to BBIC during JESD207 mode, Port 1
| | 31 | P a g e
© Copyright 2014-2015 Lime Microsystems CC BY 3.0

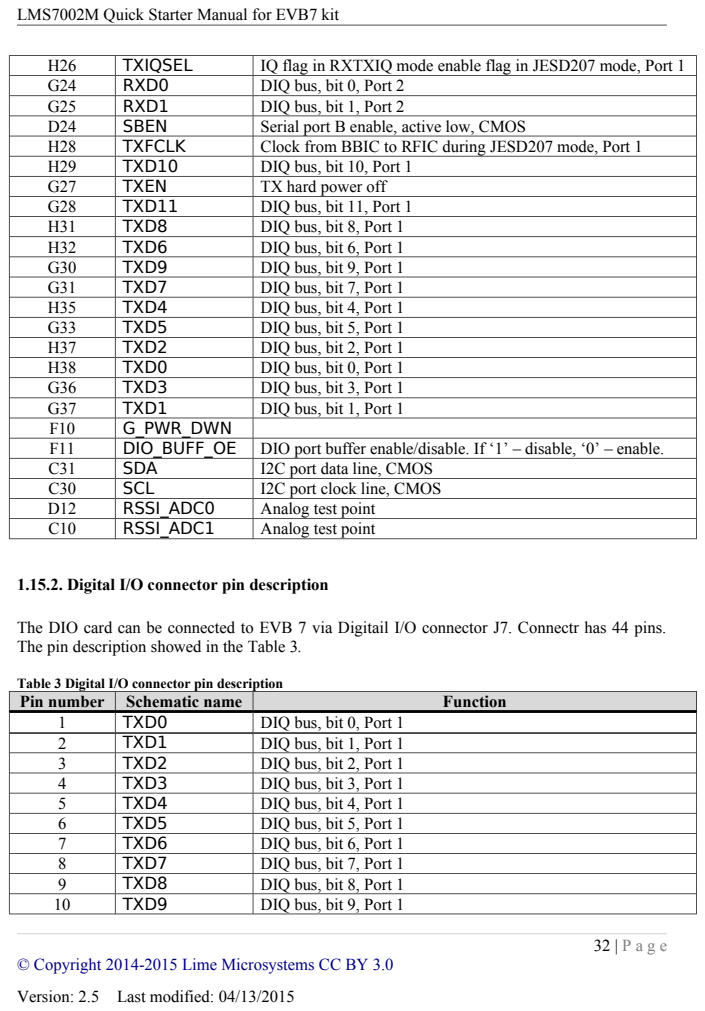
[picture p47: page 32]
TXIQSEL; IQ flag in RXTXIQ mode enable flag in JESD207 mode, Port 1; RXD0; DIQ bus, bit 0, Port 2; RXD1; DIQ bus, bit 1, Port 2; SBEN; Serial port B enable, active low, CMOS; TXFCLK; Clock from BBIC to RFIC during JESD207 mode, Port 1; TXD10; DIQ bus, bit 10, Port 1; TXEN; TX hard power off; TXD11; DIQ bus, bit 11, Port 1; TXD8; DIQ bus, bit 8, Port 1; TXD6; DIQ bus, bit 6, Port 1; TXD9; DIQ bus, bit 9, Port 1; TXD7; DIQ bus, bit 7, Port 1; TXD4; DIQ bus, bit 4, Port 1; TXD5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

1.15.2. Digital I/O connector pin description

The DIO card can be connected to EVB 7 via Digitail I/O connector J7. Connectr has 44 pins.
The pin description showed in the Table 3.

Table 3 Digital I/O connector pin description

© Copyright 2014-2015 Lime Microsystems CC BY 3.0

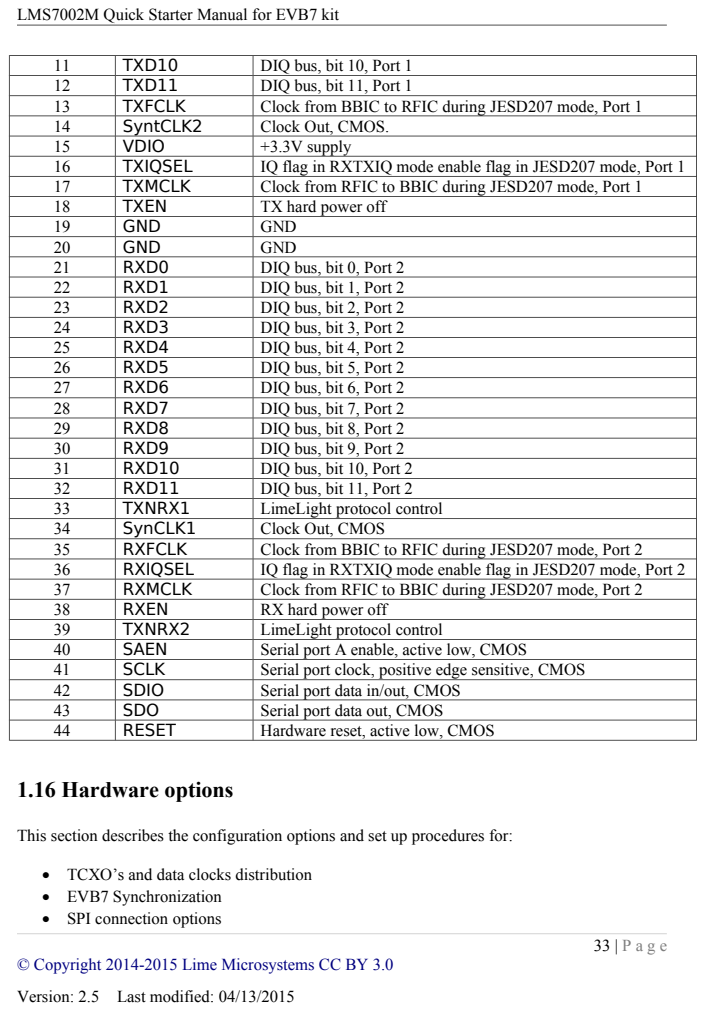
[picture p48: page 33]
TXD10; DIQ bus, bit 10, Port 1; TXD11; DIQ bus, bit 11, Port 1; TXFCLK; Clock from BBIC to RFIC during JESD207 mode, Port 1; SyntCLK2; Clock Out, CMOS.; VDIO; +3.3V supply; TXIQSEL; IQ flag in RXTXIQ mode enable flag in JESD207 mode, Port 1; TXMCLK; Clock from RFIC to BBIC during JESD207 mode, Port 1; TXEN; TX hard power off; GND; RXD0; DIQ bus, bit 0, Port 2; RXD1; DIQ bus, bit 1, Port 2; RXD2; DIQ bus, bit 2, Port 2; RXD3; DIQ bus, bit 3, Port 2; RXD4; DIQ bus, bit 4, Port 2; RXD5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

This section describes the configuration options and set up procedures for:

• TCXO’s and data clocks distribution
• EVB7 Synchronization
• SPI connection options

© Copyright 2014-2015 Lime Microsystems CC BY 3.0

The board is shipped with the default mode which means a basic operation using an external digital I/O source via the FMC connector. Various configurations are available depending on the system requirements for development work. The configurations are summarized and the following sections describe the board modifications required to achieve these configurations.

### 1.16.1. TCXO’s Configuration

The LMS7002M device provides a flexible clocking scheme which allows the PLL reference clock and digital interface clock to be independently clocked. In addition, the digital interface clock can be generated internally in LMS7002M.

The EVB7 board is shipped with a 30.72MHz TCXO. In order to meet the demanding specifications of the various standards, Lime Microsystems has worked with Rakon to develop a new part, called E6245LF* that enables the board to meet the required specifications.

The board can accept three different types of TCXO’s as described in Table 4.

Table 4 TCXO Configurations
Size | Referenc
| e number | Part
| | Number | Description
14.7x9.2 | XO2 | E5405LF | 61.44 MHz Crystal oscillator, used in combination with
| | | divider /2 (U10) for performance improvements
7x5 (4pin) | XO1 | E5280LF | 30.72 MHz crystal shipped with the board as a default
7x5 (6pin) | XO3 | E6245LF | 30.72 MHz high performance crystal oscillator.

When E5280LF is fitted the resistor R144 must also be fitted.

*Please contact Rakon for E6245LF part: info@rakon.co.uk

### 1.16.2. EVB7 synchronization

The LMS7002M board provides options to synchronize the on-board TCXO with the base band or test equipment systems. To do that, connect a 10 MHz reference clock generated by the test equipment to EVB7 board X18 SMA connector. Program the on-board PLL via the GUI ADF4002 page. When the board is synchronized the LED (LD2) will be lit.

A board that is synchronized with the test equipment or any other RF device will not have frequency error.

34 | P a g e
© Copyright 2014-2015 Lime Microsystems CC BY 3.0

### 1.16.3. SPI Control Configuration

The LMS7002M SPI interface is controlled from a USB connection by default. The SPI interface can also be controlled from baseband interface connectors J6 and J7. Please note only one SPI master can be connected to the bus at the time.

If the SPI is controlled via the baseband connector J6 do not connect either a USB cable to J5 and do not use J7 connector. This removes any possible bus contention. Please note that NF denotes component is Not Fitted.

Table 5 SPI Control Options
SPI control
Configuration | DEFAULT MODE USB connector or baseband connector J7 | SPI controlled via J6 baseband connector
| Description | SPI controlled via USB or J7 connector | SPI connected to BB via connector J6 FMC
Component
R91 | NF | 0R
R92 | NF | 0R
R93 | NF | 0R
R94 | NF | 0R
R95 | NF | 0R
R96 | NF | 0R

All of these components are located on the underside of the board.

Note. The USB interface must be left disconnected when the external SPI control is being used to prevent bus contention. Additionally the components R91-R96 should be fitted as listed in Table 5.

### 1.16.4. Baseband Digital Interface Voltage

The default digital interface voltage is 3.3V. It can be adjusted by changing R183 to the values listed in Table 6.

Table 6 Digital IO Voltage Control

35 | P a g e
© Copyright 2014-2015 Lime Microsystems CC BY 3.0

1.16.5. EVB7 Matching networks; Connector; Schematic name; Matching network; Broadband from 10 – 6000MHz, using TCM1-63AX+ Balun; Broadband from 4.5 – 3000MHz, using TC1-1-13MA+ Balun; LNAL_A; LNAH_A; LNAW_A; LNAL_B; LNAH_B; LNAW_B

The matching networks that are fitted to EVB7 at manufacture are listed in Table 7.

Table 7 Default bands matched to EVB7

© Copyright 2014-2015 Lime Microsystems CC BY 3.0

# Detailed Guide to LMS7002M Control Software

### 1.17 Control LMS7002M – Software Description

This section describes the Control LMS7002M software GUI and each of the menus, buttons and embedded controls. Most of the pages in the tool corresponds to the top level sections of the SPI programming map, with the exception of the ‘Board Setup’ and the ‘SPI’ page.

1.18 Control LMS7002M – Window Panels.

The “LMS7002M Control” GUI is comprised in three main pieces: GUI control panel, LMS7002M register and EVB7 board configuration panel, and LOG panel. These are shown in Figure 22.

### 1.18.1. GUI Control panel

GUI Control panel includes menu bar and various control buttons for controlling the software. These will be described in detail in section 1.19. The GUI control panel is shown in Figure 23.

### 1.18.2. Configuration panel

Configuration panel controls the LMS7002M registers and some evaluation board setup and is shown in Figure 24.

Each configuration panel has specific register control on internal LMS7002M blocks. There are 16 different configuration panels for controlling the LMS7002M chip and 2 for controlling other devices on the EVB7. Every control of the panel is described in sections 1.20 to 1.37.

37 | P a g e
© Copyright 2014-2015 Lime Microsystems CC BY 3.0

LMS7002M Registers and EVB7 Board Configuration Panel; LOG Panel; GUI Control Panel

Figure 22 GUI window diagram

Figure 23 GUI Control Panel window

38 | P a g e
© Copyright 2014-2015 Lime Microsystems CC BY 3.0

Figure 24 GUI Configuration Board Setup window

### 1.18.3. Log panel

Log panel section logs all activity executed with the GUI and is shown in Figure 25.

39 | P a g e
© Copyright 2014-2015 Lime Microsystems CC BY 3.0

Figure 25 GUI Log panel

The Clear button deletes previously registered activity.

When Log button pressed, the Message Log configuration pop-up, as shown in .

Figure 26 GUI Message Log tab
This allows you to select the type of the information you want to log. The logged messages can be saved into *.txt file.

In the lower left corner of the log tab, the evaluation board version and firmware version is displayed.

### 1.19 The Menu Bar

### 1.19.1. The File Menu

In the File menu, you can select to start new projects, save current GUI project (saved in *.ini or *.txt format), or open previously saved project. Saved project file contains complete register setup for LMS7002M. These files can be transferred to any other computer or used as a register initialization setup for LMS7002M in baseband.

The .ini format is machine readable only.
The .txt format is human and machine readable.

### 1.19.2. The Option Menu

In the Options menu, you can select the COM port to which evaluation board is attached.

### 1.19.3. The Tool Menu

40 | P a g e
© Copyright 2014-2015 Lime Microsystems CC BY 3.0

Register Map is accessible from Tools menu. When the Register Map is selected, new window will pop-up showing current LMS7002M register configuration per each channel, as shown in Figure 27.


Figure 27 GUI Register Map window

### 1.19.4. The Help Menu

The help menu contains one option giving the software version and build date. It also contains the contact details for Lime Microsystems.

### 1.19.5. The Button Menu

The button menu contains 6 buttons controls and 3 other minor controls. The “new”, “open”, “save” buttons are identical to those in the “File menu” of section 1.19.1.

The RESET button performs a manual reset on the chip and updates the “LMS7002M Control” software.

To write register configuration from the “LMS7002M Control” software to the chip, press GUIàChip button.

To read register configuration from the chip to the “LMS7002M Control” software, press ChipàGUI button.

### 1.19.6. The Configuring Channel Controls

Configuring Channels window select which channel or PLL is currently controlled. The activated channel is always displayed in a front panel:

41 | P a g e
© Copyright 2014-2015 Lime Microsystems CC BY 3.0

If selected Both, front panel will display: Active Ch: SXR&SXT or Active Ch: A&B.

If selected A/SXR, front panel will display: Active Ch: SXR or Active Ch: A.

If selected B/SXT, front panel will display: Active Ch: SXT or Active Ch: B.

The display shows information depending which configuration tab you are currently and which channel is selected.

The SXR option is used for setting the receive synthesizer parameters in the SXT/SXR tab (see section 1.30). The SXT option is used for setting the transmitter synthesizer parameters in the SXT/SXR tab. The A and B channel to the A and B channels for the TX and RX MIMO channels of the RFE, RBB, TRF,TBB and AFE tabs.

42 | P a g e
© Copyright 2014-2015 Lime Microsystems CC BY 3.0

### 1.20 Board Setup (Si5351C and ADF4002)

These tabs control two other devices on the EVB7 board.

The ADF4002 is a PLL to lock an external reference (usually 10MHz on X18) with the on board TXCO (usually 30.72MHz or 52.00MHz). This 30.72MHz reference is supplied to the LMS7002M synthesizers. This is normally used to synchronize the measurement equipment with the EVB7 board remove very minor frequency differences typically a few kHz. To synchronize board:

- Press ‘Synchronize’ button to program the ADF4002, if all is correct the green PLL locked LED (LD2) on the interface board should illuminate. LD2 is located in the upper left hand corner of the interface board.

Make sure that the Fxo value corresponds to the frequency of TCXO.

The Si5351C is a dual PLL for frequency conversion in the 10-100MHz range. It can be used to provide programmable clock signals to external hardware through the external digital interfaces and also to the LMS7002M RX and TX PLL Clocks. This allows the clock rates to be independent of the TXCO frequency. The tab is shown in Figure 28.

Figure 28 GUI Board Setup tab

By default, the EVB7 is configured to supply LMS7002M RX and TX PLL reference clock pins directly from TCXO. With a simple board modification TX and RX PLL clocks can be supplied directly from the Si5351C clock generator.

43 | P a g e
© Copyright 2014-2015 Lime Microsystems CC BY 3.0

Using this feature:
- Type onboard TCXO frequency to CLKIN Frequency (MHz) window.
- Enable clock channel.
- Enter the desired output frequency.
- Press “Configure Clocks”.

The Buffers controls on board buffer directions for the LMS7002M digital interface. As well, LOGIC_RESET pin and CORE_LDO _EN pins are controlled from this window.

Table 8 GUI SPI control description
Parameter | Description
| Buffers
DIO_DIR_CTRL1 | On board buffers direction control for Port 1. If selected, Port 1 is receiver.
DIO_DIR_CTRL2 | On board buffers direction control for Port 2. If selected, Port 2 is receiver.
DIO_BUFF_OE | If selected, sets onboard buffers to Hi-Impedance state.
IQSEL1_DIR | On board buffers IQSEL pin direction control for Port 1. If selected, Port 1 is receiver.
IQSEL2_DIR | On board buffers IQSEL pin direction control for Port 2. If selected, Port 2 is receiver.
G_PWR_DWN | External enable control signal for the internal LDO’s.
DIG_RST | Controls hardware pin logic reset.

### 1.21 RFE

RFE tab controls the RX Front End stages, including LNA selection, LNA gain, TIA gain and RX LO cancellation. A picture of the tab is shown in Figure 29. A description of each function available in this tab is shown below in Table 9.

44 | P a g e

© Copyright 2014-2015 Lime Microsystems CC BY 3.0

Figure 29 GUI RFE tab

Table 9 GUI RFE control description
Parameter | Description
Power down controls
LNA_RFE | Power control for LNA. Must be deselected in normal operation.
RXFE loopback1 | Power control signal for RXFE loopback to LNAL from TXRF. Used only for RF loopback.
RXFE loopback2 | Power control signal for RXFE loopback to LNAW from TXRF. Used only for RF
loopback.
RXFE mixer LO
buffer

Power control signal for RXFE mixer lo buffer. Must be deselected in normal operation.

RXFE Quadrature
LO generator

Power control signal for RXFE quadrature LO generator. Must be deselected in normal operation.
RXFE RSSI | Power control signal for RXFE RSSI. Enables RSSI readings when powered on.
RXFE TIA | Power control signal for RXFE TIA. Must be deselected in normal operation.
Enable RFE module | Major power down for RXFE modules. All modules will be power down when deselected.
Direct control | Enables direct control of PDs and ENs for RFE. Enabled when selected.
Input shorting switches
Input of loopback 1 Enables the input shorting switch at the input of the loopback with LNAL. Should be selected when RXFE Loopback1 is NOT active. Input of loopback 2 Enables the input shorting switch at the input of the loopback with LNAW. Should be selected when RXFE Loopback2 is NOT active.
Input of LNAL | Enables the input shorting switch at the input of the LNAL. Should be selected when LNAH
is NOT active or during very high signal conditions.
Input of LNAW | Enables the input shorting switch at the input of the LNAW. Should be selected when
LNAW is NOT active or during very high signal conditions. Reference current
Loopback amplifier | Controls reference current of the RXFE loopback amplifier. Recommended value is 1.8uA.
TIA 1st Stage | Controls reference current of the RXFE TIA first stage. Recommended value is 2.
TIA 2nd Stage | Controls reference current of the RXFE TIA second stage. Recommended value is 2.
Capacitor controls
Compensation TIA | Compensation capacitor for TIA. Recommended value is 15.
Feedback TIA | Feedback capacitor for TIA. Controls the 3dB BW of the TIA. Recommended value is 230.
Trim Duty Cycle
I channel | Trims the duty cycle in I channel. Default value set to 8.
Q channel | Trims the duty cycle in Q channel. Default value set to 8.
UNGROUPED
Active path to the
RXFE

Selects the active LNA of the RXFE between LNAL, LNAH and LNAW. Default value is no path active.
Decoupling cap at
the output of RX
mixer

Control the decoupling cap at the output of the RX Mixer. The capacitor range is from 80fF to 2560fF, with step size of 80 fF (32 steps). Default value is 640fF.

Controls cap parallel
with the LNA input

Controls the Q of the input LNA matching circuit and provides tradeoff between gain/NF and IIP2/3. The higher the frequency, the lower value should be. Also, the higher value lower the Q. Default value is 6.
Compensation
resistor | of | TIA
opamp

Controls the compensation resistors of the TIA operational amplifier. Recommended value is 5.

Sets | feedback
resistor value

Sets the TIA feedback resistor value. Default vale is 13.

Enable Rx MIMO Enable MIMO mode when MIMO is selected. If SISO is selected on Channel A is in operation.
45 | P a g e
© Copyright 2014-2015 Lime Microsystems CC BY 3.0

DC
Offset I side | Controls DC offset of the I channel at the output of the TIA by injecting current to the input of the TIA. Control range from 0 to 127. Default value is 0.
Offset Q side | Controls DC offset of the Q channel at the output of the TIA by injecting current to the input of the TIA. Control range from 0 to 127. Default value is 0.
Mixer LO signal | Controls DC voltage of the mixer LO signal. Control range from 0.44V to 0.621V. Default value is 0.557V.
Enable DCOFFSET block | Enables the DC offset block for the RXFE. Select before calibrating DC offset of the Rx path
| Current Control
LNA output common mode voltage | Controls the LNA output common mode voltage. Control range from 0 to 31. Default value is 2.
LNA Core | Controls the current of the LNA core. Control range from 0uA to 1291.7uA. Default value is 500uA.
| Gain Controls
LNA | Controls selected LNA gain. Control range from Gmax to Gmax-30. Default value is Gmax.
Loopback | Controls RXFE loopback gain. Control range from Gmax to Gmax-40.Default value is Gmax-40dB.
TIA | Controls TIA Gain. Three gain stages: Gmax, Gmax-3dB and Gmax-12dB. Default value is Gmax.

### 1.22 RBB

RBB tab controls the receiver IF stage bandwidth, PGA gain and loopback.


Figure 30 GUI RXBB tab

A picture of the tab is shown in Figure 30. A description of each function available in this tab is shown below in .

46 | P a g e
© Copyright 2014-2015 Lime Microsystems CC BY 3.0

Table 10 GUI RXBB control description
Parameter | Description
UNGROUPED
BB | loopback | to
RxLPF

Enables baseband loopback to high band LPF or low band LPF. Enables loopback when selected. Default value is disabled.
PGA input connected
to

Controls PGA input path. There are a total five different inputs to the PGA:
1. LPFL_RBB
2. LPFH_RBB
3. Bypass LPF
4. Tx baseband loopback connected to PGA
5. TXRF peak detector connected to PGA
Concurrently only one path can be selected as PGA input. Default path is LPFL output connected to PGA.
PGA gain | PGA gain control. Control range from -12dB to +19dB. Default value is -1 dB.
PGA | Feedback
capacitor

PGA feedback capacitor value control. Control range from 0 to 511. Default value is 2.

PGA connected to Control PGA output switch internally directly to ADC or indirectly via the Analog output pads. Default value of PGA output is selected to ADC input.
Power down controls
LPFH block | Power down of the LPFH block. Default value block is powered down.
LPFL block | Power down of the LPFL block. Default value block is powered on.
PGA block | Power down of the PGA block. Default value block is powered on
Enable RBB module | Powers down all RBB blocks when not selected. If selected enables power down of separate
RBB blocks. Default values set to enable.
Direct control | Enable direct control of PDs and ENs. Enabled when selected.
RC time constant
Resistance | Controls the absolute value of the resistance of the RC time constant in LPF. Control range
from 0 to 31. The higher value selected the wider LPF BW. Default values set to 16. LPFH capacitance
value (rxMode from
37MHz to 108MHz)

Controls the capacitance value of the RC time constant of high band LPF. Control range from 0 to 255. The lower value selected the wider LPF BW. Default values set to 0.

LPFL capacitance
value (rxMode from
1.4MHz to 20MHz)

Controls the capacitance value of the RC time constant of low band LPF. Control range from 0 to 255. The lower value selected the wider LPF BW. Default values set to 0. Intended to be controlled together with the TIA to maintain Chebychev response. Operational amplifier
LPFH stability
passive
compensation

Controls the stability passive compensation of the LPFH operational amplifier. Control range from 0 to 7. Default values set to 0.

LPFL stability
passive
compensation

Controls the stability passive compensation of the LPFL operational amplifier. Control range from 0 to 5. Default values set to 5.

Input stage reference
bias | current
(RBB_LPF)

Controls the reference bias current of the input stage of the operational amplifier used in LPF blocks (Low or High). Must increase up to 24 when a strong close blocker is detected to maintain the linearity performance. Control range from 0 to 31. Default values set to 12.
Output | | stage
reference bias current
(RBB_LPF)

Controls the reference bias current of the output stage of the operational amplifier used in LPF blocks (Low or High). Must increase up to 24 when a strong close blocker is detected to maintain the linearity performance. Control range from 0 to 31. Default values set to 12.
Output | | stage
reference bias current
(PGA)

Controls the output stage reference bias current of the operational amplifier used in the PGA circuit. Must increase up to 12 when a strong close blocker is detected or when operating at the high band frequencies to maintain the linearity performance. Control range from 0 to 31. Default values set to 6.
Input stage reference Controls the input stage reference bias current of the operational amplifier used in the PGA
47 | P a g e
© Copyright 2014-2015 Lime Microsystems CC BY 3.0

bias current (PGA) | circuit. Must increase up to 12 when a strong close blocker is detected or when operating at the high band frequencies to maintain the linearity performance. Control range from 0 to 31.
| Controls the stability passive compensation of the PGA operational amplifier. Control range

### 1.23 TRF

The TRF page contains the Tx front end amplifier gain controls, Tx outputs paths selection controls and all transmit block power down controls.


Figure 31 GUI TRF page

A picture of the tab is shown in Figure 31. A description of each function available in this tab is shown below in Table 11.

Table 11 GUI TRF control description
Parameter | Description
UNGROUPED
EN_LOWBWLOMX_TMX_TRF Controls the high pass pole frequency of the mixer switches. Selection between low band and high band. Default is high band selection.
Enable Tx MIMO mode | Enables MIMO mode. Default is set to SISO mode.
TXPAD | power | detector
preamplifier gain

Controls TXPAD power detector gain. Default gain is set to 25dB.

Switched capacitor at TXPAD output

Controls TXPAD output capacitor used for fine tuning. Control range from 0 to
7. Default is set to 3.
Loss of the loopback path at the
TX side

Controls Tx loopback path gain. Default gain is set to -24 dB.

TXPAD linearizing part gain Controls TXPAD linearization gain. Control range from 0 to 31. Default is set
48 | P a g e
© Copyright 2014-2015 Lime Microsystems CC BY 3.0

to 0.
TXPAD gain and output power | Controls the gain of TXPAD. Control range from 0 to 31. Default is set to 0 (Max gain).
Bias voltage at gate of TXPAD cascade | Controls the bias voltage at the gate of TXPAD cascade. Control range from 0 to 31. Default is set to 0.
Bias at gate of mixer NMOS | Controls the bias at the gate of the mixer NMOS switch. Control range from 0 to 31. Default is set to 28.
Bias at gate of mixer PMOS | Controls the bias at the gate of the mixer PMOS switch. Control range from 0 to 31. Default is set to 16.
TXFE output selection | Enables TXFE, Band 1 or Band 2 output. Band 1 enabled by default.
Enable TXPAD loopback path | Enables the TXPAD loopback path. Disabled by default.
| Power detector
Resistive load | Controls power detector dynamic range by selecting resistive load. Default is set to 5K||1.25K.
| Bias current
Linearization section | Control the bias current of the linearization section of the TXPAD. Control range from 0 to 31. Default is set to 12.
Main gm section | Control the bias current of the TXPAD. Control range from 0 to 31. Default is set to 12.
| Power down controls
Power detector | Enables power detector when deselected. By default power detector is powered down.
TX LO buffers | Enables TX LO buffer. By default TX LO is enabled.
TXPAD | Enables TXPAD block. By default TXPAD is enabled
Enable TRF modules | Power down all TFE blocks when deselected. By default TRF blocks enabled.
Direct Control | Enable direct control of PDs and ENs. Enabled if selected.
| TXPAD cascade transistor gate bias
VDD | TXPAD cascade transistor gate bias is referred to VDD – connect to VDD to operate.
GNDS | TXPAD cascade transistor gate bias is referred to GND.
| Trim duty cycle
I channel | Trims the duty cycle in I channel. Default value set to 8.
Q channel | Trims the duty cycle in Q channel. Default value set to 8.
49 | P a g e
© Copyright 2014-2015 Lime Microsystems CC BY 3.0

### 1.24 TBB

The TBB page controls TX IF gain settings, low-LPF and high-LPF filter bandwidths and various loopback options.

Figure 32 GUI TBB page

A picture of the tab is shown in Figure 32. A description of each function available in this tab is shown below in Table 12.

Table 12 GUI TBB control description
Parameter | Description
UNGROUPED
Tx BB Loopback | Controls the Tx BB loopback path. By default loopback is disconnected.
Frontend gain | Tx baseband stage gain control. Control range from 0 to 63. Default is set to 24.
Reference | bias
current of IAMP
main bias current
source

This controls the reference bias current of the IAMP main bias current sources. Control range from 0 to 31. Default is set to 12.

Reference bias
current of IAMP
cascode transistors
gate voltage

This controls the reference bias current of the IAMP's cascode transistors gate voltages that set the IAMP's input voltage level. Control range from 0 to 31. Default is set to 12.

Enable Tx IQ analog
input

Controls Tx analog inputs path. By default disabled.

Bypass LPF ladder
of TBB

Controls TBB LPF ladder bypass mode.

Operational amplifier
50 | P a g e
© Copyright 2014-2015 Lime Microsystems CC BY 3.0

Output stage bias
current low band real
pole filter

This controls the operational amplifier's output stage bias current. Control range from 0 to
31. Default is set to 12.
Input | stage | bias
current low band real
pole filter

This controls the operational amplifier's input stage bias current. Control range from 0 to 31. Default is set to 12

Input | stage | bias
reference current of
high band low pass
filter

This controls the operational amplifiers input stage bias reference current of the high band filter. Control range from 0 to 31. Default is set to 2.

Output stage bias
reference current of
high band low pass
filter

This controls the operational amplifiers output stage bias reference current of the high band filter. Control range from 0 to 31. Default is set to 12.

Output stage bias
reference for low
band ladder filter

This controls the operational amplifiers' output stages bias reference current of the low band filter. Control range from 0 to 31. Default is set to 12.

Input | stage | bias
reference for low
band ladder filter

This controls the operational amplifiers' input stages bias reference current of the low band filter. Control range from 0 to 31. Default is set to 12.

Power down controls
LPFHTBB biquad Enables LPFH filter when deselected. By default filter is powered down. LPFIAMP front-end
current amp

Enables LPF current amplifier when deselected. By default current amplifier is enabled.

LPFLADTBB low
pass ladder filter

Enables LPF ladder when deselected. By default current amplifier is enabled.

LPFS5TBB low pass
real-pole filter

Enables LPF real-pole filter when deselected. By default real-pole filter is enabled.

Turn off all of
TBBTOP

Enables TBB blocks once selected. By default TBB blocks are enabled.

Enable direct control
of PDs and ENs

Enables direct control of PDs and ENs for TBB. Enabled when selected.

Resistor banks
LPFH equivalent
resistance stage

Control LPFH bandwidth. Control range from 0 to 255. The higher number the higher bandwidth. Default setting is 0.
LPFLAD equivalent
resistance stage

Control LPFL bandwidth. Control range from 0 to 255. The higher number the higher bandwidth. Default setting is 193.
Common control
signal for all

A common control signal for all the capacitor banks of TBB filters. Control range from 0 to
31. Default register value set to 8.
LPFS5 equivalent
resistance stage

This controls the value of the equivalent resistance of the resistor banks of the real pole filter stage. Control range from 0 to 255. Default register value set to 76.

51 | P a g e
© Copyright 2014-2015 Lime Microsystems CC BY 3.0

### 1.25 AFE

The AFE page controls the TX and RX analog front-end interface to the digital section.

Figure 33 GUI AFE tab

A picture of the tab is shown in Figure 33. A description of each function available in this tab is shown below in Table 13.

Table 13 GUI AFE control description
Parameter | Description
AFE
Peak current of DAC Controls the peak current of the DAC output current. By default DAC peak current set to 325uA.
MUX input of ADC
ch 1.

Controls the MUX at the input of the ADC channel 1. By default MUX set to PGA output.

MUX input of ADC
ch 2.

Controls the MUX at the input of the ADC channel 2. By default MUX set to PGA output.

Time interleave two
analogue signals
into one ADC

Default register set to Two ADC’s

Power down controls
AFE current mirror
in BIASTOP

Enabled AFE current mirror in BIAS_TOP when deselected. Default current mirror is enabled.
ADC ch. 1 | Enable control of ADC of channel 1. Enabled when not selected. Enabled by default.
ADC ch. 2 | Enable control of ADC of channel 2. Enabled when not selected. Enabled by default.
DAC ch. 1 | Enable control of DAC of channel 1. Enabled when not selected. Enabled by default.
DAC ch. 2 | Enable control of DAC of channel 2. Enabled when not selected. Enabled by default.
Enable AFE module | Enabled AFE blocks when selected. By default AFE is enabled.
52 | P a g e
© Copyright 2014-2015 Lime Microsystems CC BY 3.0

### 1.26 BIAS

The BIAS page controls the LMS7002M bias settings.


Figure 34 GUI BIAS tab

A picture of the tab is shown in Figure 34. A description of each function available in this tab is shown below in Table 14.

Table 14 GUI BIAS control description
Parameter | Description
Power down controls
Fix /RP block | Enable signal for Fix/RP block when not selected. Default register setting is set to enabled.
Fix | Enable signal for Fix block when not selected. Default register setting is set to enabled.
PTAT/RP block | Enable signal for PTAT/RP block when not selected. Default register setting is set to
enabled.
PTAT | Enable signal for PTAT block when not selected. Default register setting is set to enabled.
Enable central bias
block

Enable signal for central bias block. Default register setting is set to enabled.

Power | down | all
block

Enables BIAS block when selected. By default BIAS block is enabled.

BIAS
BIASTOP test mode | Controls the test mode of the BIAS_TOP. No test mode selected by default.
RP_CALIB_bias | Control bias current calibration code. Control range from 0 to 31. Default setting is 0. This
is used to set the voltage across current reference resistor R12 to 600mV – typically code 7. The “calibrate” button automatically sets this.
53 | P a g e
© Copyright 2014-2015 Lime Microsystems CC BY 3.0

### 1.27 LDO

This tab controls the internal LDO modules. These LDO’s are used when the LMS7002M chip analog blocks supplied by single 1.8V supply. Pictures of the tab is shown in Figure 35 and Figure 36.

Figure 35 GUI LDO Power downs & Bias & Noise filter tab

Each 1.25V and 1.4V supply pins have internal regulators controlled via SPI interface. The LDO ’Power downs & Bias & Noise filter’ tab (figure above) divided in separate sections:
- Power control
- Short noise filter resistor
- Bias

In Power control section is the SPI controls are in groups related to their function. These controls enable the LDO for the particular block.

Short noise filter resistor bypasses noise filtering resistor. By default enabled.

Bias section enables the load dependent bias to optimize the load regulation for each LDO. This option reduces the LDO response, but increase total current consumption. Recommend to set to constant bias (not selected).

In the ‘Voltage’ tab the voltage level of the each internal LDO can be adjusted (figure below).

54 | P a g e
© Copyright 2014-2015 Lime Microsystems CC BY 3.0


Figure 36 GUI LDO Voltages tab

### 1.28 XBUF

XBUF page controls the TX and RX PLL clock pin input configurations to provide a reference frequency for SXT and SXR respectively. The CLKGEN PLL uses the SXR Clock.

Figure 37 GUI XBUF tab

A picture of the tab is shown in Figure 37. A description of each function available in this tab is in Table 15.
55 | P a g e
© Copyright 2014-2015 Lime Microsystems CC BY 3.0

Table 15 GUI XBUF control description
Parameter | Description
| UNGRPUPED
Rx Enable biasing the input’s DC voltage | Receiver clock input self-biasing digital control. By default disabled. For use with AC coupled input.
Tx Enable biasing the input’s DC voltage | Transmitter clock input self-biasing digital control. By default disabled. For use with AC coupled input.
Shorts the input 3.3V buffer in XBUF RX | Shorts the Input of 3.3V buffer in XBUF. By default disabled
Shorts the input 3.3V buffer in XBUF TX | Shorts the Input of 3.3V buffer in XBUF. By default disabled
EN_OUT2_XBUF_TX | Enables the 2nd output of TX XBUF. By default buffer is disabled. This control is intended to internally rout TX PLL CLK to SXT and SXR by an internal path.

EN_TBUFIN_XBUF_RX Disables the input from the external XO. By default buffer is disabled. This control is
| intended to internally rout TX PLL CLK to SXT and SXR by an internal path.
| Power down controls
Power down Rx | Power down control of the Rx XBUF. Not powered down by default.
Power down Tx | Power down control of the Tx XBUF. Not powered down by default.
Enable XBUF module | Power down complete XBUF block. Enabled by default.

### 1.29 CLKGEN

The block diagram of the CGEN module (internal clock generator) is shown. The table in this chapter describes the control registers of the CGEN module.


Figure 38 GUI CLKGEN tab

The internal LMS7002N CLKGEN generates clock for ADC’s, DAC’s and TSP modules. To program the CLKGEN for wanted frequency follow the step below:
56 | P a g e
© Copyright 2014-2015 Lime Microsystems CC BY 3.0

1. Type the wanted frequency in CLK_H (MHz) window ( default frequency is 61.44 MHz)
2. Press ‘Calculate’ followed by ‘Tune’

After this procedure the digital block core will be supplied by wanted frequency. All other register are preset so no need to change.

A picture of the tab is shown in Figure 38. A description of each function available in this tab is shown below in Table 16.

Table 16 GUI CLKGEN control description
Parameter | Description
UNGROUPED
Bypass | noise | filter
resistor

Bypasses the noise filter resistor for fast settling time. Disabled by default.

Enable coarse tuning
block

Enable signal for coarse tuning block. Disabled by default.

Enable SDM clock | Enables SDM clock. Used in INT-N mode or for noise testing. Enabled by default.
Reverse SDM clock | Invert the SDM clock. By default not inverted.
Connection | to
FCLK_ADC

Selects if F_CLKH or F_CLKL is connected to FCLK_ADC. By default FCLK_ADC connected to F_CLKH and FCLK_DAC to F_CLKL.
Test mode of SX | Controls the test mode of the SX. Available test modes:
0: TST disabled. By default test mode disabled.
1: tstdo[0]=CLKH1 & tstdo[1]=CLKH2
2: tstdo[0]=CLK_SDM & tstdo[1]=DIV_CLK 2: tstao=vco_vtune through a 50Kohm resistor 3: tstdo[0]=REFCLK & tstdo[1]=DIV_CLK 3: tstao=vco_vtune through a 10Kohm resistor 5: tstdo[0]=PFD UP & tstdo[1]=PFD DN
Invert DAC F_CLK | Inverts the clock F_CLKL for TX TSP. By default is not inverted.
REVPH_PFD_CGEN | Inverts the pulses of PFD. It can be used to reverse the polarity of the PLL loop. By
default pulse is not inverted.
Pulse used in start-up to
reset

Enables pulse to reset the CLKGEN. By default set to normal operation.

Enable INTEGER-N
mode

Enables INTEGER-N mode of the synthesizer. By default disabled.

Enable SDM_TSTO
outputs

Enables the buffer for SDM_TSTO test outputs. Is not enabled by default.

Enable dithering in SDM Enabled dithering. Disabled by default.
Invert ADC F_CLK | Inverts the clock F_CLKL for RX TSP. By default is not inverted.
Output for SDM | Selects between the feedback divider output and Fref for SDM. By default feedback
divider is selected.
Power down controls
Charge pump | Power down control for charge pump of the CGEN block. Enabled (deselected) by
default.
Frequency divider | Power down control for forward frequency divider of the CGEN block. Enabled
(deselected) by default.
VCO | Power down control for VCO of the CGEN block. Enabled (deselected) by default.
Enables | CLKGEN
module

Power down control of the CGEN block. Enabled (selected) by default.

Feedback frequency Power down control for feedback divider of the CGEN block. Enabled (deselected)
57 | P a g e
© Copyright 2014-2015 Lime Microsystems CC BY 3.0

divider | by default.
SDM | Power down control for SDM of the CGEN block. Enabled (deselected) by default.
VCO comparator | Power down control for VCO comparators of the CGEN block. Enabled (deselected) by default.
| VCO
CSW_VCO_CGEN | Coarse control of VCO frequency, 0 for lowest frequency and 255 for highest, by 1 step. By default set to 128.

Scales VCO bias current Scales the VCO bias current from 0 to 2.5xInom. Control range from 0 to 31. Default
| value 16.
| PLL filter
CP2 | Controls the value of CP2 (cap from CP output to GND) in the PLL loop filter. Control range from 0 to 5688fF. Default value 2275.2 fF.
CP3 | Controls the value of CP3 (cap from CP output to GND) in the PLL loop filter. Control range from 0 to 3720fF. Default value 1736.00 fF.
CZ | Controls the value of CP3 in the PLL loop filter. Control range from 0 to 43800fF. Default value 321200.00 fF.
| Charge pump
Scales offset current | Scales the offset current of the charge pump, from 0 to 63. This current is used in Fran-N mode to create an offset in the CP response and avoid the non-linear section. Default value is set to 20.
Scales pulse current | Scales the pulse current of the charge pump, from 0 to 63. Default value is set to 20.
58 | P a g e
© Copyright 2014-2015 Lime Microsystems CC BY 3.0

### 1.30 SXT/SXR

This tab controls the SXT and SXR modules. The table in this chapter describes the control registers of SXT and SXR modules.

Figure 39 GUI SXT/SXR tab

Most of the SXT/SXR registers are preset to for normal (FDD) operation. To configure Tx/Rx LO to wanted frequency, do the following:

1. Select the A/SXR (receiver PLL) or B/SXT (transmitter PLL) in configuration channels window accordingly which PLL frequency you want to control.
2. Enable VCO (deselect).
3. Type the wanted frequency in Frequency, GHz box. In this case 1950MHz.
4. Press Calculate followed by Tune.

A picture of the tab is shown in Figure 39. A description of each function available in this tab is shown below in Table 17.

Table 17 GUI SXT/SXR control description

Trims the duty cycle of DIV2 LOCH. Only works when forward divider is dividing by at least 2 (excluding quadrature block division). If in bypass mode, this does not

Trims the duty cycle of DIV4 LOCH. Only works when forward divider is dividing by at least 4 (excluding quadrature block division). If in bypass mode, this does not

59 | P a g e
© Copyright 2014-2015 Lime Microsystems CC BY 3.0

LOCH_DIV division
ration

Controls the division ratio in the LOCH_DIV. By default set to 2.

Power down controls
Feedback divider block Enables PLL feedback divider. By default is enabled. LO buffer from SXT to
SXR

Power down control for LO buffer from SXT to SXR. Controlled for SXT only. To be activated only in the TDD mode. By default is disabled.
Charge pump | Power down control for Charge Pump block. By default is enabled.
Froward | frequency
divider and divider chain
of LO chain

Power down control for feedback frequency divider and divider chain of the LO chain. By default is enabled.

SDM | Power down control for SDM block. By default is enabled.
VCO comparator | Power down control for VCO comparator block. By default is enabled.
VCO | Power down control for VCO block. By default is disabled.
Enable | SXR/SXT
module

Power down control for SXT/SXR block. By default enabled.

Direct control | Enabled control of PD and EN. Enabled if selected.
VCO
Active VCO | Selects the active VCO. It is set by SX_SWC calibration. By default VCOH selected.
VCO | LDO | output
voltage

Controls VCO LDO output voltage. Control range from 0 to 255. By default set to 185.
Scales VCO bias current Scales the VCO bias current from 0 to 2.5xInom. Control range from 0 to 255. By default set to 255.
SXT/SXR controls
Reset SX | Resets SX when enabled. A pulse should be used in the start-up to reset. By default
disabled.
Bypass SX LDO | Controls the bypass signal for the SX LDO. By default LDO is bypassed.
Enable current limit | Enables the output current limitation in the VCO regulator. By default enabled.
Enable | INTEGR_N
mode

Enables INTEGER-N mode of the SX. By default SX is set to Frac-N mode.

Enable
SDM_TSTO_SXR
outputs

Enables the SDM_TSTO outputs for SXR testing purposes. By default is disabled.

Reverse SDM clock | Inverts DSM clock. By default clock is not inverted.
Reverse pulses of PFD | Inverts the pulses of PFD block. It can be used to reverse the polarity of the PLL
loop. By default the clock is not inverted.
Bypass | noise | filter
resistor

Bypasses the noise filter resistor for fast settling time. By default the speed up is not enabled.
Enable coarse tuning | Enable signal for coarse tuning block.
Enable SDM clock | Enables SDM clock. In INT-N mode or for noise destining. Enabled by default.
Enable | SDM_TSTO
outputs

Enables the SDM_TSTO outputs for testing purposes. By default is disabled.

Enable dithering in SDM Enabled dithering in SDM. Disabled by default. Enable additional DIV2
prescaler

Enables additional DIV2 prescaler at the input of the programmable divider. The core of programmable divider in the SX feedback divider works up to 5.5GHz. For FVCO>5.5GHz, the prescaler is needed to lower the input frequency. By default prescaler is not enabled.
Test mode of SX | Controls the test mode of the SX. Available test modes:
0: TST disabled. By default test mode disabled.
1: tstdo[0]=REFCLK & tstdo[1]=DIV_CLK & tstdo[2]=CLK_SDM 2: tstao[0] vco_vtune through a 50Kohm resistor
4: tstao[0] vco_vtune through a 10Kohm resistor
5: tstdo[0]=PFD UP & tstdo[1]=PFD DN
60 | P a g e
© Copyright 2014-2015 Lime Microsystems CC BY 3.0

Feedback divider for
SDM

Selects SDM clock input between the feedback divider output and Fref. By default feedback divider output is selected.
Reference voltage | Sets the reference voltage for varactor. By default set to 1.6V.
Scales offset of charge pump | Scales the offset current of the charge pump block. Control range from 0 to 15uA. This current is used in Fran-N mode to create an offset in the CP response and avoid the non-linear section. By default set to 2.9uA.
Scales pulse current of charge pump | Scales the pulse current of the charge pump block. Control range from 0uA to 145.6. By default set to 145.6.
| PLL loop filter
CP2 | Control for CP2 value (cap from CP output to GND) of the PLL loop filter. Control range from 0fF to 34830fF. Default value 13932fF.
CP3 | Control for CP3 value (cap from CP output to GND) of the PLL loop filter. Control range from 0fF to 88200fF. Default value 41160fF.
CZ | Control for CZ value of the PLL loop filter. Control range from 0fF to 705.6fF. Default value 517.44fF.
CSW_VCO | Coarse control of VCO frequency, 0 for lowest frequency and 255 for highest. This control is set by SX_SWC calibration. Default value set to 128.

### 1.31 Application Note on Tuning PLLs on LMS7002M

The LMS7002M has three synthesisers: SXT, SXR and CLKGEN. The LMS7002M Control Software uses a simple tuning algorithm to control these. The minimum and maximum frequencies of each VCO are defined in the “VCO PARAMS” control for each VCO. This allows linear interpolation of CSW_VCO control when using the “Tune” control. Further frequencies could be added to the “VCO PARAMS” table to allow quadratic or cubic interpolation.

The LMS7002M also provides two comparators to detect if the VCO tuning voltage is within the recommended limits. These comparators are read with the “Read” or “Read CMP” buttons, after the “Tune” process has been carried out. When the PLL is successfully locked, the low comparator should be “1” and the high comparator “0”. If the comparators are both “0”, or both “1”, then the tuning voltage is outside the recommended range.

For best phase noise and best protection against drift the following procedure is recommended. The “Tune” button gives a nominal value for CSW_VCO. The value of CSW_VCO is manually increased until the tuning comparators report the tune voltage is out of range. The last good CSW_VCO value, CSW_VCOmax , is noted. Then CSW_VCO is manually decreased until the tuning comparators report that the tune voltage is out of range. The last good CSW_VCO, CSW_VCOmin, is also noted. The average of the two extreme CSW_VCO values is the optimum CSW_VCOopt which will give good phase noise and protection against drift.

61 | P a g e
© Copyright 2014-2015 Lime Microsystems CC BY 3.0

### 1.32 LimeLight & PAD

This tab controls the LMS7002M digital interface configuration. The IO cell controls are described in the chapter tables.

Figure 40 GUI Limelight&PAD Modes tab

The LimeLight tab has two sections:
- Modes
- Sample position & Clock

A picture of the tab is shown in Figure 40. A description of each function available in the ‘Modes’ tab is shown below in Table 18.

Table 18 GUI Limelight&PAD Modes control description
Parameter | Description
| Pull up control
Engage pull up of TXCLK pad | Controls Pull up resistor of TX_CLK pad. Pull-up enabled by default.
Engage pull up of SDA pad | Controls Pull up resistor of SDA pad. Pull-up enabled by default.
Engage pull up of SDIO pad | Controls Pull up resistor of SDIO pad. Pull-up enabled by default.
Engage pull up of SCLK pad | Controls Pull up resistor of SCLK pad. Pull-up enabled by default.
Engage pull up of DIQ2 pad | Controls Pull up resistor of DIQ2 pad. Pull-up enabled by default.
Engage pull up of TXNRX2 pad | Controls Pull up resistor of TXNRX2 pad. Pull-up enabled by default.
Engage pull up of MCLK2 pad | Controls Pull up resistor of MCLK2 pad. Pull-up enabled by default.
Engage pull up of IQSELEN1 pad Controls Pull up resistor of IQSELEN1 pad. Pull-up enabled by default.
Engage pull up of FCLK1 pad | Controls Pull up resistor of FCLK1 pad. Pull-up enabled by default.
Engage pull up of RXCLK pad | Controls Pull up resistor of RXCLK1 pad. Pull-up enabled by default.
Engage pull up of SCL pad | Controls Pull up resistor of SCL pad. Pull-up enabled by default.
62 | P a g e
© Copyright 2014-2015 Lime Microsystems CC BY 3.0

Engage pull up of SDO pad | Controls Pull up resistor of SDO pad. Pull-up enabled by default.
Engage pull up of SEN pad | Controls Pull up resistor of SEN pad. Pull-up enabled by default.
Engage pull up of IQSELEN2 pad Controls Pull up resistor of IQSELEN2 pad. Pull-up enabled by default.
Engage pull up of FCLK2 pad | Controls Pull up resistor of FCLK2 pad. Pull-up enabled by default.
Engage pull up of DIQ1 pad | Controls Pull up resistor of DIQ1 pad. Pull-up enabled by default.
Engage pull up of TXNRX1 pad | Controls Pull up resistor of TXNRX1 pad. Pull-up enabled by default.
Engage pull up of MCLK1 pad | Controls Pull up resistor of MCLK1 pad. Pull-up enabled by default.
| Reset Signals
Logic registers Tx MIMO ch. B | Resets all registers to the default state for Tx MIMO channel B logic. By default RESET inactive.
Logic registers Tx MIMO ch. A | Resets all registers to the default state for Tx MIMO channel A logic. By default RESET inactive.
Logic registers Rx MIMO ch. B | Resets all registers to the default state for Rx MIMO channel B logic. By default RESET inactive.
Logic registers Rx MIMO ch. A | Resets all registers to the default state for Rx MIMO channel A logic. By default RESET inactive.
Rx FIFO soft reset | Soft reset of LimeLight RX FIFO registers. By default RESET inactive.
Configuration memory Tx MIMO ch. B | Resets configuration memory to the default state for Tx MIMO channel B logic. By default RESET inactive.
Configuration memory Tx MIMO ch. A | Resets configuration memory to the default state for Tx MIMO channel A logic. By default RESET inactive.
Configuration memory Rx MIMO ch. B | Resets configuration memory to the default state for Rx MIMO channel B logic. By default RESET inactive.
Configuration memory Rx MIMO ch. A | Resets configuration memory to the default state for Rx MIMO channel A logic. By default RESET inactive.
Tx FIFO soft reset | Soft reset of LimeLight TX FIFO registers. By default RESET inactive.
| Driver strength
SDA pad | Set SDA pad driver strength to 4mA or 8 mA. By default set to 4 mA.
SCL pad | Set SCL pad driver strength to 4mA or 8 mA. By default set to 4 mA.
SDIO pad | Set SDIO pad driver strength to 4mA or 8 mA. By default set to 4 mA.
DIQ2 pad | Set DIQ2 pad driver strength to 4mA or 8 mA. By default set to 4 mA.
DIQ1 pad | Set DIQ1 pad driver strength to 4mA or 8 mA. By default set to 4 mA.
| Power Control
Enable Rx MIMO ch. B | Enables Rx MIMO B channel. Enabled by default.
Enable Tx MIMO ch. B | Enables Tx MIMO B channel. Enabled by default.
Enable Rx MIMO ch. A | Enables Rx MIMO A channel. Enabled by default.
Enable Tx MIMO ch. A | Enables Tx MIMO A channel. Enabled by default.
| LimeLight modes
Enable LimeLight interface | Enables LimeLight interface. By default enabled.
Frame start for Port1 | Selects frame start ID for Port 1, can be set to ‘0’ or ‘1’. By default set to ‘0’.
Frame start for Port2 | Selects frame start ID for Port 2, can be set to ‘0’ or ‘1’. By default set to ‘0’.
LimeLight port1 mode | Select mode for Port 1: T TRXIQ or JESD207. By default set to JESD207.
LimeLight port2 mode | Select mode for Port 2: T TRXIQ or JESD207. By default set to JESD207.
Port 1 mode selection | IQSEL selection for Port 1: RXIQ or TXIQ. By default set to RXIQ.
Port 2 mode selection | IQSEL selection for Port 2: RXIQ or TXIQ. By default set to TXIQ.
| UNGROUPED
RxFIFO data source | RxFIFO data source selection: RxTSP, TxFIFO, LFSR. By default set to RxTSP.
Data transmit port to TSP | Port selection for data transmit to TSP.
Disable MIMO channel B | MIMO channel B enable control.
SPI mode | SPI mode control.
MIMO access control | MIMO access control.
63 | P a g e
© Copyright 2014-2015 Lime Microsystems CC BY 3.0


Figure 41 GUI Limelight&PAD Sample position tab
A picture of the tab is shown in Figure 41. Description of each function available from the ‘Sample position & Clock’ page is shown below in Table 19.

Table 19 GUI Limelight&PAD Sample position control description
Parameter | Description
| Sample source when Port1 is Tx
Position 3 | Select sample source of the position 3: BQ, BI, AQ or AI. By default BQ is selected.
Position 2 | Select sample source of the position 2: BQ, BI, AQ or AI. By default BI is selected.
Position 1 | Select sample source of the position 1: BQ, BI, AQ or AI. By default AQ is selected.
Position 0 | Select sample source of the position 0: BQ, BI, AQ or AI. By default AI is selected.
| Sample source when Port2 is Tx
Position 3 | Select sample source of the position 3: BQ, BI, AQ or AI. By default BQ is selected.
Position 2 | Select sample source of the position 2: BQ, BI, AQ or AI. By default BI is selected.
Position 1 | Select sample source of the position 1: BQ, BI, AQ or AI. By default AQ is selected.
Position 0 | Select sample source of the position 0: BQ, BI, AQ or AI. By default AI is selected.
| Sample source when Port1 is Rx
BQ sample position | Select BQ sample position in frame. Position: 3, 2, 1, or 0. By default position set to 3.
BI sample position | Select BI sample position in frame. Position: 3, 2, 1, or 0. By default position set to 2.
AQ sample position | Select AQ sample position in frame. Position: 3, 2, 1, or 0. By default position set to 1.
AI sample position | Select AI sample position in frame. Position: 3, 2, 1, or 0. By default position set to 0.
| Sample source when Port2 is Rx
BQ sample position | Select BQ sample position in frame. Position: 3, 2, 1, or 0. By default position set to 3.
BI sample position | Select BI sample position in frame. Position: 3, 2, 1, or 0. By default position set to 2.
AQ sample position | Select AQ sample position in frame. Position: 3, 2, 1, or 0. By default position set to 1.
AI sample position | Select AI sample position in frame. Position: 3, 2, 1, or 0. By default position set to 0.
| Clock controls
TX FIFO read clock source | Select TX FIFO read clock source: TxTSPCLK, FCKL1 or FCKL2. By default TxTSPCLK is selected.
TX FIFO write clock source | Select TX FIFO write clock source: FCKL1, FCKL2 or RxTSPCLK. By default FCKL1 is selected.

RX FIFO read clock Select RX FIFO read clock source: MCKL1, MCKL2, FCKL1 or FCKL2. By default
64 | P a g e
© Copyright 2014-2015 Lime Microsystems CC BY 3.0

source | MCKL2 is selected.
RX FIFO write clock
source

Select RX FIFO write clock source: FCKL1, FCKL2 or RxTSPCLK. By default RxTSPCLK is selected.
MCLK2 clock source Select MCKL2 clock source from: RxTSPCLKA, TxTSPCLKA, RxTSPCLKA after divider or TxTSPCLKA after divider. By default RxTSPCLK after divider is selected. MCLK1 clock source Select MCKL1 clock source from: RxTSPCLKA, TxTSPCLKA, RxTSPCLKA after divider or TxTSPCLKA after divider. By default TxTSPCLK after divider is selected. TxTSPCLKA clock
divider

TxTSP clock divider, used to produce MCLK(1/2) clocks. Control range from 0 to 255. By default set to 255.
RxTSPCLKA clock
divider

RxTSP clock divider, used to produce MCLK(1/2) clocks. Control range from 0 to
255. By default set to 255.
Enable Tx clock divider | Enables Tx clock divider. Set to enable by default.
FCLK1 invert | Inverts FCLK1 clock. By default clock is not inverted.
Enable Rx clock divider | Enables Rx clock divider. Set to enable by default.
FCLK2 invert | Inverts FCLK1 clock. By default clock is not inverted.
MCLK1DLY | Select MCLK1 clock delay. By default clock not delayed.
MCLK2DLY | Select MCLK2 clock delay. By default clock not delayed.
Direction controls
DIQ2 mode | DIQ2 direction control mode. By default set to Automatic.
DIQ1 mode | DIQ1 direction control mode. By default set to Automatic.
DIQ2 direction | DIQ2 direction. By default set to Input.
DIQ1 direction | DIQ1 direction. By default set to Input.
ENABLE2 mode | ENABLE2 direction control mode. By default set to Automatic.
ENABLE1 mode | ENABLE1 direction control mode. By default set to Automatic.
ENABLE2 direction | ENABLE2 direction. By default set to Input.
ENABLE1 direction | ENABLE1 direction. By default set to Input.
LML1
Clock cycles to wait
before data drive stop

Controls the number of clock cycles to wait before data drive stop after burst stop is detected in JESD207 mode on Port 1 and Port 1 is transmitter. By default set to 1. Clock cycles to wait
before data drive start

Controls the number of clock cycles to wait before data drive stop after burst start is detected in JESD207 mode on Port 1 and Port 1 is transmitter. By default set to 1. Clock cycles to wait
before data capture stop

Controls the number of clock cycles to wait before data capture stop after burst stop is detected in JESD207 mode on Port 1 and Port 1 is receiver. By default set to 1.
Clock cycles to wait
before data capture stop

Controls the number of clock cycles to wait before data capture stop after burst start is detected in JESD207 mode on Port 1 and Port 1 is receiver. By default set to 1.
LML2
Clock cycles to wait
before data drive stop

Controls the number of clock cycles to wait before data drive stop after burst stop is detected in JESD207 mode on Port 1 and Port 1 is transmitter. By default set to 1. Clock cycles to wait
before data drive start

Controls the number of clock cycles to wait before data drive stop after burst start is detected in JESD207 mode on Port 1 and Port 1 is transmitter. By default set to 1. Clock cycles to wait
before data capture stop

Controls the number of clock cycles to wait before data capture stop after burst stop is detected in JESD207 mode on Port 1 and Port 1 is receiver. By default set to 1.
Clock cycles to wait
before data capture stop

Controls the number of clock cycles to wait before data capture stop after burst start is detected in JESD207 mode on Port 1 and Port 1 is receiver. By default set to 1. Direction controls
DIQ2 mode | DIQ2 direction control mode for port 2. Set to Automatic by default.
DIQ1 mode | DIQ1 direction control mode for port 1. Set to Automatic by default.
DIQ2 direction | DIQ2 direction. Set to input by default.
DIQ1 direction | DIQ1 direction. Set to input by default.
ENABLE2 mode | ENABLE2 direction control mode. Set to Automatic by default.
ENABLE1 mode | ENABLE1 direction control mode. Set to Automatic by default.
ENABLE2 direction | ENABLE2 direction. Set to input by default.
65 | P a g e
© Copyright 2014-2015 Lime Microsystems CC BY 3.0

ENABLE1 direction | ENABLE1 direction. Set to input by default.

### 1.33 TxTSP

The Tx_TSP tab controls the digital blocks of TxTSPA and TxTSPB modules.

Figure 42 GUI TxTSP tab

A picture of the tab is shown in Figure 42. A description of each function available in this tab is shown below in Table 20.

Table 20 GUI TxTSP control description
Parameter | Description
Enable TxTSP | Enables TxTSP modules enable. Enabled by default.
CMIX_GAIN | CMIX gain control. Control range from -6 dB to +6d B. Step size 6 dB. Set to 0 dB by default.
CMIX Spectrum control | Spectrum control of CMIX. By default set to downconvert.
Start BIST | Starts TxTSP built-in self-test. Keep it at 1 one at least three clock cycles.
| Bypass
CMIX | Bypass CMIX module when selected.
GFIR3 | Bypass GFIR3 module when selected.
GFIR1 | Bypass GFIR1 module when selected.
Gain correction | Bypass Gain correction module when selected.
ISINC | Bypass ISINC module when selected.
GFIR2 | Bypass GFIR2 module when selected.
DC Correction | Bypass DC correction module when selected.
Phase correction | Bypass Phase correction module when selected.
| GFIR1
Length | Set GFIR parameter I. Control range from 0 to 7.
Clock Division Ration | Sets GFIR filter clock division ration. Control range from 0 to 255.
Coefficients | Sets/Load GFIR filters coefficients. By default all set to 0.
66 | P a g e
© Copyright 2014-2015 Lime Microsystems CC BY 3.0

GFIR2
Length | Set GFIR parameter I. Control range from 0 to 7.
Clock Division Ration | Sets GFIR filter clock division ration. Control range from 0 to 255.
Coefficients | Sets/Load GFIR filters coefficients. By default all set to 0.
| GFIR3
Length | Set GFIR parameter I. Control range from 0 to 7.
Clock Division Ration | Sets GFIR filter clock division ration. Control range from 0 to 255.
Coefficients | Sets/Load GFIR filters coefficients. By default all set to 0.
| DC Corrector
DC ch. I | Sets DC corrector value to channel I. Control range from -128 to 128. By default 0.
DC ch. Q | Sets DC corrector value to channel Q. Control range from -128 to 128. By default 0.
| IQ Corrector
Gain ch. Q | Sets Gain corrector value to channel Q. Control range from 0 to 2047. By default 2047.
Gain ch. I | Sets Gain corrector value to channel I. Control range from 0 to 2047. By default 2047.
Phase corrector | Sets Phase corrector value. Control range from 0 to 2047. By default 0.
| Interpolation
HBI ratio | Sets HBI interpolation ratio. Possible control values 2, 4, 8, 16, 32 and bypass. By default bypassed.
| TSG
Swap I and Q signal | Swap IQ signals at test signal generator's output. By default not selected.
TSGFCW | Select frequency generated by test NCO. By default TSG frequency set to the TSP clock divided by 8.
TSGMODE | Select test signal generator mode: NCO or DC. By default NCO is selected.
Input Source | Select input source to TSP: LML output or TSG. By default LML output is selected.
TSGC | TSG full scale control: 0 dB or -6 dB. By default set to -6 dB.
Load DC to I | Load TSG DC I register with value from DC_REG (hex) box.
Load ED to Q | Load TSG DC Q register with value from DC_REG (hex) box.
| NCO
Mode | Selects the CW or PHO (Phase offset) mode for NCO.
NCO bits to dither | Selects number of bits for NCO dithering.
FCW(MHz) | Type wanted NCO frequency.
Set reference frequency | Set reference frequency for NCO. The frequency the same as TSP block.
Upload NCO | Program NCO
67 | P a g e
© Copyright 2014-2015 Lime Microsystems CC BY 3.0

### 1.34 RxTSP

The Rx_TSP tab controls the digital blocks of RxTSPA and RxTSPB modules. A picture of the tab is shown in Figure 43. A description of each function available in this tab is shown below in Table 21.


Figure 43 GUI RxTSP tab

Table 21 GUI RxTSP control description
Parameter | Description
Enable RxTSP | Enables TxRSP modules enable. Enabled by default.
CMIX_GAIN | CMIX gain control. Control range from -6 dB to +6 dB. Step size 6 dB. Set to 0 dB by default.
CMIX Spectrum control | Spectrum control of CMIX. By default set to downconvert.
Start BIST | Starts RxTSP built-in self-test. Keep it at 1 one for at least three clock cycles
| Bypass
CMIX | Bypass CMIX module when selected.
GFIR3 | Bypass GFIR3 module when selected.
GFIR1 | Bypass GFIR1 module when selected.
Gain correction | Bypass Gain correction module when selected.
AGC | Bypass AGC module when selected.
GFIR2 | Bypass GFIR2 module when selected.
DC Correction | Bypass DC corrector module when selected.
Phase correction | Bypass Phase corrector module when selected.
| GFIR1
Length | Set GFIR parameter I. Control range from 0 to 7.
Clock Division Ration | Sets GFIR filter clock division ration. Control range from 0 to 255.
Coefficients | Sets/Load GFIR filters coefficients. By default all set to 0.
68 | P a g e
© Copyright 2014-2015 Lime Microsystems CC BY 3.0

GFIR2
Length | Set GFIR parameter I. Control range from 0 to 7.
Clock Division Ration | Sets GFIR filter clock division ration. Control range from 0 to 255.
Coefficients | Sets/Load GFIR filters coefficients. By default all set to 0.
| GFIR3
Length | Set GFIR parameter I. Control range from 0 to 7.
Clock Division Ration | Sets GFIR filter clock division ration. Control range from 0 to 255.
Coefficients | Sets/Load GFIR filters coefficients. By default all set to 0.
| DC Corrector
Numbers of samples | Select the number of samples to average for Automatic DC corrector.
| IQ Corrector
Gain ch. Q | Sets Gain corrector value to channel Q. Control range from 0 to 2047. By default 2047.
Gain ch. I | Sets Gain corrector value to channel I. Control range from 0 to 2047. By default 2047.
Phase corrector | Sets Phase corrector value. Control range from 0 to 2047. By default 0.
| Decimation
HBD ratio | Sets HBD interpolation ratio. Possible control values 2, 4, 8, 16, 32 and bypass. By default bypassed.
| TSG
Swap I and Q signal | Swap IQ signals at test signal generator's output. By default not selected.
TSGFCW | Select frequency generated by test NCO. By default TSG frequency set to the TSP clock divided by 8.
TSGMODE | Select test signal generator mode: NCO or DC. By default NCO is selected.
Input Source | Select input source to TSP: ADC input or TSG. By default LML output is selected.
TSGC | TSG full scale control: 0 dB or -6 dB. By default set to -6 dB.
Load DC to I | Load TSG DC I register with value from DC_REG (hex) box.
Load ED to Q | Load TSG DC Q register with value from DC_REG (hex) box.
| NCO
Mode | Selects the CW or PHO (Phase offset) mode for NCO.
NCO bits to dither | Selects number of bits for NCO dithering.
FCW(MHz) | Type wanted NCO frequency.
PHO | Type wanted PHO frequency.
Set reference frequency | Set reference frequency for NCO. The frequency is the same as the TSP block.
Upload NCO | Program NCO
| AGC
AGC Mode | Selects the AGC mode: Bypass, AGC, RSSI mode.
AGC loop gain | Selects AGC loop gain.
AGC Average window size | AGC averaging window size is 2⁽AGC_AVG + 7) .
Desired output level | Selects desired output signal level
69 | P a g e
© Copyright 2014-2015 Lime Microsystems CC BY 3.0

### 1.35 CDS

The Clock Distribution System (CDS) controls are described in this this chapter.

Figure 44 GUI CDS tab
A picture of the tab is shown in Figure 44. A description of each function available in this tab is shown below in Table 21.

Table 22 GUI CDS control description
Parameter | Description
| Clock inversion
TX TSPB | TX TSP B channel clock inversion controls. By default clock is not inverted.
TX TSPA | TX TSP A channel clock inversion controls. By default clock is not inverted.
RX TSPB | RX TSP B channel clock inversion controls. By default clock is not inverted.
RX TSPA | RX TSP A channel clock inversion controls. By default clock is not inverted.
TX LMLB | TX LML interface B channel clock inversion control. By default clock is not inverted.
TX LMLA | TX LML interface A channel clock inversion control. By default clock is not inverted.
RX LMLB | RX LML interface B channel clock inversion control. By default clock is not inverted.
RX LMLA | RX LML interface A channel clock inversion control. By default clock is not inverted.
MCKL2 | MCLK2 clock inversion control. By default clock is not inverted.
MCKL1 | MCLK1 clock inversion control. By default clock is not inverted.
| Clock delay
MCLK2 | MCLK2 clock delays. Clock can be delayed by 400 ps, 500 ps, 600 ps and 700 ps. By default clock delayed 400 ps.
MCLK1 | MCLK1 clock delays. Clock can be delayed by 400 ps, 500 ps, 600 ps and 700 ps. By default clock delayed 400 ps.
TX TSP B | TX TSP B clock delays. Clock can be delayed by 400 ps, 500 ps, 600 ps and 700 ps. By default clock delayed 400 ps.
70 | P a g e
© Copyright 2014-2015 Lime Microsystems CC BY 3.0

TX TSP A | TX TSP A clock delays. Clock can be delayed by 400 ps, 500 ps, 600 ps and 700 ps. By default clock delayed 400 ps.
RX TSP B | RX TSP B clock delay. Clock can be delayed by 200 ps, 500 ps, 800 ps and 1100 ps. By default clock delayed 200 ps.
RX TSP A | RX TSP A clock delay. Clock can be delayed by 200 ps, 500 ps, 800 ps and 1100 ps. By default clock delayed 200 ps.
TX LML B | TX LML B clock delay. Clock can be delayed by 400 ps, 500 ps, 600 ps and 700 ps. By default clock delayed 400 ps.
TX LML A | TX LML A clock delay. Clock can be delayed by 400 ps, 500 ps, 600 ps and 700 ps. By default clock delayed 400 ps.
RX LML B | RX LML B clock delay. Clock can be delayed by 200 ps, 500 ps, 800 ps and 1100 ps. By default clock delayed 200 ps.
RX LML A | RX LML A clock delay. Clock can be delayed by 200 ps, 500 ps, 800 ps and 1100 ps. By default clock delayed 200 ps.

### 1.36 BIST

The Build-In Self-Test (BIST) modules for SXT, SXR and CGEN controls are described in this chapter.


Figure 45 GUI BIST tab
The BIST modules are used for the test proposes only. There is one test vector generator which supplies the test vectors for CGEN, SXT and SXR modules. After pressing the ‘Read BIST’ button the test results (test vector signature) will be displayed for the selected block.

A picture of the tab is shown in Figure 45. A description of each function available in this tab is shown below in Table 23.

71 | P a g e
© Copyright 2014-2015 Lime Microsystems CC BY 3.0

Parameter; Description; BIST; Enable CGEN BIST; Enables CGEN BIST. Disabled by default.; Enable; transmitter; 1.37 SPI; Write; Address (Hex); Register address in HEX format.; Value (Hex); Register value in HEX format.; Status; Previously executed command status.; Read

Table 23 GUI BIST control description

Enable receiver BIST Enables SXR BIST. Disabled by default.
BIST
Start delta sigma

Enables SXT BIST. Disabled by default.

Enables delta sigma BIST. Disabled by default.

This is used for test proposes only. Using this tab, every SPI register can be programmed using
the register map description. Every SPI register of the LMS7002M can be read back. A picture of
the tab is shown in Figure 46. A description of each function available in this tab is shown below
in Table 24.

Figure 46 GUI SPI tab

Table 24 GUI SPI control description

© Copyright 2014-2015 Lime Microsystems CC BY 3.0

Read Values (Hex) | Register value in HEX format.
Status | Previously executed command status.
Batch Read | Executes multiple reads from selected register. The read number selected by ReadCount.
ReadCount | Set read back function count number.
Write Tester | Writes and read to selected register 100 times.
Triple check data | When selected repeats function three times.
Save to file | If selected save function results to txt file to selected location.
Switch channel | Selects read/write channel.
73 | P a g e
© Copyright 2014-2015 Lime Microsystems CC BY 3.0

# Appendix A: Test Equipment Setup

### 1.38 Introduction

This section lists the recommended test equipment to use with the EVB7. It also provides detailed setup procedures for the Agilent MXG when used with EVB7. Note the set up procedure is only required when using the analogue TX inputs of the LMS7002M. This procedure is not required when the LMS7002M chip is driven digitally by a baseband processor.

### 1.39 Recommended Test Equipment

The following test equipment is recommended for the testing of EVB7. It is possible to use other test equipment, but the alternatives may not provide all the necessary features.

- N5182A MXG
- Differential Arbitrary Waveform Generator Option 1EL
- N9020A MXA DC - 6 GHz
- NF personality
- Phase Noise personality
- WCDMA personality
- LTE personality
- Agilent Power Supply 5V
- Agilent 384C Noise Source
- 15 dB ENR

### 1.40 Agilent MXG Setup

The front panel of the MXG is shown in Figure 47.

74 | P a g e
© Copyright 2014-2015 Lime Microsystems CC BY 3.0

Figure 47 Agilent N5181A/82A MXG Front Panel

### 1.40.1. Setting Common Mode Voltage

To apply 0.3 V common mode offset voltage to the IQ outputs:

1. Press ‘IQ’ button (24)
2. Press ‘IQ offsets (on/off)’ softkey (3. softkey 4)
3. Press ‘external output adjustments’ softkey (3. softkey 4)
4. Press ‘Common Mode I/Q offset’ softkey (3. softkey 2)
5. type 0.3 on number pad (4), press ‘V’ softkey (3. softkey 1)
6. 0.3 V should appear on the display next to the ‘Common Mode I/Q offset’ softkey
7. Press return
i. Check text next to ‘I/Q Adjustments’ softkey (3. softkey 1) highlights ‘off/on’
ii. If not press ‘I/Q Adjustments’ softkey (3. softkey 1), highlighted section should alternate between on and off when pressed.
iii. press return
iv. Check text next to ‘I/Q’ softkey (3. softkey 1) highlights ‘off/on’
v. If not press ‘I/Q’ softkey (3. softkey 1), highlighted section should alternate between on and off when pressed.

There should now be a 0.3 V common mode voltage on the differential IQ connections on the signal generator. This can be verified by measuring the DC level of each of the 4 differential I/Q lines with a multimeter.

Note: Very small DC offset levels in the transmit IQ path can result in LO breakthrough levels changing in the transmit chain. To eliminate or minimize this effect the following practices should be followed:

- The IQ cables should be of equal length.
- Once I/Q gain and phase calibration is completed, connections should not be modified.
- Cables and connections should not be moved once the I/Q gain and phase calibration is completed.
75 | P a g e
© Copyright 2014-2015 Lime Microsystems CC BY 3.0

### 1.40.2. Enabling the Arbitrary Waveform Generator

The arbitrary waveform generator will run test vectors which are downloaded to it. These can be generated either with Agilent’s “Signal Studio” program or can be generated independently via “Matlab” or C.

Lime has a number of test vector files which are used for test and calibration of the LMS7002M as follows:

- DC.wfm – Differential DC tone for TX CW testing (clock 52 MHz).
- onetone1.wfm - single tone at 1 MHz offset for sideband suppression calibration/test (clock 52 MHz).
- twotone.wfm - two tone signal for linearity testing for MXG and LMS7002M use MXG IQ scaling factor of 30% (clock 52 MHz).
- wcdma31.wfm - TM2 WCDMA signal - use MXG IQ scaling factor of 30% (clock=15.36 MHz).
- EDGE3.wfm - GSM EDGE modulated test signal - (clock=13 MHz).

To download files to the signal generator follow the process described in section 1.40.3.

To apply the correct file

1. Press ‘Mode’ button (23)
2. Press ‘Dual Arb’ softkey (3. softkey 1)
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

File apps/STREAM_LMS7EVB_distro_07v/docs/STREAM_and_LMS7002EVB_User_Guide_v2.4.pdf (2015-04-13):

Lime Microsystems Limited

Surrey Technology Centre
Occam Road
The Surrey Research Park
Guildford, Surrey GU2 7YG
United Kingdom
Tel: | +44 (0) 1483 685 063
e-mail: | enquiries@limemicro.com

# Universal Radio Development Platform User Guide

- User Guide for STREAM & UNITE7002 boards -

© Copyright 2014-2015 Lime Microsystems CC BY 3.0

Version: 2.4 Last modified: 13/04/2015

REVISION HISTORY; Date; Version; Description of Revisions; Initial version; Corrected Formatting Issues; STREAM hardware description added; Formatting correction; Updated software, calibration and programing procedures; Added section to load the bitstream files; Updated copyright notice and added licence info

Universal Radio Development Platform User Guide

The following table shows the revision history of this document:

## Table of Contents

## Introduction

The universal radio development platform, based on the Stream board and flexible, multi standard Lime transceiver boards, enables developers to implement their products for a wide variety of wireless communication applications efficiently and cost effectively. The main ideas are to:

- Accelerate the evaluation and development time.
- Experiment and evaluate new modulation schemes and wireless systems, operating over a wide frequency range.
- Easily modify and manufacture the platform for new designs using the Open Source database for the complete kit.

This document provides the following information:

- Design kit content description and first demo example
- Software installation, setup and programming of the Stream board.
- Example files for running the complete platform.

## Complete Development Package

Complete design kit content for Stream and UNITE7002 board showed in Figure 1.

Figure 1 Stream & UNITE7002 complete package

Development kit content:
- Stream board
- UNITE7002 board
- 12 volt / 5 ampere power supply
- Micro-USB3 to Type A Male adapter cable
- Mini-USB2 cable
- Power cable with banana plugs for UNITE7002
- USB stick containing [link]: (https://github.com/myriadrf/Stream)
- Lime7Suite GUI and register setup for LMS7002M transceiver
- FPGA bitstreams and project files
- USB3 controller drivers
- Waveforms
- Windows drivers for UNITE7002

## Stream Board Key Features

The STREAM development board provides a hardware platform for developing and prototyping high-performance and logic-intensive digital and RF designs using Altera’s Cyclone IV FPGA and Lime Microsystems transceiver. The board provides a wide range of peripherals and memory interfaces to connect to Lime’s current offering of transceiver evaluation boards and Open Source MyriadRF boards.

For more information on the following topics, refer to the respective documents:
- RFDIO connector RF evaluation boards, refer to MyriadRF project [link] (http://myriadrf.org/projects/)
- Cyclone IV device family, refer to Cyclone IV Device Handbook [link] (http://www.altera.com/literature/hb/cyclone-iv/cyclone4-handbook.pdf)
- LMS7002M transceiver resources [link] (http://www.limemicro.com/products/field-programmable-rf-ics-lms7002m/)
- LMS6002D transceiver resources [link] (http://www.limemicro.com/products/field-programmable-rf-ics-lms6002d/)

Stream board features:
- FPGA Features
- Cyclone IV EP4CE40F23C7N device in 484-pin FBGA
- 39’600 LEs
- 1134 Kbits embedded memory
- 116 embedded 18x18 multipliers
- 4 PLLs
- FPGA Configuration
- JTAG mode configuration
- Serial mode configuration via Cypress FX3
- Memory Devices
- 2x64MB (16bit) SDRAM
- Micro SD Card Socket
- SD card access via USB HOST controller
- Ethernet
- USB HOST controller
- 10/100/1000 Mb/s RJ45
- 3 status LEDs
- USB Interface
- Embedded Dual USB HOST 2nd generation
- Cypress FX3 Supper Speed USB 3rd generation controller
- Display
- DVI transmitter (TFP410), HDMI Jack
- High-Speed mezzanine connectors
- FMC (FPGA Mezzanine Card) LPC connector for UNITE7002 board
- RFDIO (FX10-80P) High speed connector for MyriadRF family boards

- Connections
- Mictor E5346A Agilent Test Equipment connector
- 12V DC power jack
- GPIOs headers
- 2x USB2A Jack
- USB3B Micro Jack
- Clock System
- 30.72MHz on board oscillator
- Programmable clock generator for the FPGA reference clock input and RF mezzanine boards
- Locking to external clock circuit
- U.FL clock input
- Board Size 110mm x 124mm (4.3” x 4.9”)

### 1.1 STREAM board overview

Stream board version 2, revision 1 picture with highlighted major connections showed in the .

Featured Devices; Board Reference; Type; Description; FPGA; Cyclone IV EP4CE40F23C7N, 484-FBGA; RFDIO connector; Provides digital data and control to MyriadRF; boards; FMC connector; Provides digital data and control to UNITE7002; USB3.0; microcontroller; USB2.0; DVI transceiver; Ethernet GbE Controller

Figure 2 STREAM Development Board

Board components description showed in the Table 1 and Table 2.

Table 1. Board components

board
Cypress FX3 Supper Speed USB 3rd generation
controller
Embedded Dual USB HOST 2nd generation


Configuration, Status and Setup Elements

FPGA programming pinheader for Altera USB-
Blaster download cable

Standard configuration scheme is selected

General User Input/Output

Clock Circuitry; Board Reference; Type; Description; TCXO; E6245LF 30.72MHz oscillator; Programmable clock generator for the FPGA; ADF4002 phase/frequency detector; U.FL connector; RF connector for external clock; LED; Illuminates than onboard oscillator phase is; DC input jack; 12V DC power supply; Illuminates than board is powered on; Jumper; Jumper to provide 12V DC to FMC connector

reference clock input and RF boards

locked to external clock
Power Supply

### 1.2 STREAM board architecture

The heart of the STREAM Development board is Altera Cyclone IV FPGA. It’s main function is to transfer digital data between MyriadRF board or UNITE7002 to PC through USB or Ethernet ports. The block diagram for Stream board showed in the Figure 3.


Figure 3 STREAM Development Board Block Diagram

### 1.2.1 LMS7002M based boards connectivity (FMC/RFDIO)

Stream board is designed to interface with UNITE7002 board via FMC connector and MyriadRF7 boards via to FX10-80P connector. The FX10-80P connector pinout has been standardized and known as RFDIO standard [link]. (https://github.com/myriadrf/reference-development-kit/tree/master/docs)

LMS7002M digital interface requires 12-bit data, IQSEL_Enable, FCLK, MCLK, TXNRX signals for each transmit and receive ports. The simplified interface block diagram showed in the Figure 4.

Figure 4 Simplified MyriadRF (RFDIO connector) and UNITE7002 (FMC connector) connection to FPGA block diagram

The interface and control signals are described below:

- Digital Interface Signals: MyriadRF7 and UNITE7002 boards are using same data bus DIQ1_D[11:0] and DIQ2_D[11:0], IQSEL_Enable1 and IQSEL_Enable2, FCLK1 and FCLK2, MCLK1 and MCLK2 signals to transfer data to/from FPGA. Indexes 1 and 2 indicate transceiver digital data PORT-1 or PORT-2. Any of these ports can be used to transmit or receive data. By default PORT-1 is selected as transmit port and PORT-2 is selected as receiver port. The FCLK# is input clock and MCLK# is output clock for LMS7002M transceiver. TXNRX signals sets ports directions. For LMS7002M interface timing details refer to LMS7002M transceiver datasheet page 12-
13. [link]. (http://www.limemicro.com/wp-content/uploads/2015/03/LMS7002M-DataSheet-2-4r0.pdf)
- SPI Interface: LMS7002M transceiver is configured via 4-wire SPI interface; LMS_SPI_MOSI, LMS_SPI_MISO, LMS_SPI_SCK, LMS_SPI_CS. The SPI interface controlled from FPGA Bank 8 (2.5V).
- I2C Interface: used to control external clock synthesizer on UNITE7002 board. The signals LMS_I2C_CLK, LMS_I2C_DATA connected to FPGA Bank 8 (2.5V).
- MIPI Interface: MIPI_DATA, MIPI_SCK – MyriadRF board RF tuners programming interface connected to FPGA Bank 8 (2.5V).
- RSSI_ADC Interface: RSSI_ADC_0, RSSI_ADC_1 – LMS7002M receiver power detector analog output. Index corresponds to MIMO channel. These signals are connected to 12-bit ADCs (U9, U10). ADCs are controlled via the SPI interface by FPGA signals: LMS_SPI_SCK, LMS_SPI_MISO, ADC_SPI_CS0, ADC_SPI_CS1. The signals connected to FPGA Bank 8 (2.5V).
- GPIO signals: LMS_GPIO[3:0] – are used only to control MyriadRF boards RF switches. The signals connected to FPGA Bank 7 (3.3V).
- Control Signals: these signals are used for optional functionality:
- LMS_RXEN, LMS_TXEN – receiver and transmitter enable/disbale signals connected to FPGA Bank 8 (2.5V).
- LMS_RESET – LMS7002M reset connected to FPGA Bank 7 (3.3V).
- MyriadPRSNT – indication signal for MyriadRF board. If board is not connected to RFDIO port, signal is “Logic High”, if board is connected - signal is “Logic Low”.

- LMSS_iqsel1_dir, LMS_iqsel2_dir – IQSEL_Enable direction control signal for UNITE7002 board digital buffers. By default LMS_iqsel1_dir is “1” and LMS_iqsel2_dir is “0”. This condition configures IQSEL_Enable1 as transmitter (input signal) for LMS7002M; IQSEL_Enable2 is configured as receiver (output signal) from LMS7002M.
- LMS_dio_dir_ctrl1, LMS_dio_dir_ctrl2 – digital data direction control for UNITE7002 board buffers, by default DIQ1_D[11:0] is transmitter data and DIQ2_D[11:0] is receiver data.
- LMS_dio_buff_oe – UNITE7002 board digital buffers outputs enable signal, by default outputs are enabled. This signal is used to prevent short circuit between buffers outputs and LMS7002M outputs. Buffer outputs must be enabled after other signal directions are set.
- LMS_SBEN – is additional SPI enable pin used to control optional phase locked loop on UNITE7002 board. This controlled is used when frequency error of the crystal oscillator on UNITE7002 board has to be calibrated with external equipment. The LMS_SBEN is a “chip select” signal for SPI interface. The additional PLL is using same SPI lines as LMS7002M – LMS_SPI_SCK, LMS_SPI_MISO.

### 1.2.2 SDRAM

Stream board has two 64MB (16bit bus) SDRAM ICs (W9751G6KB [link]) (https://www.winbond.com/resource-files/da00-w9751g6kbg1.pdf) connected to double data rate pins on Cyclone IV 1.8V Bank 3 and Bank 4. The memory can be used for data manipulation at high date rates between transceiver and FPGA. The memory is also used to load Linux operation system.

### 1.2.3 USB 3.0 controller

Lime7Suite software controls Stream board vai the USB3 microcontroller (CYUSB3013 [link]). (http://www.cypress.com/?docID=50647) The data transfer to/from the board, SPI communication, FPGA configuration is done via the USB3 controller. The controller signals description showed below:

- FX3 digital data FX3_DQ[15:0] is connected to Cyclone IV 1.8V Bank 2.
- FX3_CTL[12:0] – FX3 control signals.
- FX3 GPIO[5:0] are available on J4 pinheader.
- FX3_LED[2:0] (LD1, LD2, LD3) – user defined debugging LEDs.
- FX3_GPIO42, FX3_GPIO43, FX3_GPIO44 – connected to Cyclone IV 3.3V Bank 7 user defined GPIOs.
- FX3_CONF_DONE, | FX3_NSTATUS, | FX3_DATA0, | FX3_NCONFIG,
FX3_DCLK – are used to program FPGA via FX3 controller.
- PMODE[2:0] – boot options, by default boot from SPI and USB boot is enabled. If J3 jumper is present FX3 will boot from IC5 flash memory.

- FX3 SPI interface is used to program IC5 flash memory, boot from IC5 flash memory, read/write U1 flash memory. Also FX3 SPI is connected to FPGA 3.3V Bank 7. U1 flash memory is used to load FPGA configuration via FX3 controller.
- SW2 – resets FX3, all IOs are in tristate state during a hard reset.
- J5 – FX3 JTAG programming/debugging pin header.

### 1.2.4 Ethernet Controller

Stream board is equipped with Ethernet (Micrel KSZ9021GN [link]) (http://www.micrel.com/_PDF/Ethernet/datasheets/ksz9021gn_ds.pdf) port that can be used as alternative high speed data interface to PC. By default Ethernet port is configured to GMII/MII mod. 8-bits transmit data and 8-bits receive data are connected to FPGA Bank 5 (3.3V). The controller signals description showed below:

- CLK125_EN – enables/disables 125 MHz clock output from pin 55 (CLK125_NDO), by default it is “0” and clock output is disabled.
- LED_MODE – default “0”, tri-color dual LED mode
- Ethernet controller physical address is set to “00000”.
- SW3 – button, resets Ethernet controller

### 1.2.5 DVI controller

DVI controller (TI TFP410 [link]) (http://www.ti.com/lit/ds/symlink/tfp410.pdf) 12-bit data bus DVI_d[11:0] and control signals are connected to FPGA Bank 1 (2.5V).

### 1.2.6 Mictor connector

Mictor 38-pin connector (J13) can be used as extension to Agilent Logic Analyzer equipment. 2x 16-bit data bus connected to FPGA Bank 6 (3.3V).

### 1.2.7 USB 2.0 Host

The USB 2.0 Host controller (VNC2-48L1B [link]) (http://www.ftdichip.com/Support/Documents/DataSheets/ICs/DS_Vinculum-II.pdf) data bus VIN_d[7:0] connected to FPGA Bank 5 (3.3V).

USB2 controller can be programmed via FPGA using VIN_debug, VIN_reset, VIN_prog signals or via “VNC2 Debug Module” J11 connector

The microSD card is hosted by USB2 controller. The control commands are issued via the SPI interface.

### 1.2.8 Clock Distribution

Stream board has onboard 30.72 MHz TVCXO that is reference clock for FPGA (signal CLK_FPGA2) and for MyriadRF board (signal CLK_IN). See block diagram of the clock distribution system in Figure 5.

The optional clock generator (Si5351C [link]) (http://www.silabs.com/Support%20Documents/TechnicalDocs/Si5351-B.pdf) can generate any reference clock frequency, starting from 8 kHz – 160 MHz, for MyriadRF and UNITE7002 boards digital interface clocks (FCLK1, FCLK2), FPGA reference clocks (CLK_FPGA0, CLK_FPGA1).

The onboard PLL (ADF4002 [link]) (http://www.analog.com/media/en/technical-documentation/data-sheets/ADF4002.pdf) is used to synchronize onboard TVCXO with external equipment (via X1 U.FL connector) to calibrate frequency error. The ADF4002 is programmed by FX3 controller. The LD5 - illuminates when onboard oscillator frequency error is corrected.

X1 connector can also be used to supply external reference clock (fitting R151, removing R150).

TCXO 30.72 MHz; UNITE7002 (FMC); MyriadRF (RFDIO); Clock Generator IC11; Altera Cyclone IV; CLK_IN; CLK_FPGA2; FCLK1; FCLK2; CLK_FPGA1; CLK_FPGA0; X1 U.FL Connector

Figure 5 Clocks block diagram

## Getting Started with Design Kit

The Stream and UNITE7002 design kit comes with Lime7Suite software, which enables the control of the LMS7002M transceiver, run the “FFTviewer” to analyse the ADC spectrum, load wanted waveforms to FPGA. Two example waveforms are available in the kit:

- Single tone generated in the digital domain by a programmable logic-based
- W-CDAM TM1 with 64ch waveform

The digital signals are driven from the Altera FPGA to the DAC within the LMS7002M to produce a complex analog I&Q output, then mixed with an adjustable frequency RF carrier through the quadrature modulator. The resulting RF signal is transmitted to the analyser through the TX-side. The incoming RF signal is converted to baseband through the quadrature de-modulator, digitized through the ADC and sent to the FPGA. The digitized signal can be analysed with Lime7Suite software.

### 1.3 DEMO Setup

The demo setup is showed in Figure 6 . This demo uses single control software “lms7suite.exe” to control UNITE7002 board and Stream board.

Figure 6 Demo Setup for LMS7002EVB and Stream board

### 1.4 DEMO Procedure

The DEMO procedure steps are showed below:

1. Connect the DEMO setup as shown in Figure 6. To measure Tx EVM the VSA89601B software is required.
2. Power up the kit.
3. Connect lms7suite software to the boards
4. Setup UNITE7002 board:
a. Load the pre-set file
b. Synchronize Analyser with UNITE7002 board
5. Calibrate TX path
6. Load the test waveform
7. Measure EVM for Tx Path
8. Run FFTviewer to analyse receiver
9. Calibrate Rx path
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

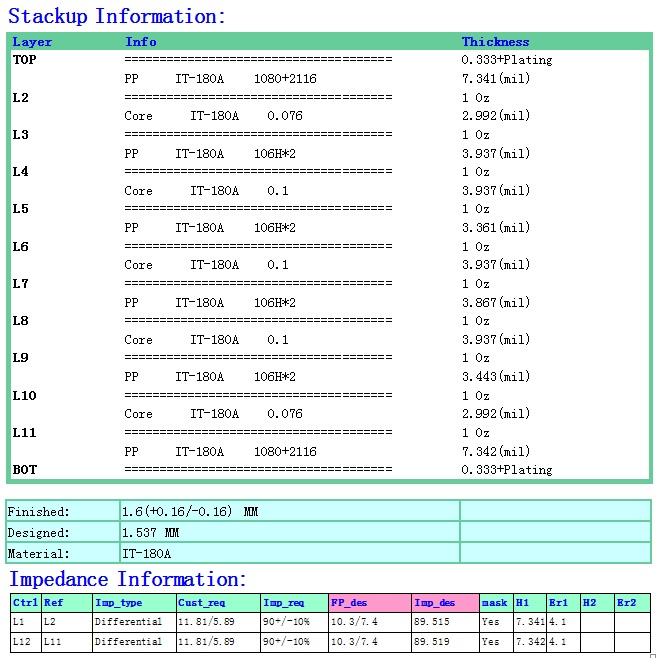
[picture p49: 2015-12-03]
hardware/uSTREAM/v2/Manufacturing/Stackup_12L.jpg

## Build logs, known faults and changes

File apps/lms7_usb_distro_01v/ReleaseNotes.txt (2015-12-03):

uStream_uMyriad7_distro_v01
===========================
Release date: 14 Oct 2015
Change log:
  1. Initial project release for uStream and uMyriadRF boards.

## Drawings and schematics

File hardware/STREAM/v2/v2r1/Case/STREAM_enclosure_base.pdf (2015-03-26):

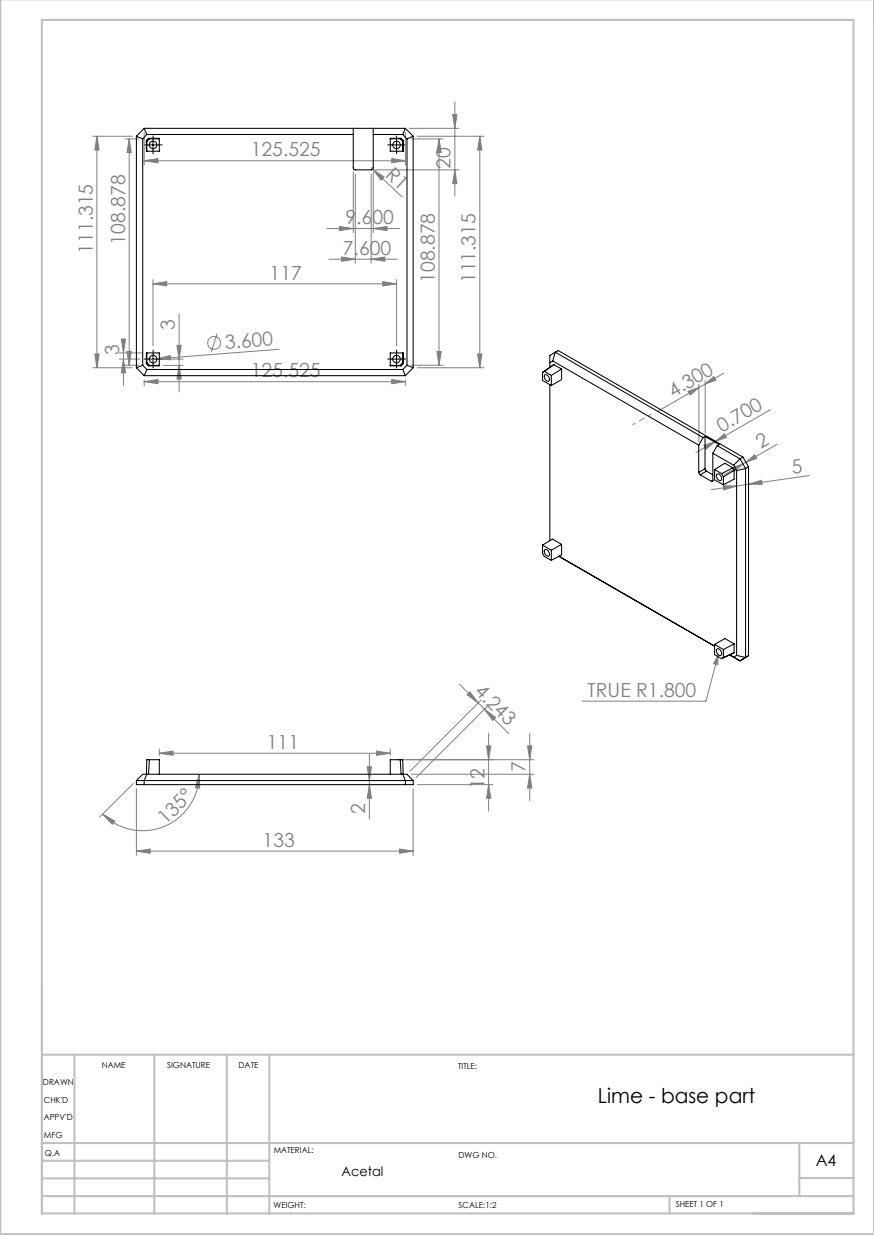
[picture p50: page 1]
TRUE R1.800; SCALE:1:2; SHEET 1 OF 1

DRAWN CHK'D APPV'D MFG | NAME | SIGNATURE | DATE | TITLE: Lime - base part

Q.A | | | | MATERIAL: DWG NO. Acetal | A4

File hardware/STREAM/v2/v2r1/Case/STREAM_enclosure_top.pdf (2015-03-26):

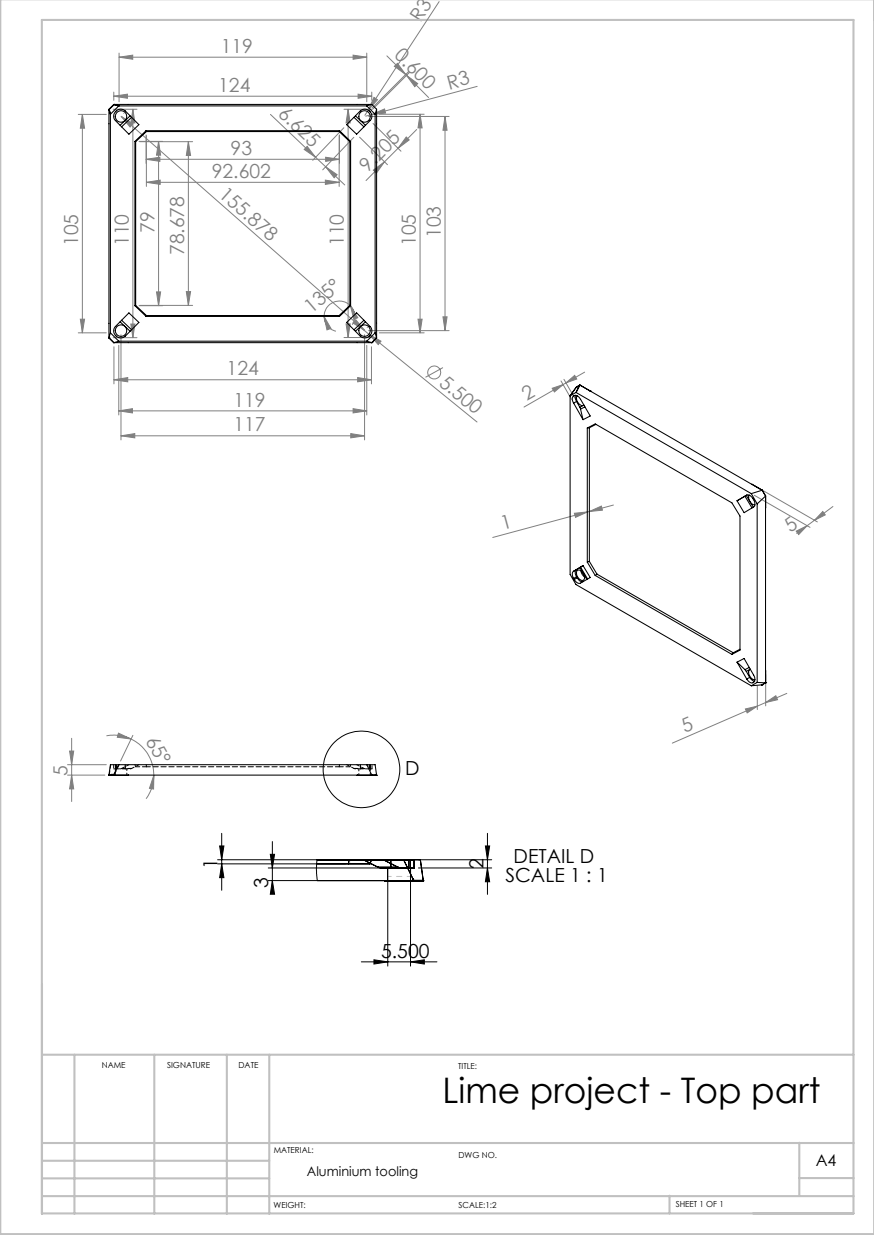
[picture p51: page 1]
DETAIL D SCALE 1 : 1; SCALE:1:2; SHEET 1 OF 1

NAME | SIGNATURE | DATE | TITLE: Lime project - Top part

MATERIAL: DWG NO. Aluminium tooling | A4

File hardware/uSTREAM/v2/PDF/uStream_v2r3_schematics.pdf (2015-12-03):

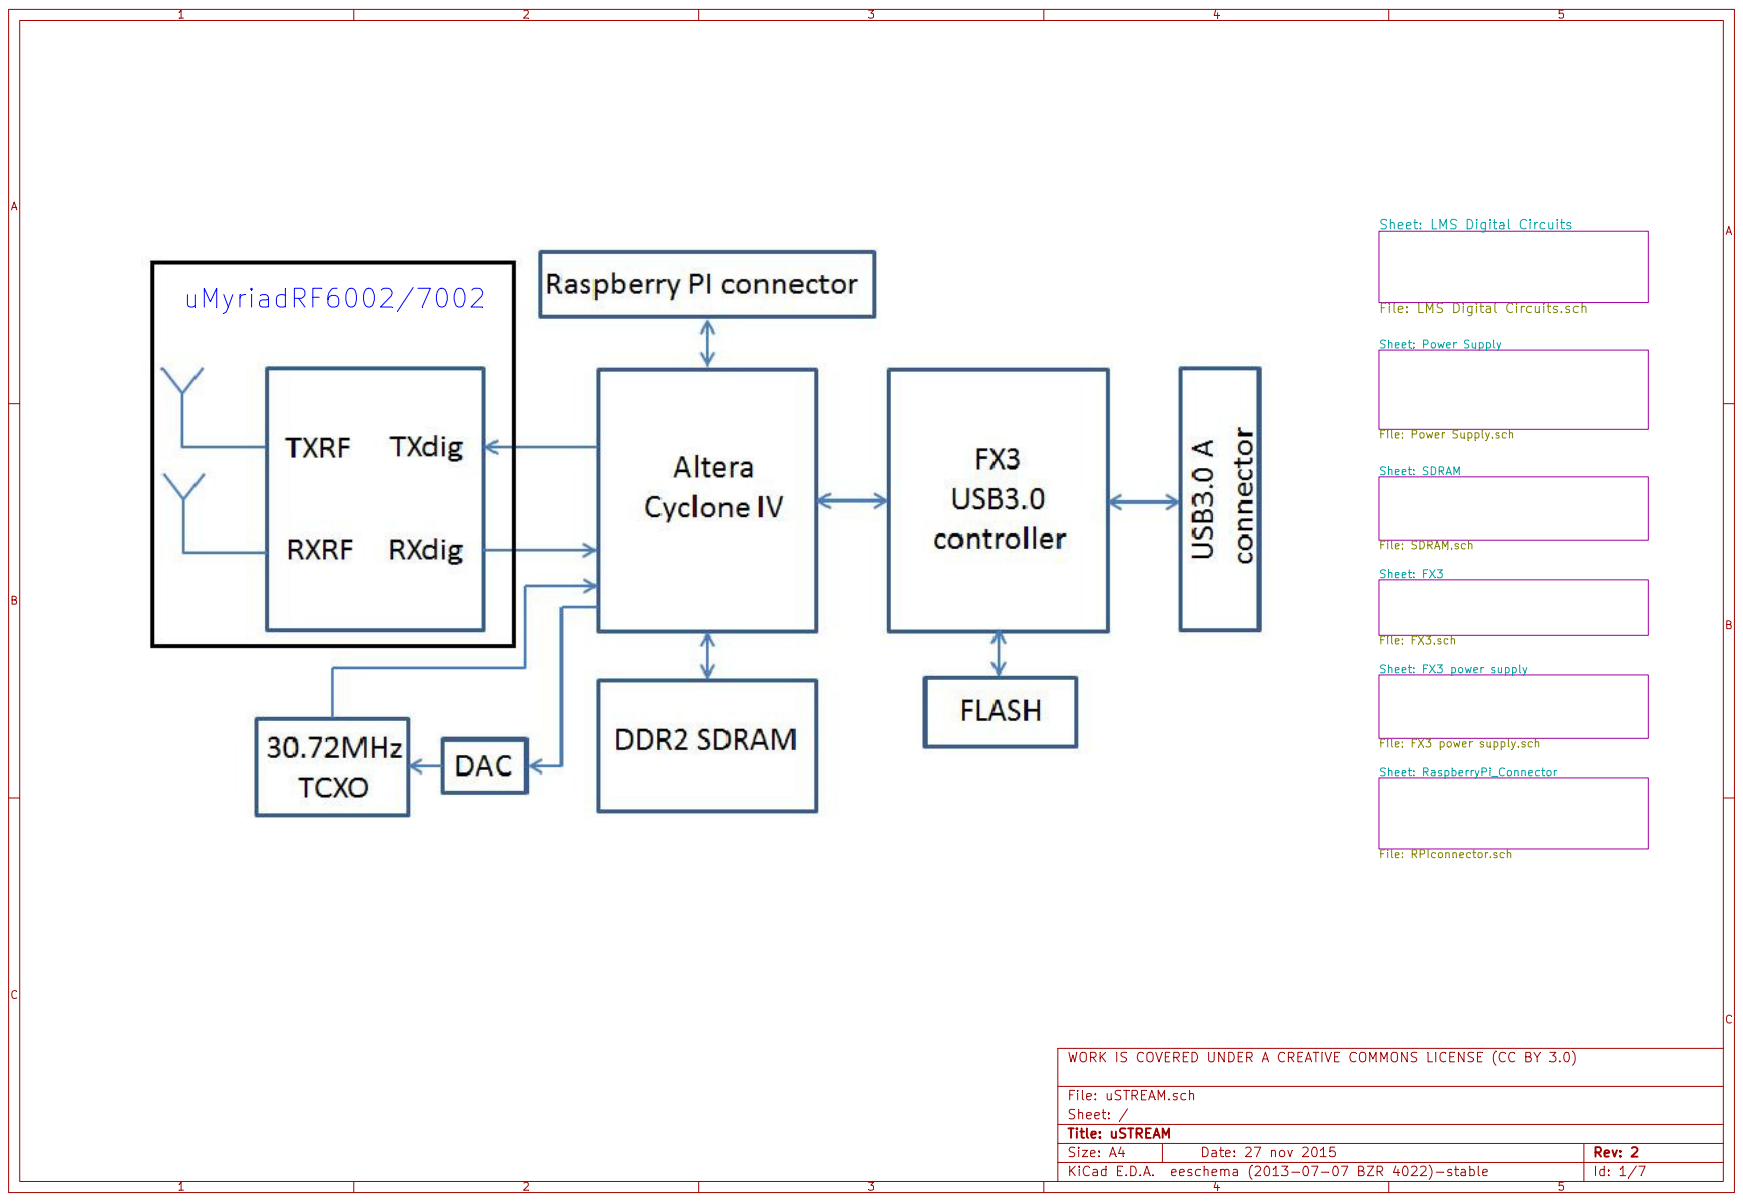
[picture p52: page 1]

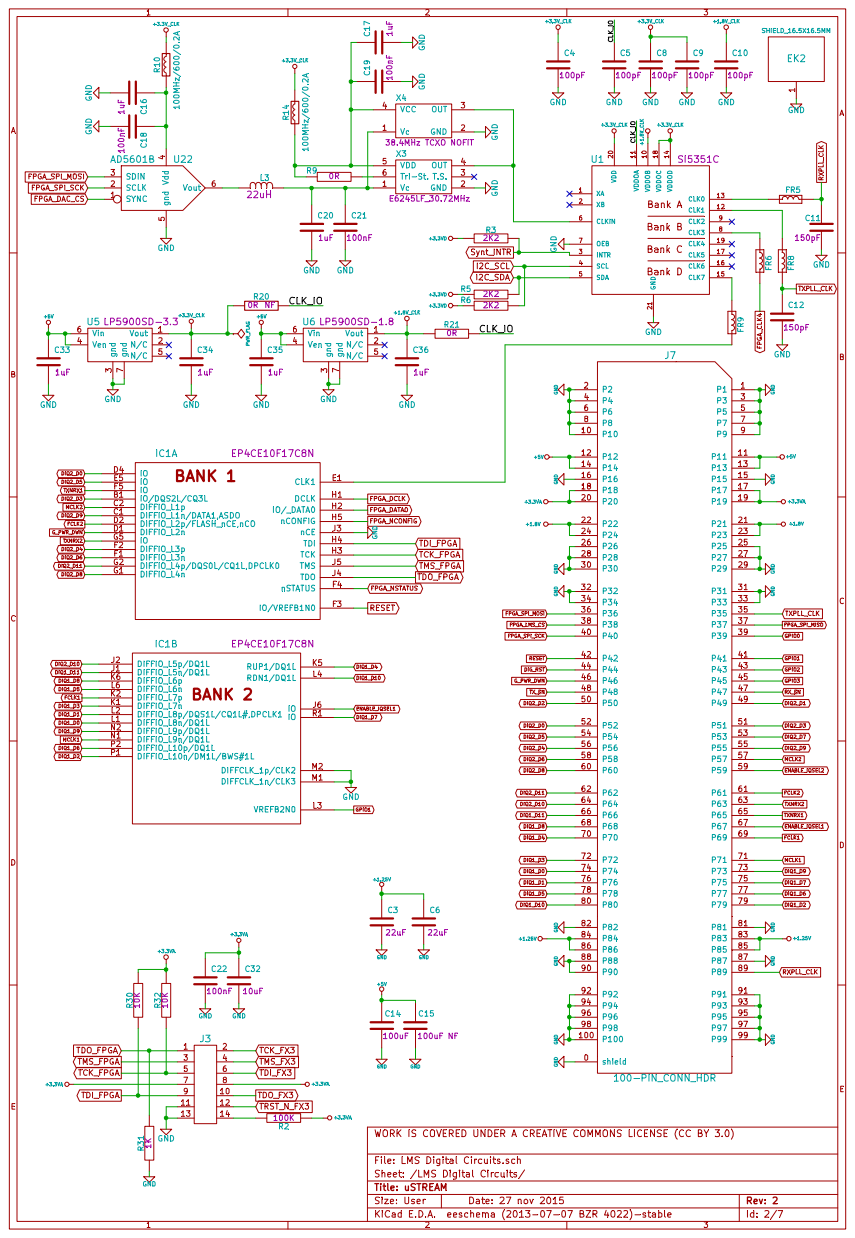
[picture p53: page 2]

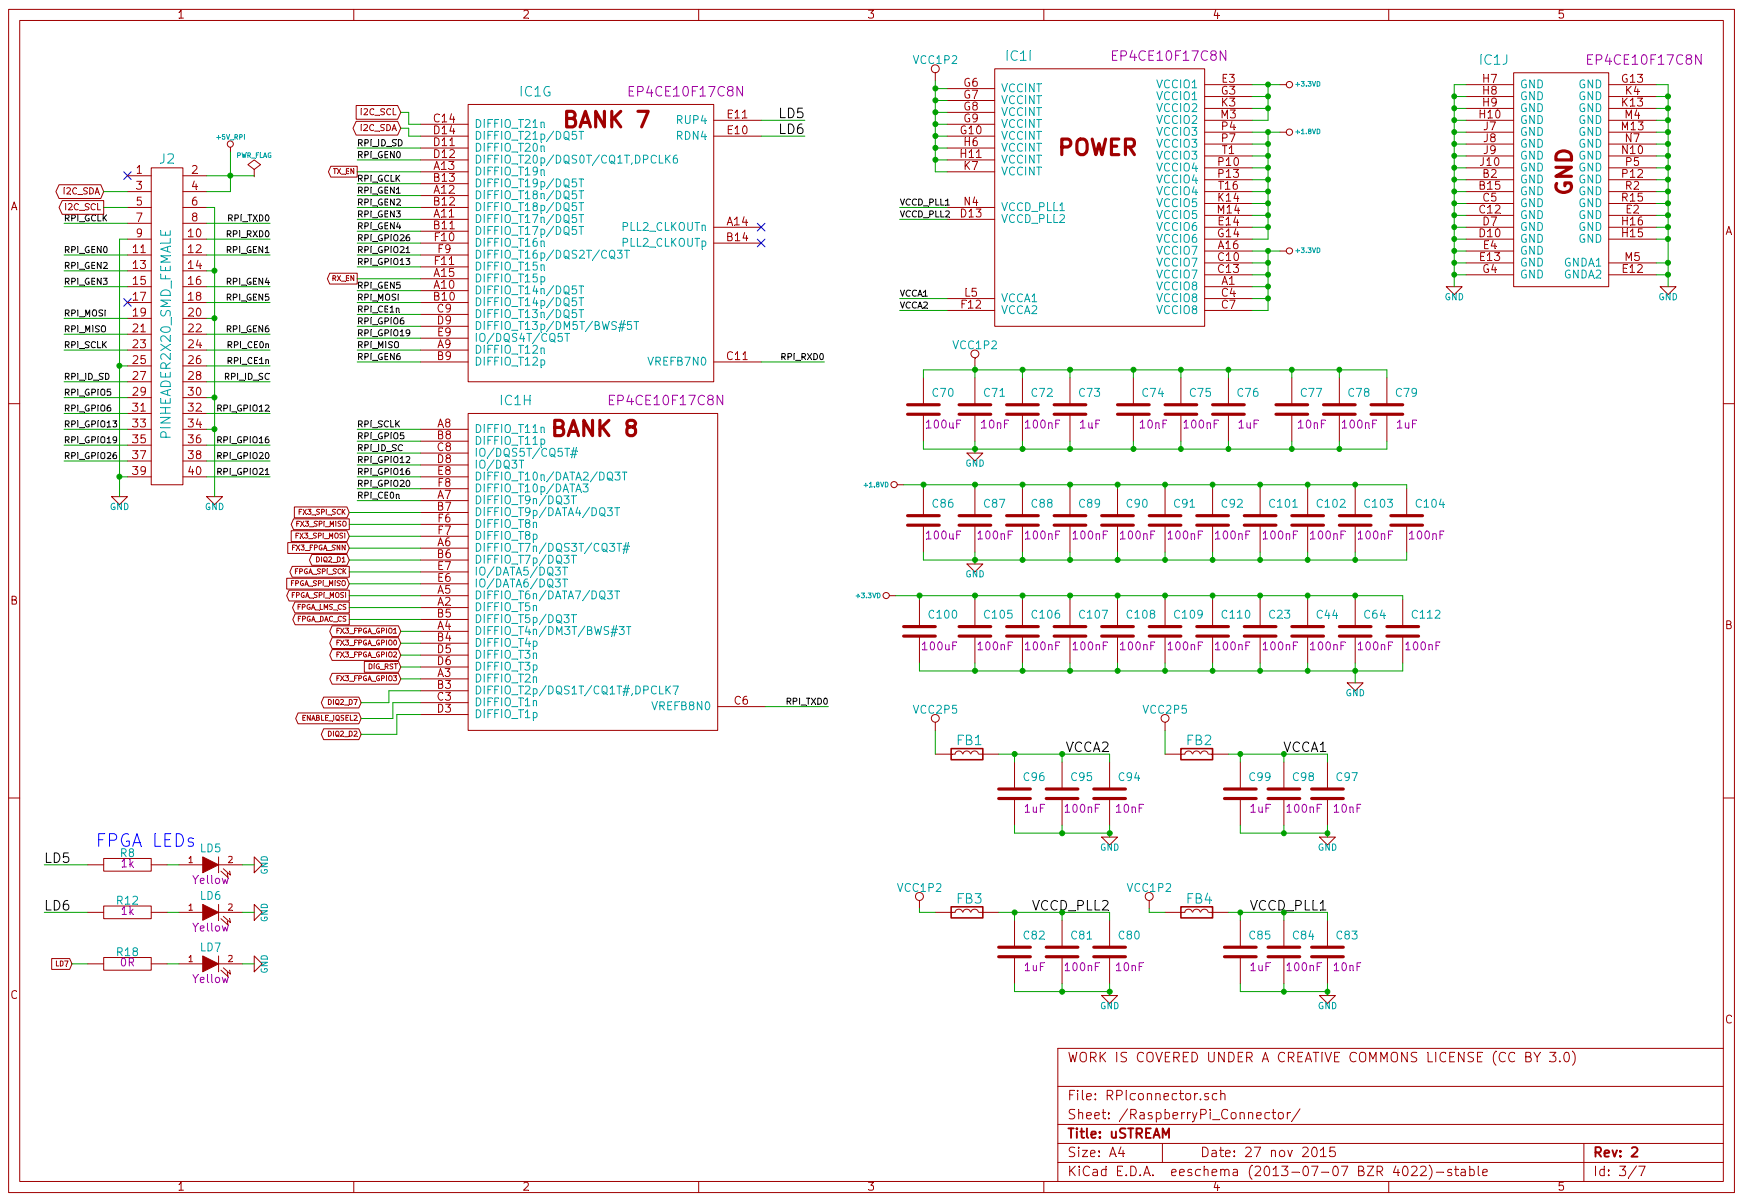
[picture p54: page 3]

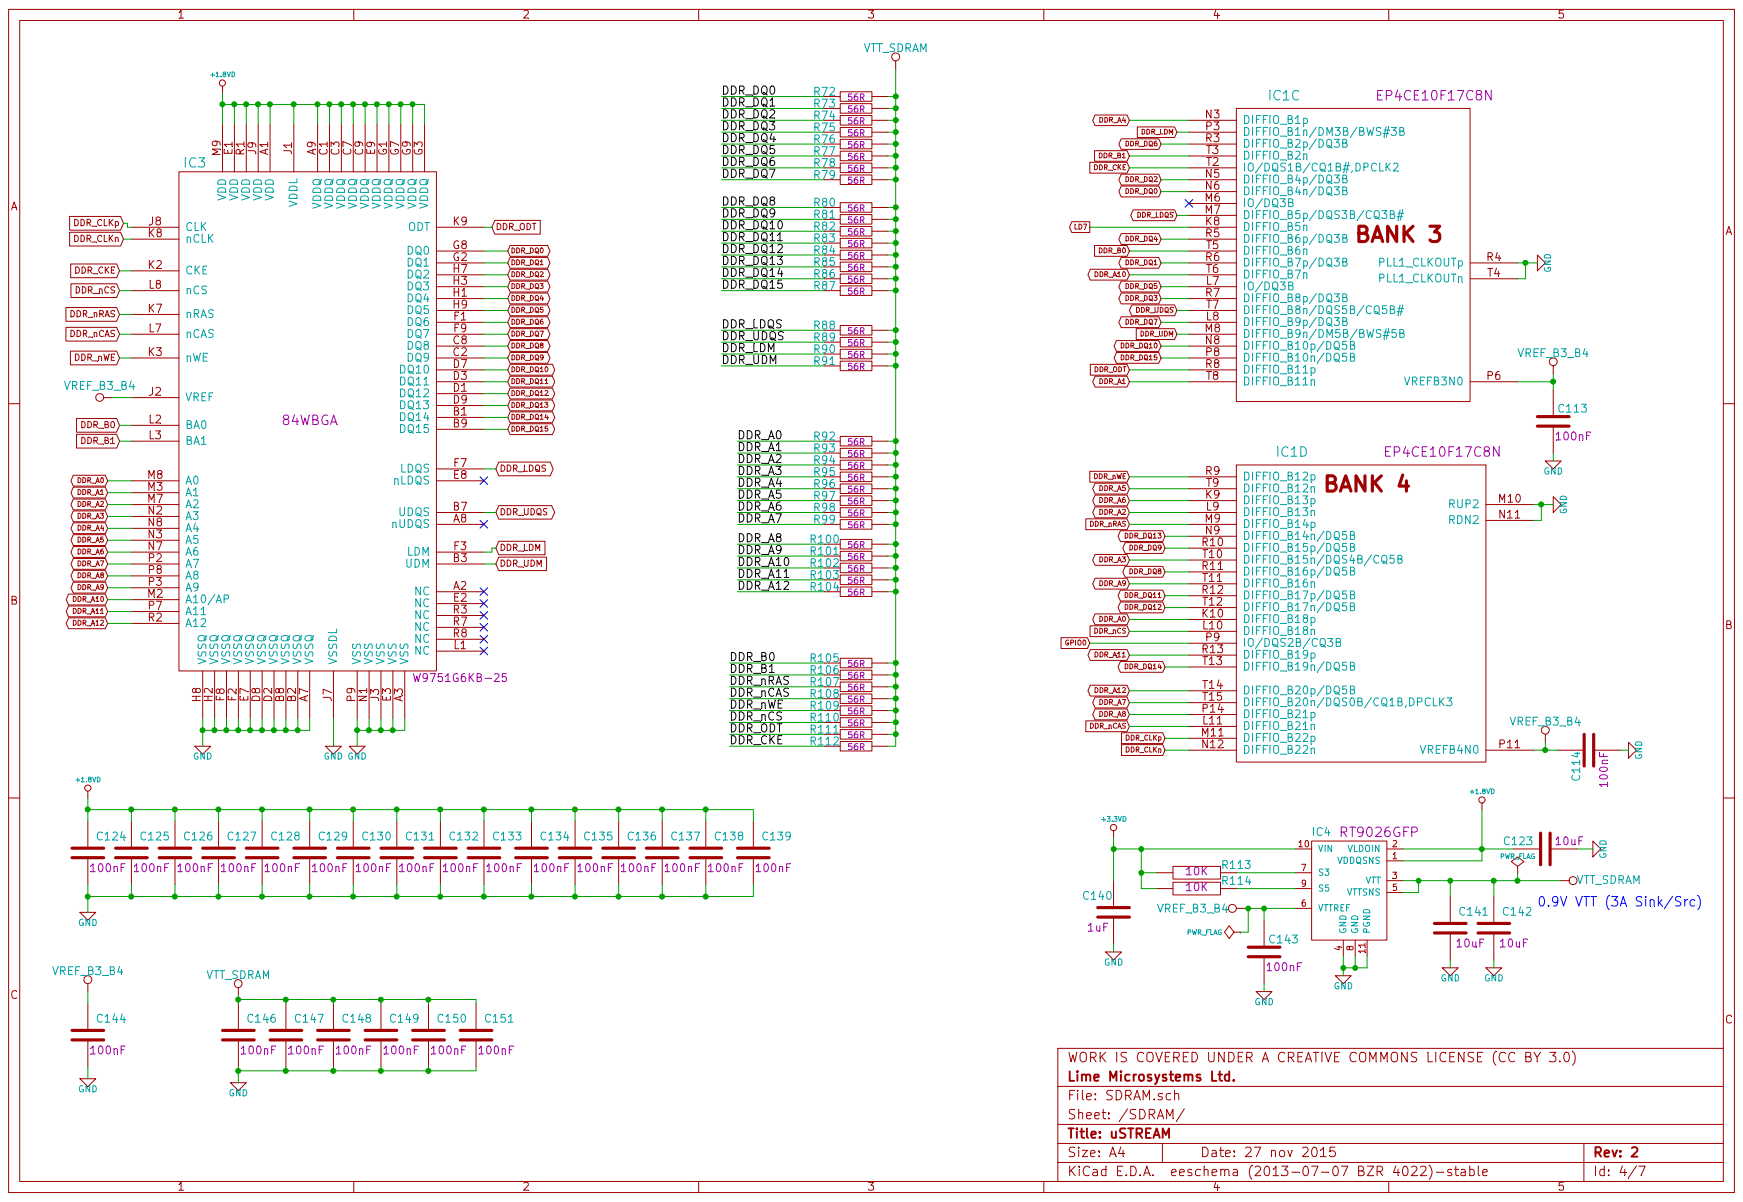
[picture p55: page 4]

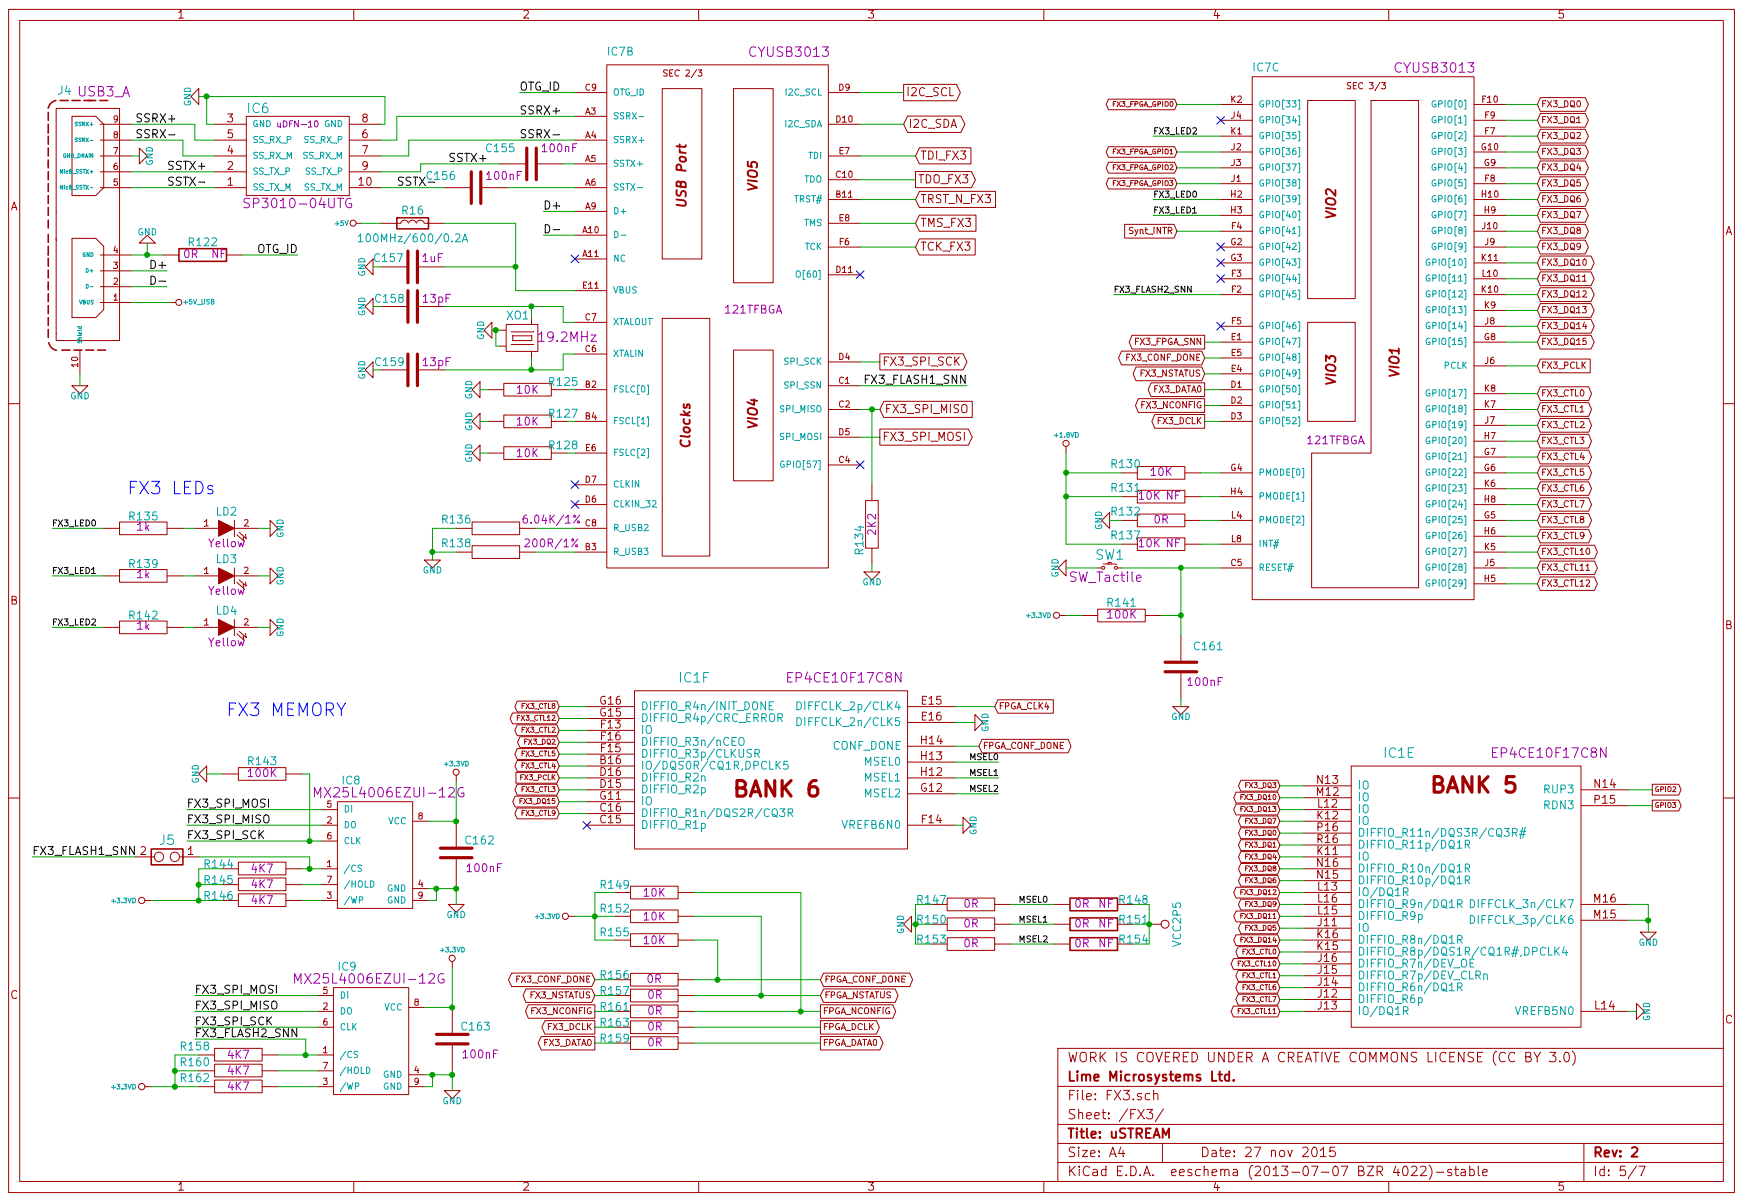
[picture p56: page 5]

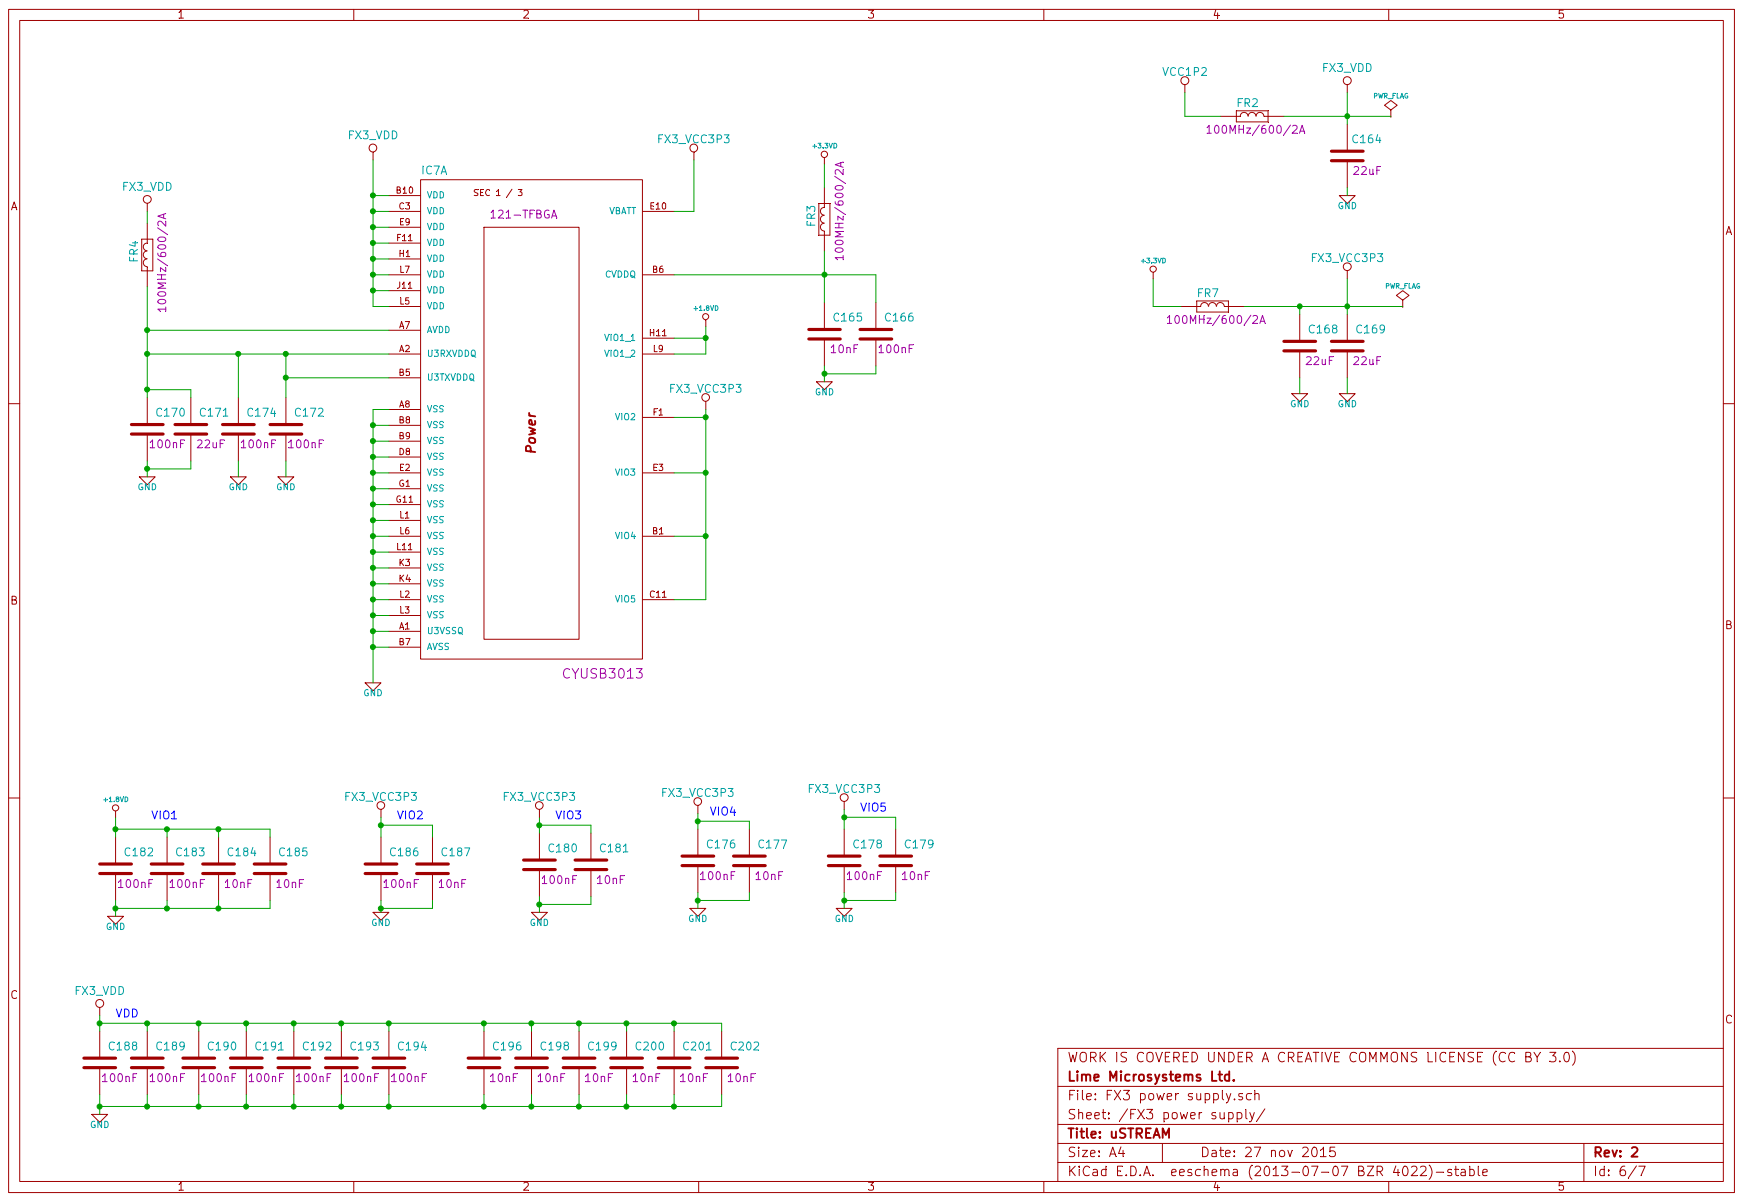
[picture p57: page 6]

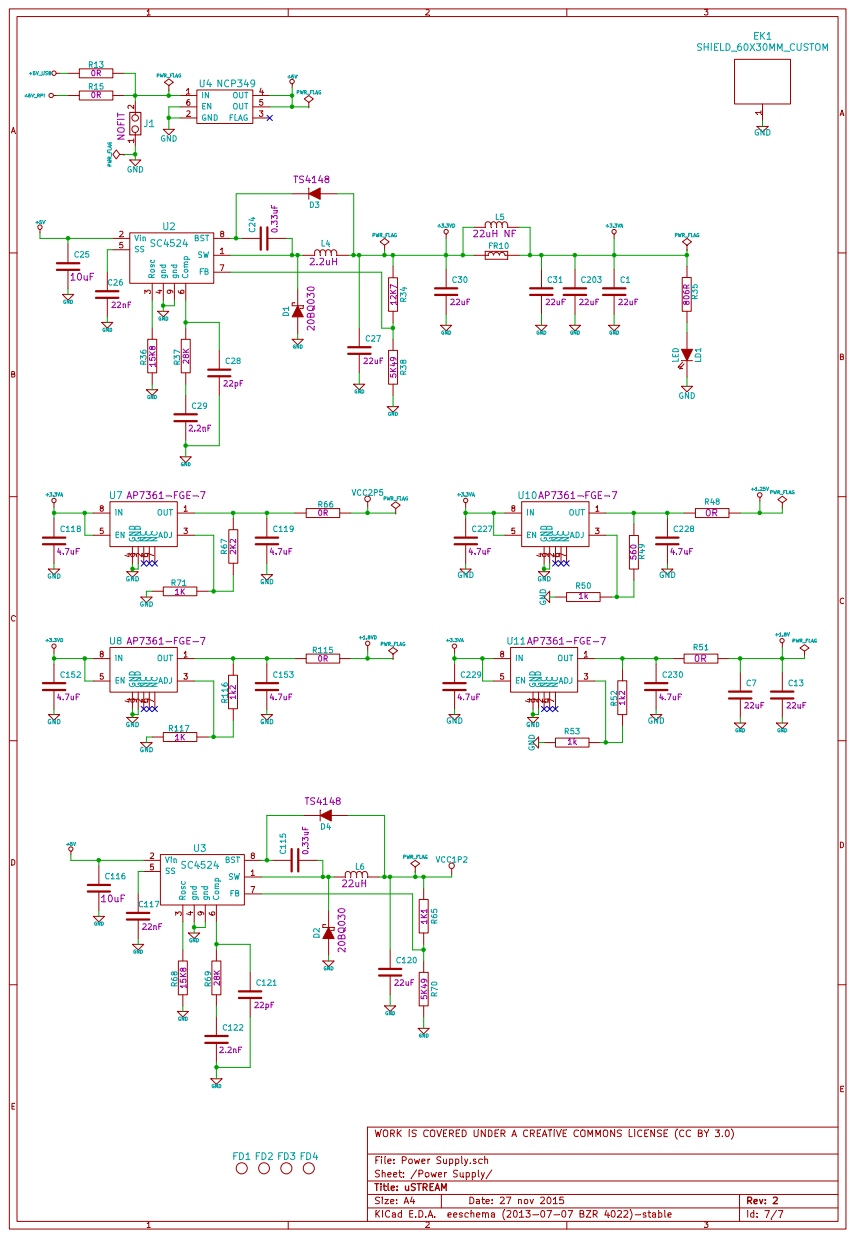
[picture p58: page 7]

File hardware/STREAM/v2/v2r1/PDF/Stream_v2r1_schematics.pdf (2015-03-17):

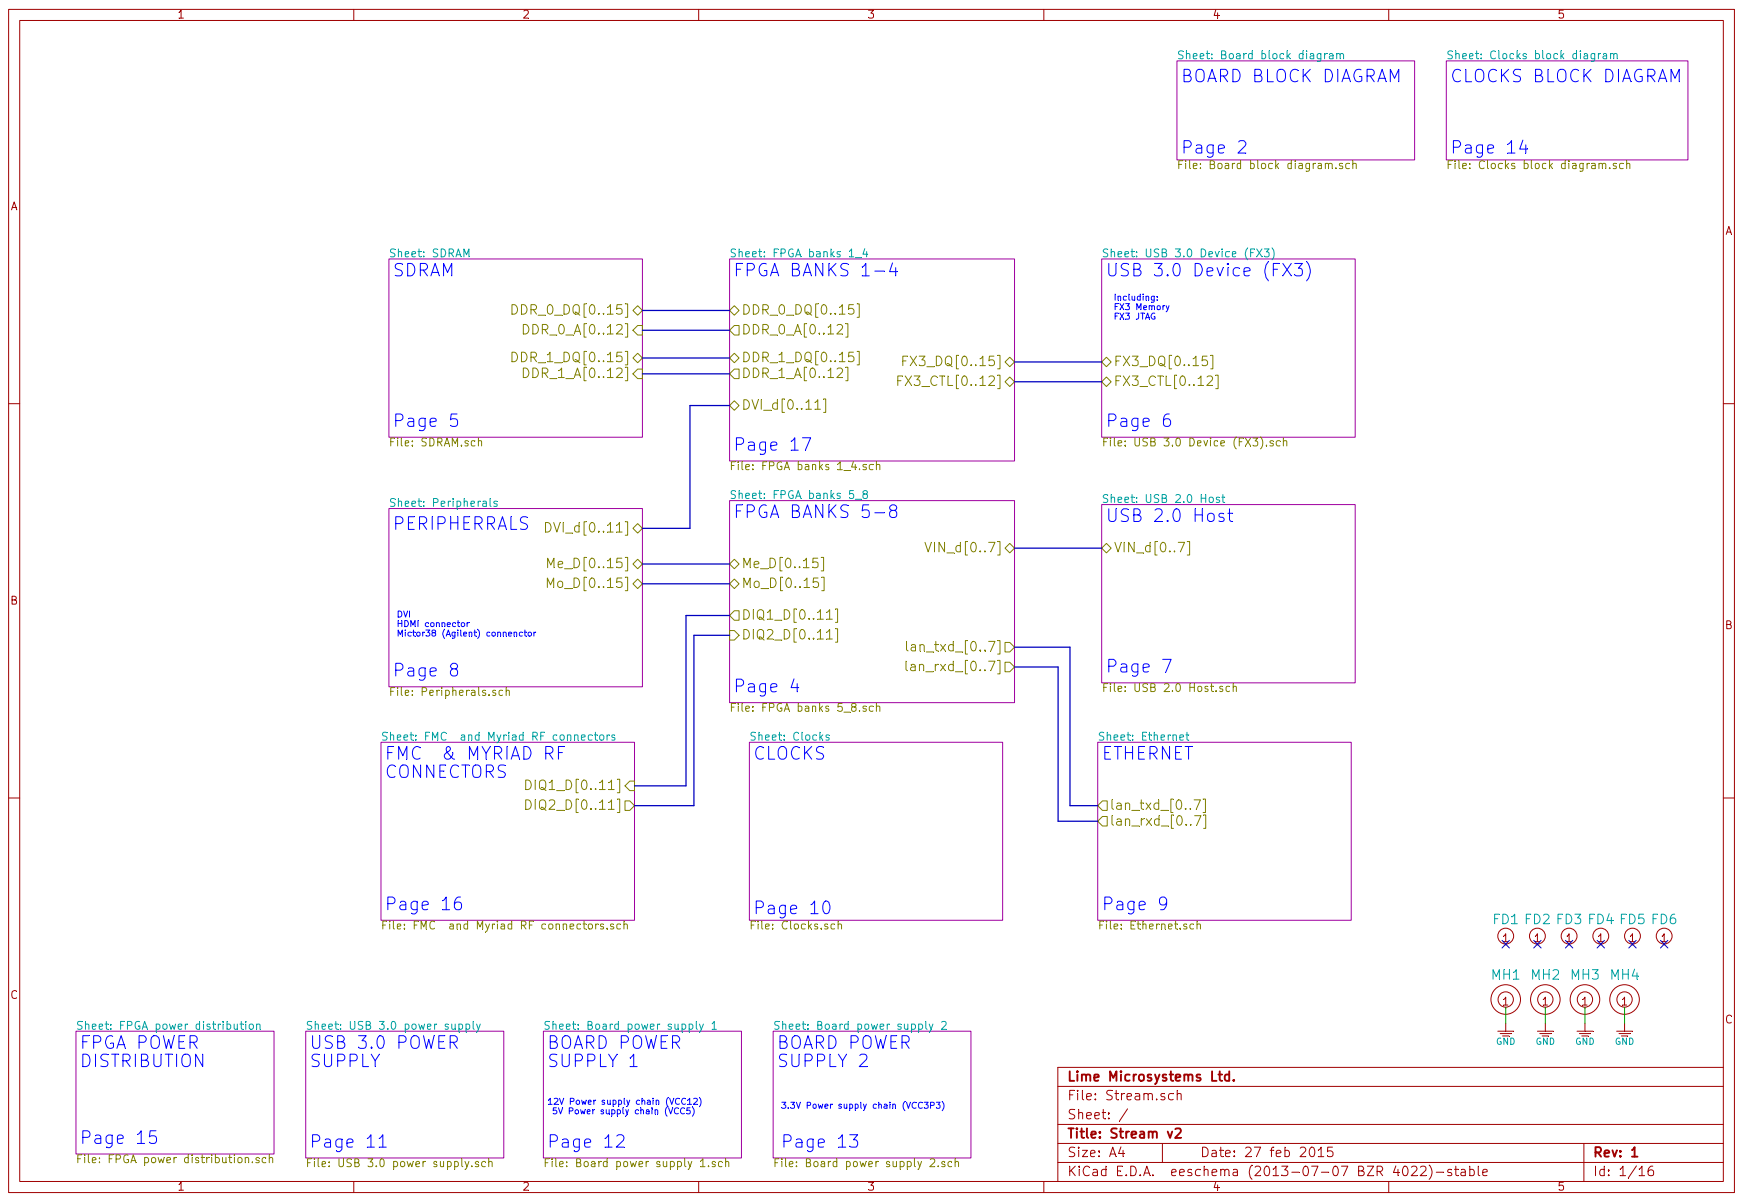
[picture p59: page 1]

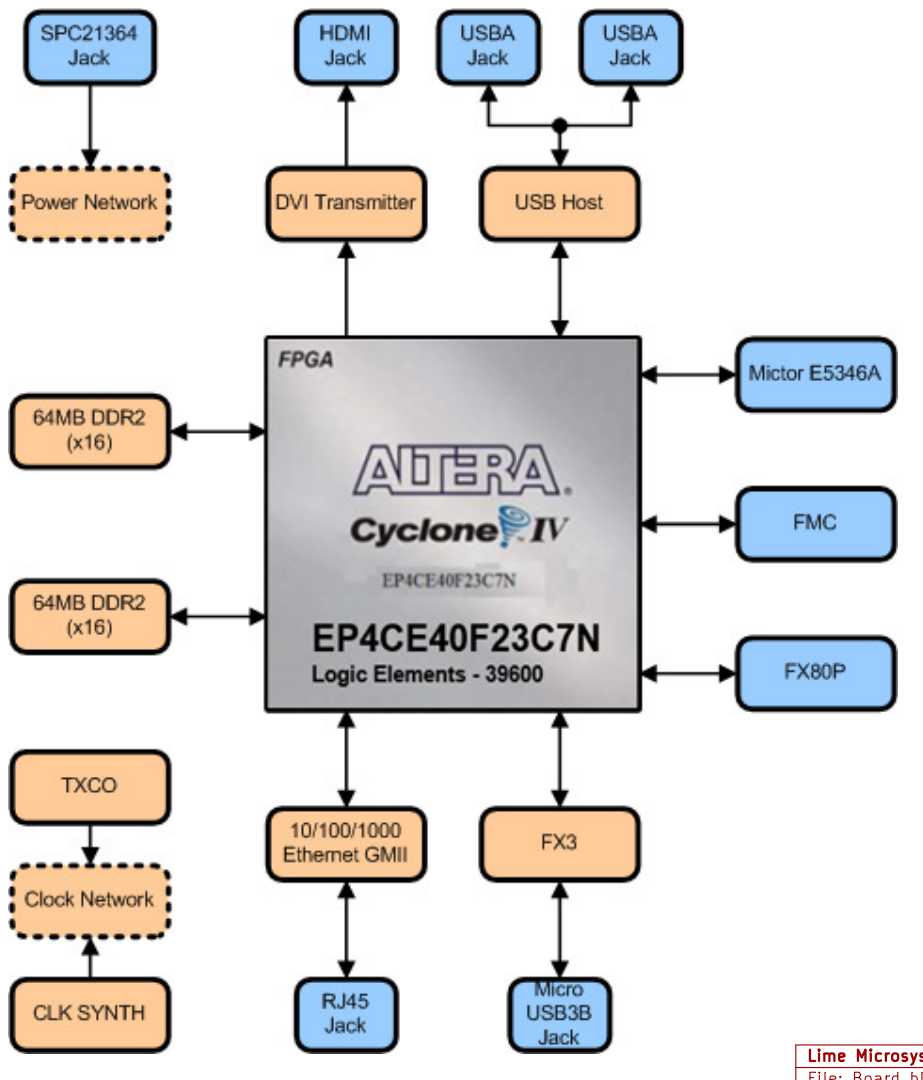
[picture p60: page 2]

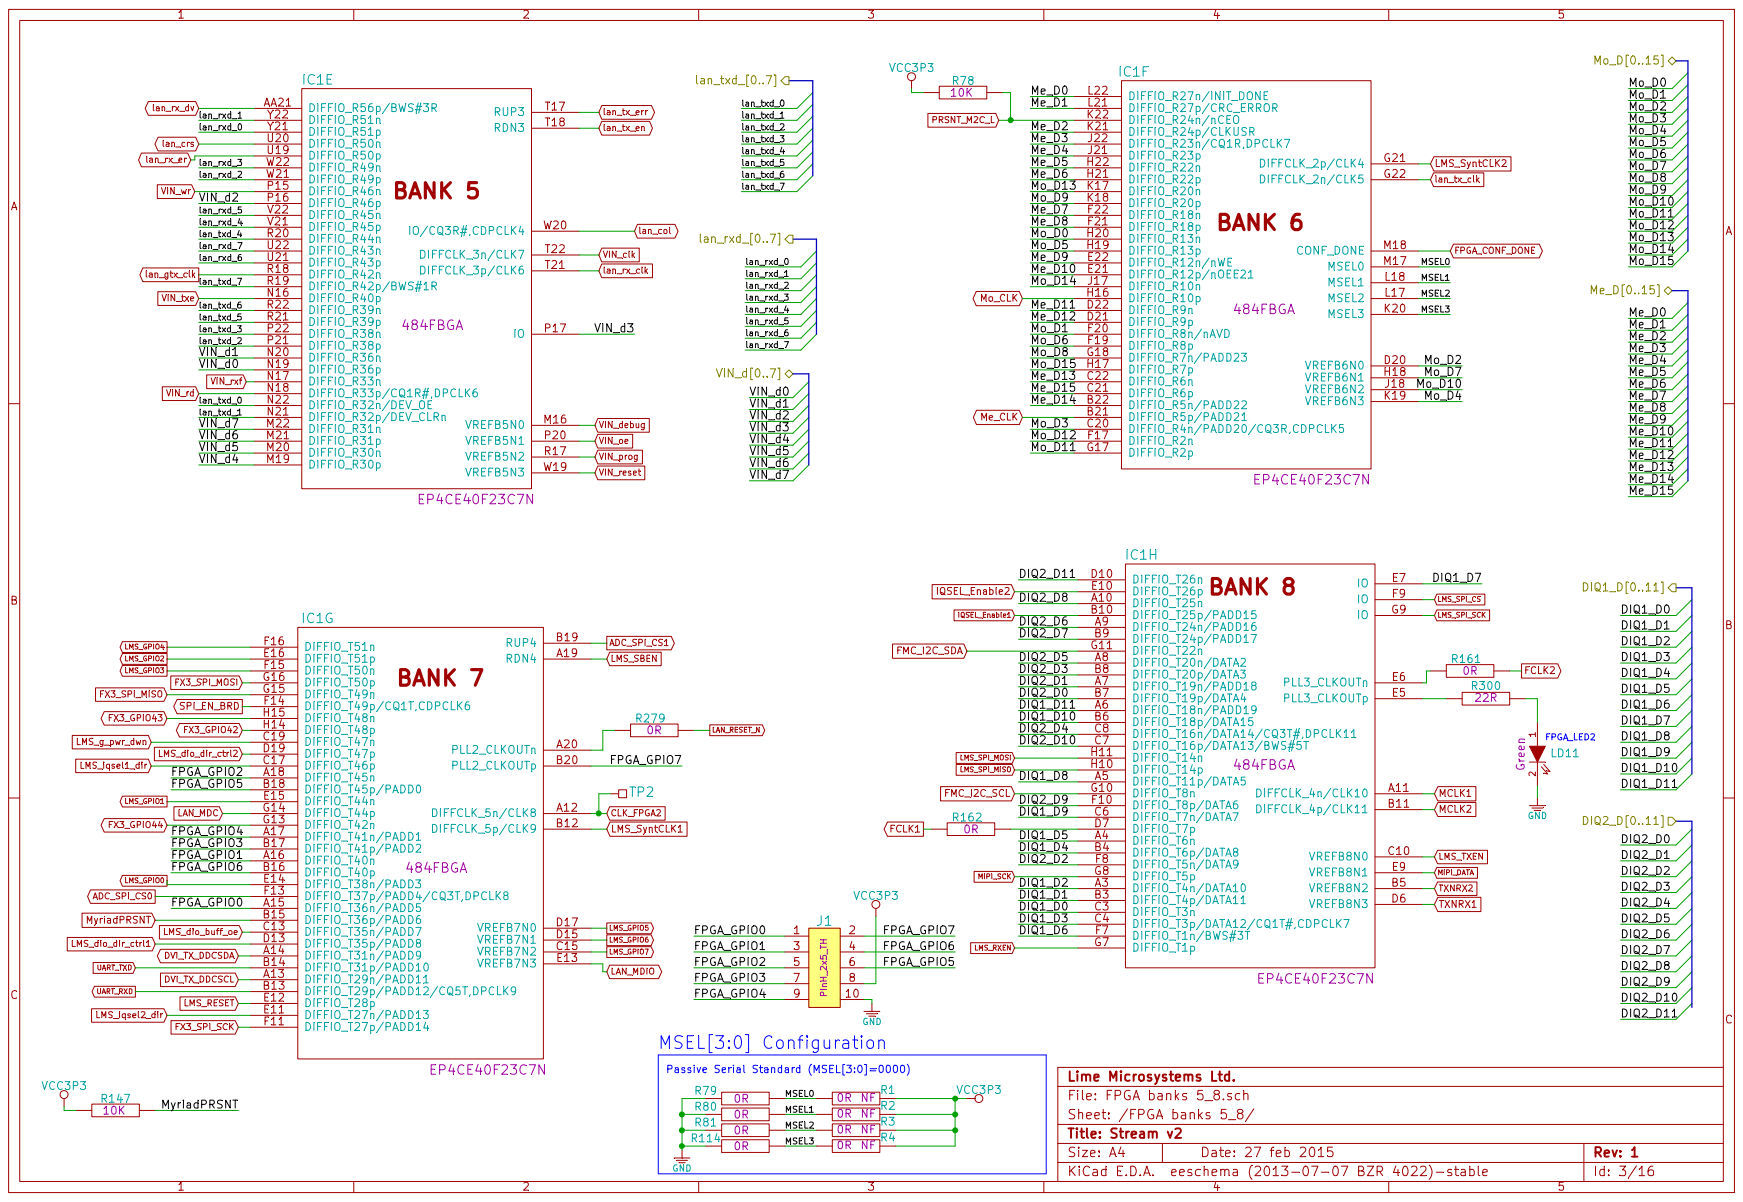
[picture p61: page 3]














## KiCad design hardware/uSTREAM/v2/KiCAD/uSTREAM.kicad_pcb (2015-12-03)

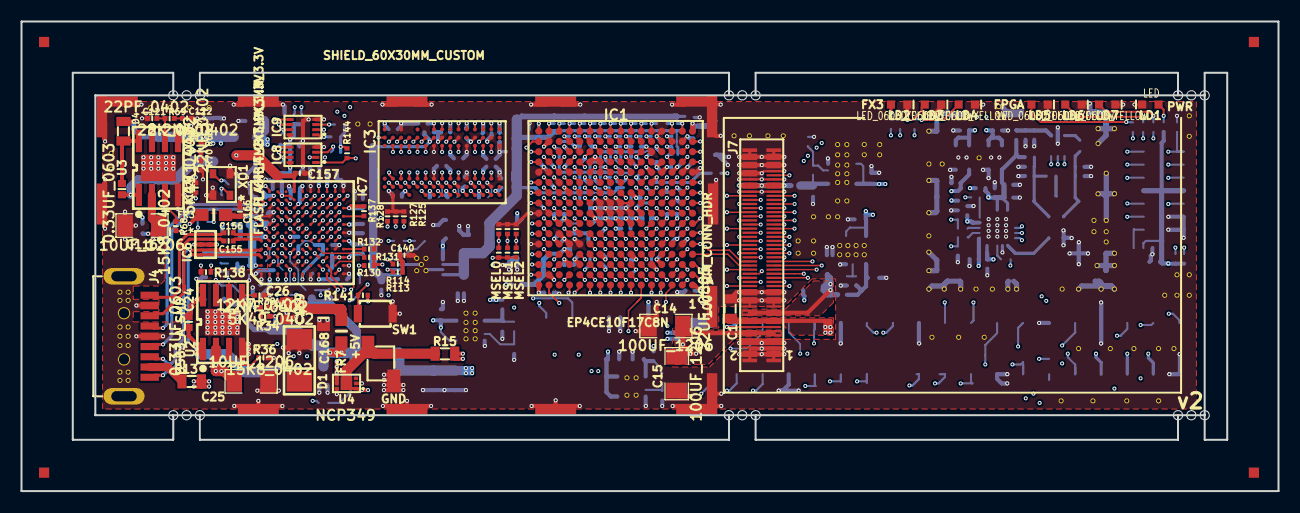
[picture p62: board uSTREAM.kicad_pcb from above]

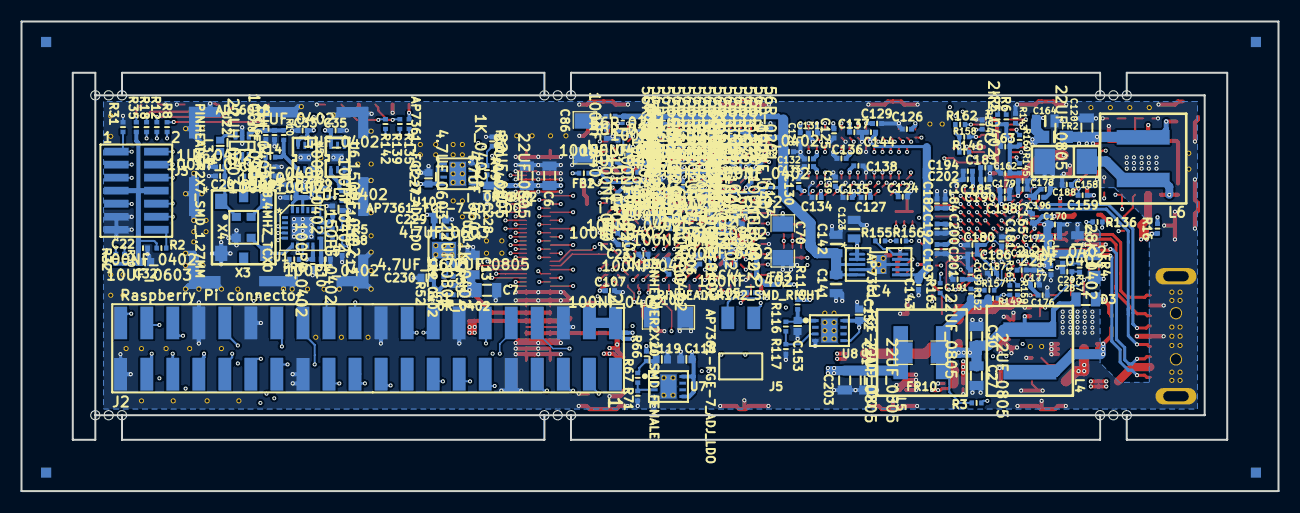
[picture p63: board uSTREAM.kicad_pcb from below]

Board: 12 copper layers, 122.6 x 45.8 mm, 491 parts (270 on the bottom side), 284 nets.

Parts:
BreakHole: VAL**; BreakHole
BreakHole#2, BreakHole#3, BreakHole#4, BreakHole#5, BreakHole#6, BreakHole#7, BreakHole#8, BreakHole#9, BreakHole#10, BreakHole#11, BreakHole#12, BreakHole#13, BreakHole#14, BreakHole#15, BreakHole#16, BreakHole#17, BreakHole#18: VAL**; BreakHole
C1, C3, C6, C7, C13, C27, C30, C31, C120, C203: 22UF_0805; SMD0805
C4, C5, C8, C9, C10: 100PF_0402; SMD0402
C11, C12: 150PF_0402; SMD0402
C14, C15: 100UF_1206; SMD1206
C16, C17, C20, C33, C34, C35, C36, C73, C76, C79, C82, C85, C96, C99: 1UF_0402; SMD0402
C18, C19, C21, C22, C23, C44, C64, C72, C75, C78, C81, C84, C87, C88, C89, C90, C91, C92, C95, C98, C101, C102, C103, C104, C105, C106, C107, C108, C109, C110, C112: 100NF_0402; SMD0402
C24, C115: 0.33UF_0603; SMD0603
C25, C116: 10UF_1206; SMD1206
C26, C117: 22NF_0402; SMD0402
C28, C121: 22PF_0402; SMD0402
C29, C122: 2.2NF_0402; SMD0402
C32: 10UF_0603; SMD0603
C70, C86, C100: 100UF_1206; SM1206
C71, C74, C77, C80, C83, C94, C97: 10NF_0402; SM0402
C113, C114, C124, C125, C126, C127, C128, C129, C130, C131, C132, C133, C134, C135, C136, C137, C138, C139, C143, C144, C146, C147, C148, C149, C150, C151, C155, C156, C161, C162, C163, C166, C170, C172, C174, C176, C178, C180, C182, C183, C186, C188, C189, C190, C191, C192, C193, C194: 100NF_0402; C_SM0402
C118, C119, C152, C153: 4.7UF_0603; C_SM0603
C123, C141, C142: 10UF_0805; C_SM0805
C140, C157: 1UF_0402; C_SM0402
C158, C159: 13PF_0402; C_SM0402
C164, C168, C169, C171: 22UF_0805; C_SM0805
C165, C177, C179, C181, C184, C185, C187, C196, C198, C199, C200, C201, C202: 10NF_0402; C_SM0402
C227, C228, C229, C230: 4.7UF_0603; SMD0603
D1, D2: 20BQ030; SMB
D3, D4: TS4148; SM0805
EK1: SHIELD_60X30MM_CUSTOM; shield_60x30mm_custom
EK2: SHIELD_16.5X16.5MM; shield_16.5x16.5mm
FB1, FB2, FB3, FB4: FB_600R_0402; R_SM0402
FD1, FD2, FD3, FD4: FIDUCIAL; Pad
FR2, FR3, FR4, FR7: FR_600R_0805_2A; R_SM0805
FR5, FR6, FR8, FR9: FR_220R_0402; R_SM0402
FR10: FR_220R_1206_4A; SM1206
GND_VIA: VAL**; GND_VIA
GND_VIA#2, GND_VIA#3, GND_VIA#4, GND_VIA#5, GND_VIA#6, GND_VIA#7, GND_VIA#8, GND_VIA#9, GND_VIA#10, GND_VIA#11, GND_VIA#12, GND_VIA#13, GND_VIA#14, GND_VIA#15, GND_VIA#16, GND_VIA#17, GND_VIA#18, GND_VIA#19, GND_VIA#20, GND_VIA#21, GND_VIA#22, GND_VIA#23, GND_VIA#24, GND_VIA#25, GND_VIA#26, GND_VIA#27, GND_VIA#28, GND_VIA#29, GND_VIA#30, GND_VIA#31, GND_VIA#32, GND_VIA#33, GND_VIA#34, GND_VIA#35, GND_VIA#36, GND_VIA#37, GND_VIA#38, GND_VIA#39, GND_VIA#40, GND_VIA#41, GND_VIA#42, GND_VIA#43, GND_VIA#44, GND_VIA#45, GND_VIA#46, GND_VIA#47, GND_VIA#48, GND_VIA#49, GND_VIA#50, GND_VIA#51, GND_VIA#52, GND_VIA#53, GND_VIA#54, GND_VIA#55, GND_VIA#56, GND_VIA#57, GND_VIA#58, GND_VIA#59, GND_VIA#60, GND_VIA#61, GND_VIA#62, GND_VIA#63, GND_VIA#64, GND_VIA#65, GND_VIA#66, GND_VIA#67, GND_VIA#68, GND_VIA#69, GND_VIA#70, GND_VIA#71, GND_VIA#72, GND_VIA#73, GND_VIA#74, GND_VIA#75, GND_VIA#76, GND_VIA#77, GND_VIA#78, GND_VIA#79, GND_VIA#80, GND_VIA#81, GND_VIA#82, GND_VIA#83, GND_VIA#84, GND_VIA#85, GND_VIA#86, GND_VIA#87, GND_VIA#88, GND_VIA#89, GND_VIA#90, GND_VIA#91, GND_VIA#92, GND_VIA#93, GND_VIA#94, GND_VIA#95, GND_VIA#96, GND_VIA#97, GND_VIA#98, GND_VIA#99, GND_VIA#100, GND_VIA#101, GND_VIA#102, GND_VIA#103, GND_VIA#104, GND_VIA#105, GND_VIA#106, GND_VIA#107, GND_VIA#108, GND_VIA#109, GND_VIA#110, GND_VIA#111, GND_VIA#112, GND_VIA#113, GND_VIA#114, GND_VIA#115, GND_VIA#116, GND_VIA#117, GND_VIA#118, GND_VIA#119, GND_VIA#120, GND_VIA#121, GND_VIA#122, GND_VIA#123, GND_VIA#124, GND_VIA#125, GND_VIA#126, GND_VIA#127: VAL**; GND_VIA
IC1: EP4CE10F17C8N; 256FBGA
IC3: W9751G6KB-25; 84WBGA
IC4: RT9026GFP; MSOP10
IC6: SP3010-04UTG; uDFN-10
IC7: CYUSB3013; FBGA_121_Ball_10x10
IC8, IC9: FLASH_4MBIT_2X3MM_3.3V; 8-USON
J1: JUMPER2_V; PINHEADER_1x2_SMD
J2: PINHEADER2X20_SMD_FEMALE; PinHeader2x20SMDfemale
J3: PINHEADER2X7_SMD_1.27MM; PinHeader2x7_SMD_1.27mm
J4: USB3_A_SMD
J5: PINHEADER1X2_SMD_RIGHT; PINHEADER_1x2_SMD_right
J7: 100-PIN_CONN_HDR
L3: 22UH_0603; SMD0603
L4: 2.2UH_XAL60XX_SERIES; XAL60xx series
L5: 22UH_XAL60XX_SERIES_NF; XAL60xx series
L6: 22UH_XAL60XX_SERIES; XAL60xx series
LD1: LED; LD0603
LD2, LD3, LD4, LD5, LD6, LD7: LED_0603_YELLOW; LD0603
R2, R141, R143: 100K_0402; R_SM0402
R3, R5, R6, R67: 2K2_0402; R_SM0402
R8, R12, R31, R71, R117, R135, R139, R142: 1K_0402; R_SM0402
R9, R18, R21, R66, R115, R132, R147, R150, R153, R156, R157, R159, R161, R163: 0R_0402; R_SM0402
R10, R14, R16: 100MHz/600/0.2A; R_SM0402
R13, R15: 0R_0805; SM0805
R20, R122, R148, R151, R154: 0R_0402_NF; R_SM0402
R22: 10K_0402; SMD0402
R30, R32, R113, R114, R125, R127, R128, R130, R149, R152, R155: 10K_0402; R_SM0402
R34: 12K7_0402; SMD0402
R35: 806R_0402; R_SM0402
R36, R68: 15K8_0402; SMD0402
R37, R69: 28K_0402; SMD0402
R38, R70: 5K49_0402; SMD0402
R48, R51: 0R_0402; SM0402
R49: 560_0402; SM0402
R50, R53: 1K_0402; SMD0402
R52: 1K2_0402; SM0402
R65: 1K1_0402; SMD0402
R72, R73, R74, R75, R76, R77, R78, R79, R80, R81, R82, R83, R84, R85, R86, R87, R88, R89, R90, R91, R92, R93, R94, R95, R96, R97, R98, R99, R100, R101, R102, R103, R104, R105, R106, R107, R108, R109, R110, R111, R112: 56R_0201; SMD0201
R116: 1K2_0402; R_SM0402
R131, R137: 10K_0402_NF; R_SM0402
R134: 2K2_0402; SMD0402
R136: 6.04K/1%_0402; R_SM0402
R138: 200R/1%_0402; R_SM0402
R144, R145, R146, R158, R160, R162: 4K7_0402; R_SM0402
SW1: SW_TACTILE; SW_B3U-1000P
U1: SI5351C; QFN20
U2, U3: SC4524; SOIC-8
U4: NCP349; 6-DFN
U5: LP5900SD-3.3; SC70
U6: LP5900SD-1.8; SC70
U7, U8, U10, U11: AP7361-FGE-7_ADJ_LDO; 8-UDFN3030
U22: AD5601B; SC-70-6
X3: RACON_TXCO_PLUTO+; SMD_TXCO_Pluto+
X4: 38.4MHZ_TCXO; TCXO_2x2.5mm
XO1: CRYSTAL_19.2MHZ; 4-SMD_TCXO

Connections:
+1.8V: C7.1, C13.1, J7.21, J7.22, J7.23, J7.24, R51.2
+1.8VD: C86.1, C87.1, C88.1, C89.1, C90.1, C91.1, C92.1, C101.1, C102.1, C103.1, C104.1, C123.1, C124.1, C125.1, C126.1, C127.1, C128.1, C129.1, C130.1, C131.1, C132.1, C133.1, C134.1, C135.1, C136.1, C137.1, C138.1, C139.1, C182.1, C183.1, C184.1, C185.1, IC1.E14, IC1.G14, IC1.K14, IC1.M14, IC1.P4, IC1.P7, IC1.P10, IC1.P13, IC1.T1, IC1.T16, IC3.A1, IC3.A9, IC3.C1, IC3.C3, IC3.C7, IC3.C9, IC3.E1, IC3.E9, IC3.G1, IC3.G3, IC3.G7, IC3.G9, IC3.J1, IC3.J9, IC3.M9, IC3.R1, IC4.1, IC4.2, IC7.H11, IC7.L9, R115.2, R130.2, R131.2, R137.2
+1.8V_CLK: C10.1, C36.1, R21.2, U1.10, U6.1
+1.25V: C3.1, C6.1, J7.83, J7.84, J7.85, J7.86, R48.2
+3.3VD: C23.1, C27.1, C30.1, C44.1, C64.1, C100.1, C105.1, C106.1, C107.1, C108.1, C109.1, C110.1, C112.1, C140.1, C152.1, C162.1, C163.1, D3.1, FR3.2, FR7.1, FR10.1, IC1.A1, IC1.A16, IC1.C4, IC1.C7, IC1.C10, IC1.C13, IC1.E3, IC1.G3, IC1.K3, IC1.M3, IC4.10, IC8.8, IC9.8, L4.1, L5.2, R3.1, R5.1, R6.1, R22.1, R34.1, R113.1, R114.1, R141.2, R144.1, R145.1, R146.1, R149.1, R152.1, R155.1, R158.1, R160.1, R162.1, U8.5, U8.8
+3.3V_CLK: C4.1, C8.1, C9.1, C34.1, R10.2, R14.2, R20.2, U1.14, U1.18, U1.20, U5.1
+3.3Va: C1.1, C22.1, C31.1, C32.1, C118.1, C203.1, C227.1, C229.1, FR10.2, J3.7, J3.8, J7.17, J7.18, J7.19, J7.20, L5.1, R2.2, R30.2, R32.2, R35.2, U7.5, U7.8, U10.5, U10.8, U11.5, U11.8
+5V: C14.1, C15.1, C25.1, C33.1, C35.1, C116.1, J7.11, J7.12, J7.13, J7.14, R16.1, U2.2, U3.2, U4.4, U4.5, U5.4, U5.6, U6.4, U6.6
+5V_RPi: J2.2, J2.4, R15.2
+5V_USB: J4.1, R13.1
/FX3/D+: IC7.A9, J4.3
/FX3/D-: IC7.A10, J4.2
/FX3/FX3_FLASH1_SNN: IC7.C1, J5.2
/FX3/FX3_FLASH2_SNN: IC7.F2, IC9.1, R158.2
/FX3/FX3_LED0: IC7.H2, R135.1
/FX3/FX3_LED1: IC7.H3, R139.1
/FX3/FX3_LED2: IC7.K1, R142.1
/FX3/MSEL0: IC1.H13, R147.1, R148.2
/FX3/MSEL1: IC1.H12, R150.1, R151.2
/FX3/MSEL2: IC1.G12, R153.1, R154.2
/FX3/OTG_ID: IC7.C9, R122.1
/FX3/SSRX+: IC6.5, IC6.6, IC7.A3, J4.9
/FX3/SSRX-: IC6.4, IC6.7, IC7.A4, J4.8
/FX3/SSTX+: C155.1, IC6.2, IC6.9, J4.6
/FX3/SSTX-: C156.1, IC6.1, IC6.10, J4.5
/LMS Digital Circuits/CLK_IO: C5.1, R20.1, R21.1, U1.11
/RaspberryPi_Connector/LD5: IC1.E11, R8.1
/RaspberryPi_Connector/LD6: IC1.E10, R12.1
/RaspberryPi_Connector/RPI_CE0n: IC1.A7, J2.24
/RaspberryPi_Connector/RPI_CE1n: IC1.C9, J2.26
/RaspberryPi_Connector/RPI_GCLK: IC1.B13, J2.7
/RaspberryPi_Connector/RPI_GEN0: IC1.D12, J2.11
/RaspberryPi_Connector/RPI_GEN1: IC1.A12, J2.12
/RaspberryPi_Connector/RPI_GEN2: IC1.B12, J2.13
/RaspberryPi_Connector/RPI_GEN3: IC1.A11, J2.15
/RaspberryPi_Connector/RPI_GEN4: IC1.B11, J2.16
/RaspberryPi_Connector/RPI_GEN5: IC1.A10, J2.18
/RaspberryPi_Connector/RPI_GEN6: IC1.B9, J2.22
/RaspberryPi_Connector/RPI_GPIO5: IC1.B8, J2.29
/RaspberryPi_Connector/RPI_GPIO6: IC1.D9, J2.31
/RaspberryPi_Connector/RPI_GPIO12: IC1.D8, J2.32
/RaspberryPi_Connector/RPI_GPIO13: IC1.F11, J2.33
/RaspberryPi_Connector/RPI_GPIO16: IC1.E8, J2.36
/RaspberryPi_Connector/RPI_GPIO19: IC1.E9, J2.35
/RaspberryPi_Connector/RPI_GPIO20: IC1.F8, J2.38
/RaspberryPi_Connector/RPI_GPIO21: IC1.F9, J2.40
/RaspberryPi_Connector/RPI_GPIO26: IC1.F10, J2.37
/RaspberryPi_Connector/RPI_ID_SC: IC1.C8, J2.28
/RaspberryPi_Connector/RPI_ID_SD: IC1.D11, J2.27
/RaspberryPi_Connector/RPI_MISO: IC1.A9, J2.21
/RaspberryPi_Connector/RPI_MOSI: IC1.B10, J2.19
/RaspberryPi_Connector/RPI_RXD0: IC1.C11, J2.10
/RaspberryPi_Connector/RPI_SCLK: IC1.A8, J2.23
/RaspberryPi_Connector/RPI_TXD0: IC1.C6, J2.8
/RaspberryPi_Connector/VCCA1: C97.1, C98.1, C99.1, FB2.2, IC1.L5
/RaspberryPi_Connector/VCCA2: C94.1, C95.1, C96.1, FB1.2, IC1.F12
/RaspberryPi_Connector/VCCD_PLL1: C83.1, C84.1, C85.1, FB4.2, IC1.N4
/RaspberryPi_Connector/VCCD_PLL2: C80.1, C81.1, C82.1, FB3.2, IC1.D13
DDR_A0: IC1.K10, IC3.M8, R92.2
DDR_A1: IC1.T8, IC3.M3, R93.2
DDR_A2: IC1.L9, IC3.M7, R94.2
DDR_A3: IC1.T10, IC3.N2, R95.2
DDR_A4: IC1.N3, IC3.N8, R96.2
DDR_A5: IC1.T9, IC3.N3, R97.2
DDR_A6: IC1.K9, IC3.N7, R98.2
DDR_A7: IC1.T15, IC3.P2, R99.2
DDR_A8: IC1.P14, IC3.P8, R100.2
DDR_A9: IC1.T11, IC3.P3, R101.2
DDR_A10: IC1.T6, IC3.M2, R102.2
DDR_A11: IC1.R13, IC3.P7, R103.2
DDR_A12: IC1.T14, IC3.R2, R104.2
DDR_B0: IC1.T5, IC3.L2, R105.2
DDR_B1: IC1.T3, IC3.L3, R106.2
DDR_CKE: IC1.T2, IC3.K2, R112.2
DDR_CLKn: IC1.N12, IC3.K8
DDR_CLKp: IC1.M11, IC3.J8
DDR_DQ0: IC1.N6, IC3.G8, R72.2
DDR_DQ1: IC1.R6, IC3.G2, R73.2
DDR_DQ2: IC1.N5, IC3.H7, R74.2
DDR_DQ3: IC1.R7, IC3.H3, R75.2
DDR_DQ4: IC1.R5, IC3.H1, R76.2
DDR_DQ5: IC1.L7, IC3.H9, R77.2
DDR_DQ6: IC1.R3, IC3.F1, R78.2
DDR_DQ7: IC1.L8, IC3.F9, R79.2
DDR_DQ8: IC1.R11, IC3.C8, R80.2
DDR_DQ9: IC1.R10, IC3.C2, R81.2
DDR_DQ10: IC1.N8, IC3.D7, R82.2
DDR_DQ11: IC1.R12, IC3.D3, R83.2
DDR_DQ12: IC1.T12, IC3.D1, R84.2
DDR_DQ13: IC1.N9, IC3.D9, R85.2
DDR_DQ14: IC1.T13, IC3.B1, R86.2
DDR_DQ15: IC1.P8, IC3.B9, R87.2
DDR_LDM: IC1.P3, IC3.F3, R90.2
DDR_LDQS: IC1.M7, IC3.F7, R88.2
DDR_ODT: IC1.R8, IC3.K9, R111.2
DDR_UDM: IC1.M8, IC3.B3, R91.2
DDR_UDQS: IC1.T7, IC3.B7, R89.2
DDR_nCAS: IC1.L11, IC3.L7, R108.2
DDR_nCS: IC1.L10, IC3.L8, R110.2
DDR_nRAS: IC1.M9, IC3.K7, R107.2
DDR_nWE: IC1.R9, IC3.K3, R109.2
DIG_RST: IC1.D6, J7.44
DIQ1_D0: IC1.L1, J7.74
DIQ1_D1: IC1.L2, J7.76
DIQ1_D2: IC1.P1, J7.79
DIQ1_D3: IC1.K1, J7.72
DIQ1_D4: IC1.K5, J7.70
DIQ1_D5: IC1.L6, J7.78
DIQ1_D6: IC1.P2, J7.77
DIQ1_D7: IC1.R1, J7.75
DIQ1_D8: IC1.K6, J7.68
DIQ1_D9: IC1.N2, J7.73
DIQ1_D10: IC1.L4, J7.80
DIQ1_D11: IC1.J1, J7.66
DIQ2_D0: IC1.D4, J7.52
DIQ2_D1: IC1.B6, J7.49
DIQ2_D2: IC1.D3, J7.50
DIQ2_D3: IC1.B1, J7.51
DIQ2_D4: IC1.F2, J7.56
DIQ2_D5: IC1.E5, J7.54
DIQ2_D6: IC1.F1, J7.58
DIQ2_D7: IC1.B3, J7.53
DIQ2_D8: IC1.G1, J7.60
DIQ2_D9: IC1.C1, J7.55
DIQ2_D10: IC1.J2, J7.64
DIQ2_D11: IC1.G2, J7.62
ENABLE_IQSEL1: IC1.J6, J7.67
ENABLE_IQSEL2: IC1.C3, J7.59
FCLK1: IC1.K2, J7.69
FCLK2: IC1.D2, J7.61
FPGA_CLK4: FR6.2, IC1.E15
FPGA_CONF_DONE: IC1.H14, R155.2, R156.1
FPGA_DAC_CS: IC1.B5, U22.1
FPGA_DATA0: IC1.H2, R159.1
FPGA_DCLK: IC1.H1, R163.1
FPGA_LMS_CS: IC1.A2, J7.38
FPGA_NCONFIG: IC1.H5, R149.2, R161.1
FPGA_NSTATUS: IC1.F4, R152.2, R157.1
FPGA_SPI_MISO: IC1.E6, J7.37
FPGA_SPI_MOSI: IC1.A5, J7.36, U22.3
FPGA_SPI_SCK: IC1.E7, J7.40, U22.2
FX3_CONF_DONE: IC7.E5, R156.2
FX3_CTL0: IC1.K15, IC7.K8
FX3_CTL1: IC1.J15, IC7.K7
FX3_CTL2: IC1.F13, IC7.J7
FX3_CTL3: IC1.D15, IC7.H7
FX3_CTL4: IC1.B16, IC7.G7
FX3_CTL5: IC1.F15, IC7.G6
FX3_CTL6: IC1.J14, IC7.K6
FX3_CTL7: IC1.J12, IC7.H8
FX3_CTL8: IC1.G16, IC7.G5
FX3_CTL9: IC1.C16, IC7.H6
FX3_CTL10: IC1.J16, IC7.K5
FX3_CTL11: IC1.J13, IC7.J5
FX3_CTL12: IC1.G15, IC7.H5
FX3_DATA0: IC7.D1, R159.2
FX3_DCLK: IC7.D3, R163.2
FX3_DQ0: IC1.P16, IC7.F10
FX3_DQ1: IC1.R16, IC7.F9
FX3_DQ2: IC1.F16, IC7.F7
FX3_DQ3: IC1.N13, IC7.G10
FX3_DQ4: IC1.K11, IC7.G9
FX3_DQ5: IC1.J11, IC7.F8
FX3_DQ6: IC1.N15, IC7.H10
FX3_DQ7: IC1.K12, IC7.H9
FX3_DQ8: IC1.N16, IC7.J10
FX3_DQ9: IC1.L16, IC7.J9
FX3_DQ10: IC1.M12, IC7.K11
FX3_DQ11: IC1.L15, IC7.L10
FX3_DQ12: IC1.L13, IC7.K10
FX3_DQ13: IC1.L12, IC7.K9
FX3_DQ14: IC1.K16, IC7.J8
FX3_DQ15: IC1.G11, IC7.G8
FX3_FPGA_GPIO0: IC1.B4, IC7.K2
FX3_FPGA_GPIO1: IC1.A4, IC7.J2
FX3_FPGA_GPIO2: IC1.D5, IC7.J3
FX3_FPGA_GPIO3: IC1.A3, IC7.J1
FX3_FPGA_SNN: IC1.A6, IC7.E1
FX3_NCONFIG: IC7.D2, R161.2
FX3_NSTATUS: IC7.E4, R157.2
FX3_PCLK: IC1.D16, IC7.J6
FX3_SPI_MISO: IC1.F6, IC7.C2, IC8.2, IC9.2, R134.1
FX3_SPI_MOSI: IC1.F7, IC7.D5, IC8.5, IC9.5
FX3_SPI_SCK: IC1.B7, IC7.D4, IC8.6, IC9.6, R143.1
FX3_VCC3P3: C168.1, C169.1, C176.1, C177.1, C178.1, C179.1, C180.1, C181.1, C186.1, C187.1, FR7.2, IC7.B1, IC7.C11, IC7.E3, IC7.E10, IC7.F1
FX3_VDD: C164.1, C188.1, C189.1, C190.1, C191.1, C192.1, C193.1, C194.1, C196.1, C198.1, C199.1, C200.1, C201.1, C202.1, FR2.2, FR4.2, IC7.B10, IC7.C3, IC7.E9, IC7.F11, IC7.H1, IC7.J11, IC7.L5, IC7.L7
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

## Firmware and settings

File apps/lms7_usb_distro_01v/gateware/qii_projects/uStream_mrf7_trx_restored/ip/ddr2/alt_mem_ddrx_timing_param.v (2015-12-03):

//altera message_off 10230

`include "alt_mem_ddrx_define.iv"

`timescale 1 ps / 1 ps
module alt_mem_ddrx_timing_param #
    ( parameter
        CFG_DWIDTH_RATIO                                    =   2,
        CFG_CTL_ARBITER_TYPE                                =   "ROWCOL",
        
        // cfg: general
        CFG_PORT_WIDTH_TYPE                                 =   3,
        CFG_PORT_WIDTH_BURST_LENGTH                         =   5,
        
        // cfg: timing parameters
        CFG_PORT_WIDTH_CAS_WR_LAT                           =   4,          // max will be 8 in DDR3
        CFG_PORT_WIDTH_ADD_LAT                              =   3,          // max will be 10 in DDR3
        CFG_PORT_WIDTH_TCL                                  =   4,          // max will be 11 in DDR3
        CFG_PORT_WIDTH_TRRD                                 =   4,          // 2 - 8        enough?
        CFG_PORT_WIDTH_TFAW                                 =   6,          // 6 - 32       enough?
        CFG_PORT_WIDTH_TRFC                                 =   8,          // 12-140       enough?
        CFG_PORT_WIDTH_TREFI                                =   13,         // 780 - 6240   enough?
        CFG_PORT_WIDTH_TRCD                                 =   4,          // 2 - 11       enough?
        CFG_PORT_WIDTH_TRP                                  =   4,          // 2 - 11       enough?
        CFG_PORT_WIDTH_TWR                                  =   4,          // 2 - 12       enough?
        CFG_PORT_WIDTH_TWTR                                 =   4,          // 1 - 10       enough?
        CFG_PORT_WIDTH_TRTP                                 =   4,          // 2 - 8        enough?
        CFG_PORT_WIDTH_TRAS                                 =   5,          // 4 - 29       enough?
        CFG_PORT_WIDTH_TRC                                  =   6,          // 8 - 40       enough?
        CFG_PORT_WIDTH_TCCD                                 =   3,          // max will be 4 in 4n prefetch architecture?
        CFG_PORT_WIDTH_TMRD                                 =   3,          // 4 - ?        enough?
        CFG_PORT_WIDTH_SELF_RFSH_EXIT_CYCLES                =   10,         // max will be 512 in DDR3
        CFG_PORT_WIDTH_PDN_EXIT_CYCLES                      =   4,          // 3 - ?        enough?
        CFG_PORT_WIDTH_AUTO_PD_CYCLES                       =   16,         // enough?
        CFG_PORT_WIDTH_POWER_SAVING_EXIT_CYCLES             =   4,          // enough?
        CFG_PORT_WIDTH_MEM_CLK_ENTRY_CYCLES                 =   4,          // enough?
        
        // cfg: extra timing parameters
        CFG_PORT_WIDTH_EXTRA_CTL_CLK_ACT_TO_RDWR            =   4,
        CFG_PORT_WIDTH_EXTRA_CTL_CLK_ACT_TO_PCH             =   4,
        CFG_PORT_WIDTH_EXTRA_CTL_CLK_ACT_TO_ACT             =   4,
        CFG_PORT_WIDTH_EXTRA_CTL_CLK_RD_TO_RD               =   4,
        CFG_PORT_WIDTH_EXTRA_CTL_CLK_RD_TO_RD_DIFF_CHIP     =   4,
        CFG_PORT_WIDTH_EXTRA_CTL_CLK_RD_TO_WR               =   4,
        CFG_PORT_WIDTH_EXTRA_CTL_CLK_RD_TO_WR_BC            =   4,
        CFG_PORT_WIDTH_EXTRA_CTL_CLK_RD_TO_WR_DIFF_CHIP     =   4,
        CFG_PORT_WIDTH_EXTRA_CTL_CLK_RD_TO_PCH              =   4,
        CFG_PORT_WIDTH_EXTRA_CTL_CLK_RD_AP_TO_VALID         =   4,
        CFG_PORT_WIDTH_EXTRA_CTL_CLK_WR_TO_WR               =   4,
        CFG_PORT_WIDTH_EXTRA_CTL_CLK_WR_TO_WR_DIFF_CHIP     =   4,
        CFG_PORT_WIDTH_EXTRA_CTL_CLK_WR_TO_RD               =   4,
        CFG_PORT_WIDTH_EXTRA_CTL_CLK_WR_TO_RD_BC            =   4,
        CFG_PORT_WIDTH_EXTRA_CTL_CLK_WR_TO_RD_DIFF_CHIP     =   4,
        CFG_PORT_WIDTH_EXTRA_CTL_CLK_WR_TO_PCH              =   4,
        CFG_PORT_WIDTH_EXTRA_CTL_CLK_WR_AP_TO_VALID         =   4,
        CFG_PORT_WIDTH_EXTRA_CTL_CLK_PCH_TO_VALID           =   4,
        CFG_PORT_WIDTH_EXTRA_CTL_CLK_PCH_ALL_TO_VALID       =   4,
        CFG_PORT_WIDTH_EXTRA_CTL_CLK_ACT_TO_ACT_DIFF_BANK   =   4,
        CFG_PORT_WIDTH_EXTRA_CTL_CLK_FOUR_ACT_TO_ACT        =   4,
        CFG_PORT_WIDTH_EXTRA_CTL_CLK_ARF_TO_VALID           =   4,
        CFG_PORT_WIDTH_EXTRA_CTL_CLK_PDN_TO_VALID           =   4,
        CFG_PORT_WIDTH_EXTRA_CTL_CLK_SRF_TO_VALID           =   4,
        CFG_PORT_WIDTH_EXTRA_CTL_CLK_SRF_TO_ZQ_CAL          =   4,
        CFG_PORT_WIDTH_EXTRA_CTL_CLK_ARF_PERIOD             =   4,
        CFG_PORT_WIDTH_EXTRA_CTL_CLK_PDN_PERIOD             =   4,
        
        // Output - derived timing parameters width
        T_PARAM_ACT_TO_RDWR_WIDTH                           =   6,          // temporary
        T_PARAM_ACT_TO_PCH_WIDTH                            =   6,          // temporary
        T_PARAM_ACT_TO_ACT_WIDTH                            =   6,          // temporary
        T_PARAM_RD_TO_RD_WIDTH                              =   6,          // temporary
        T_PARAM_RD_TO_RD_DIFF_CHIP_WIDTH                    =   6,          // temporary
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

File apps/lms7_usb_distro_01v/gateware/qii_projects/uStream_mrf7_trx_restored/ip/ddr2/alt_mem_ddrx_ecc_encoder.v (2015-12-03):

//altera message_off 10036

`timescale 1 ps / 1 ps

module alt_mem_ddrx_ecc_encoder #
    ( parameter
        CFG_DATA_WIDTH              =   40,
        CFG_ECC_CODE_WIDTH          =   8,
        CFG_ECC_ENC_REG             =   0,
        CFG_MMR_DRAM_DATA_WIDTH     =   7,
        CFG_MMR_LOCAL_DATA_WIDTH    =   7,
        
        CFG_PORT_WIDTH_ENABLE_ECC   =   1
    )
    (
        ctl_clk,
        ctl_reset_n,
        
        cfg_local_data_width,
        cfg_dram_data_width,
        cfg_enable_ecc,
        
        input_data,
        input_ecc_code,
        input_ecc_code_overwrite,
        output_data
    );

localparam CFG_ECC_DATA_WIDTH = (CFG_DATA_WIDTH > 8) ? (CFG_DATA_WIDTH - CFG_ECC_CODE_WIDTH) : (CFG_DATA_WIDTH);

input  ctl_clk;
input  ctl_reset_n;

input  [CFG_MMR_DRAM_DATA_WIDTH   - 1 : 0] cfg_local_data_width;
input  [CFG_MMR_LOCAL_DATA_WIDTH  - 1 : 0] cfg_dram_data_width;
input  [CFG_PORT_WIDTH_ENABLE_ECC - 1 : 0] cfg_enable_ecc;

input  [CFG_DATA_WIDTH     - 1 : 0] input_data;
input  [CFG_ECC_CODE_WIDTH - 1 : 0] input_ecc_code;
input                               input_ecc_code_overwrite;

output [CFG_DATA_WIDTH - 1 : 0] output_data;

//--------------------------------------------------------------------------------------------------------
//
//  [START] Register & Wires
//
//--------------------------------------------------------------------------------------------------------
    reg  [CFG_DATA_WIDTH     - 1 : 0] int_encoder_input;
    
    reg  [CFG_DATA_WIDTH     - 1 : 0] int_input_data;
    reg  [CFG_ECC_CODE_WIDTH - 1 : 0] int_input_ecc_code;
    reg                               int_input_ecc_code_overwrite;
    reg  [CFG_DATA_WIDTH     - 1 : 0] int_encoder_output;
    
    reg  [CFG_DATA_WIDTH     - 1 : 0] output_data;
    reg  [CFG_DATA_WIDTH     - 1 : 0] int_encoder_output_modified;
    
    wire [CFG_ECC_DATA_WIDTH - 1 : 0] encoder_input;
    wire [CFG_DATA_WIDTH     - 1 : 0] encoder_output;
//--------------------------------------------------------------------------------------------------------
//
//  [END] Register & Wires
//
//--------------------------------------------------------------------------------------------------------

//--------------------------------------------------------------------------------------------------------
//
//  [START] Common Logic
//
//--------------------------------------------------------------------------------------------------------
    // Input data
    generate
        genvar i_data;
        for (i_data = 0;i_data < CFG_DATA_WIDTH;i_data = i_data + 1)
        begin : encoder_input_per_data_width
            always @ (*)
            begin
                int_encoder_input [i_data] = input_data [i_data];
            end
        end
    endgenerate
    
    // Encoder input assignment
    assign encoder_input = int_encoder_input [CFG_ECC_DATA_WIDTH - 1 : 0];
    
    // Output data merging logic
    // change
    // <ECC code> - <Empty data> - <Data>
    // into
    // <Empty data> - <ECC code> - <Data>
    always @ (*)
    begin
        int_encoder_output = encoder_output;
    end
    
    generate
        if (CFG_DATA_WIDTH <= 8)
        begin
            // No support for ECC case
            always @ (*)
            begin
                // Write data only
                int_encoder_output_modified = int_encoder_output;
            end
        end
        else
        begin
            always @ (*)
            begin
                // Write data
                int_encoder_output_modified [CFG_ECC_DATA_WIDTH - 1 : 0] = int_encoder_output [CFG_ECC_DATA_WIDTH - 1 : 0];
                
                // Ecc code
                if (int_input_ecc_code_overwrite)
                begin
                    int_encoder_output_modified [CFG_DATA_WIDTH - 1 : CFG_ECC_DATA_WIDTH] = int_input_ecc_code;
                end
                else
                begin
                    int_encoder_output_modified [CFG_DATA_WIDTH - 1 : CFG_ECC_DATA_WIDTH] = int_encoder_output [CFG_DATA_WIDTH - 1 : CFG_ECC_DATA_WIDTH];
                end
            end
        end
    endgenerate
    
    // Encoder output assignment
    always @ (*)
    begin
        if (cfg_enable_ecc)
            output_data = int_encoder_output_modified;
        else
            output_data = int_input_data;
    end
    
    generate
        if (CFG_ECC_ENC_REG)
        begin
            // Registered version
            always @ (posedge ctl_clk or negedge ctl_reset_n)
            begin
                if (!ctl_reset_n)
                begin
                    int_input_data               <= 0;
                    int_input_ecc_code           <= 0;
                    int_input_ecc_code_overwrite <= 0;
                end
                else
                begin
                    int_input_data               <= input_data;
                    int_input_ecc_code           <= input_ecc_code;
                    int_input_ecc_code_overwrite <= input_ecc_code_overwrite;
                end
            end
        end
        else
        begin
            // Non-registered version
            always @ (*)
            begin
                int_input_data               = input_data;
                int_input_ecc_code           = input_ecc_code;
                int_input_ecc_code_overwrite = input_ecc_code_overwrite;
            end
        end
    endgenerate
    
//--------------------------------------------------------------------------------------------------------
//
//  [END] Common Logic
//
//--------------------------------------------------------------------------------------------------------
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

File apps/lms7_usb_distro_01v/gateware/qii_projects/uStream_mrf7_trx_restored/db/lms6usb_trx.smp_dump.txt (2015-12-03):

State Machine - |lms7_uStream_trx_top|nco_bin_sin:inst19|state
Name state.Phase3_Q state.Phase3_I state.Phase2_Q state.Phase2_I state.Phase1_Q state.Phase1_I state.Idle state.Phase0_I state.Phase0_Q 
state.Phase0_Q 0 0 0 0 0 0 0 0 0 
state.Phase0_I 0 0 0 0 0 0 0 1 1 
state.Idle 0 0 0 0 0 0 1 0 1 
state.Phase1_I 0 0 0 0 0 1 0 0 1 
state.Phase1_Q 0 0 0 0 1 0 0 0 1 
state.Phase2_I 0 0 0 1 0 0 0 0 1 
state.Phase2_Q 0 0 1 0 0 0 0 0 1 
state.Phase3_I 0 1 0 0 0 0 0 0 1 
state.Phase3_Q 1 0 0 0 0 0 0 0 1 

State Machine - |lms7_uStream_trx_top|slaveFIFO2b_streamINOUT:inst17|slaveFIFO2b_streamIN:stream_in_inst|current_stream_in_state
Name current_stream_in_state.stream_in_wait_fifo current_stream_in_state.stream_in_write_wr_delay4 current_stream_in_state.stream_in_write_wr_delay3 current_stream_in_state.stream_in_write_wr_delay2 current_stream_in_state.stream_in_write_wr_delay1 current_stream_in_state.stream_in_write_wr_delay current_stream_in_state.stream_in_write current_stream_in_state.stream_in_wait_flagb current_stream_in_state.stream_in_idle 
current_stream_in_state.stream_in_idle 0 0 0 0 0 0 0 0 0 
current_stream_in_state.stream_in_wait_flagb 0 0 0 0 0 0 0 1 1 
current_stream_in_state.stream_in_write 0 0 0 0 0 0 1 0 1 
current_stream_in_state.stream_in_write_wr_delay 0 0 0 0 0 1 0 0 1 
current_stream_in_state.stream_in_write_wr_delay1 0 0 0 0 1 0 0 0 1 
current_stream_in_state.stream_in_write_wr_delay2 0 0 0 1 0 0 0 0 1 
current_stream_in_state.stream_in_write_wr_delay3 0 0 1 0 0 0 0 0 1 
current_stream_in_state.stream_in_write_wr_delay4 0 1 0 0 0 0 0 0 1 
current_stream_in_state.stream_in_wait_fifo 1 0 0 0 0 0 0 0 1 

State Machine - |lms7_uStream_trx_top|slaveFIFO2b_streamINOUT:inst17|slaveFIFO2b_streamOUT:stream_out_inst|current_stream_out_state
Name current_stream_out_state.fifofull_wait1 current_stream_out_state.fifofull_wait0 current_stream_out_state.stream_out_read_oe_delay current_stream_out_state.stream_out_read_rd_and_oe_delay current_stream_out_state.stream_out_read current_stream_out_state.stream_out_wait_flagd current_stream_out_state.stream_out_flagc_rcvd current_stream_out_state.stream_out_idle 
current_stream_out_state.stream_out_idle 0 0 0 0 0 0 0 0 
current_stream_out_state.stream_out_flagc_rcvd 0 0 0 0 0 0 1 1 
current_stream_out_state.stream_out_wait_flagd 0 0 0 0 0 1 0 1 
current_stream_out_state.stream_out_read 0 0 0 0 1 0 0 1 
current_stream_out_state.stream_out_read_rd_and_oe_delay 0 0 0 1 0 0 0 1 
current_stream_out_state.stream_out_read_oe_delay 0 0 1 0 0 0 0 1 
current_stream_out_state.fifofull_wait0 0 1 0 0 0 0 0 1 
current_stream_out_state.fifofull_wait1 1 0 0 0 0 0 0 1 

State Machine - |lms7_uStream_trx_top|sl_ctrl:inst22|s_r
Name s_r.s2 s_r.s1 s_r.s0 
s_r.s0 0 0 0 
s_r.s1 0 1 1 
s_r.s2 1 0 1 

State Machine - |lms7_uStream_trx_top|ram_control:inst15|addr_state
Name addr_state.s5 addr_state.s4 addr_state.s3 addr_state.s2 addr_state.s1 addr_state.s0 
addr_state.s0 0 0 0 0 0 0 
addr_state.s1 0 0 0 0 1 1 
addr_state.s2 0 0 0 1 0 1 
addr_state.s3 0 0 1 0 0 1 
addr_state.s4 0 1 0 0 0 1 
addr_state.s5 1 0 0 0 0 1 

State Machine - |lms7_uStream_trx_top|ram_control:inst15|wfifo_state
Name wfifo_state.s5 wfifo_state.s4 wfifo_state.s3 wfifo_state.s2 wfifo_state.s1 wfifo_state.s0 
wfifo_state.s0 0 0 0 0 0 0 
wfifo_state.s1 0 0 0 0 1 1 
wfifo_state.s2 0 0 0 1 0 1 
wfifo_state.s3 0 0 1 0 0 1 
wfifo_state.s4 0 1 0 0 0 1 
wfifo_state.s5 1 0 0 0 0 1 

State Machine - |lms7_uStream_trx_top|ram_control:inst15|burst_state
Name burst_state.s5 burst_state.s4 burst_state.s3 burst_state.s2 burst_state.s1 burst_state.s0 
burst_state.s0 0 0 0 0 0 0 
burst_state.s1 0 0 0 0 1 1 
burst_state.s2 0 0 0 1 0 1 
burst_state.s3 0 0 1 0 0 1 
burst_state.s4 0 1 0 0 0 1 
burst_state.s5 1 0 0 0 0 1 

State Machine - |lms7_uStream_trx_top|ram_control:inst15|fifo_state
Name fifo_state.s5 fifo_state.s4 fifo_state.s3 fifo_state.s2 fifo_state.s1 fifo_state.s0 
fifo_state.s0 0 0 0 0 0 0 
fifo_state.s1 0 0 0 0 1 1 
fifo_state.s2 0 0 0 1 0 1 
fifo_state.s3 0 0 1 0 0 1 
fifo_state.s4 0 1 0 0 0 1 
fifo_state.s5 1 0 0 0 0 1 

State Machine - |lms7_uStream_trx_top|ddr2:inst1|ddr2_controller_phy:ddr2_controller_phy_inst|ddr2_phy:ddr2_phy_inst|ddr2_phy_alt_mem_phy:ddr2_phy_alt_mem_phy_inst|ddr2_phy_alt_mem_phy_mimic:mmc|mimic_state
Name mimic_state.011 mimic_state.010 mimic_state.001 mimic_state.000 mimic_state.100 
mimic_state.000 0 0 0 0 0 
mimic_state.001 0 0 1 1 0 
mimic_state.010 0 1 0 1 0 
mimic_state.011 1 0 0 1 0 
mimic_state.100 0 0 0 1 1
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

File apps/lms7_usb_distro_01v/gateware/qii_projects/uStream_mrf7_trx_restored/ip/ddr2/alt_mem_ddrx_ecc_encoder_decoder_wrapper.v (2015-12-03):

//altera message_off 10230 10036

`timescale 1 ps / 1 ps
module alt_mem_ddrx_ecc_encoder_decoder_wrapper #
    ( parameter
        CFG_LOCAL_DATA_WIDTH                    =   80,
        CFG_LOCAL_ADDR_WIDTH                    =   32,
        CFG_DWIDTH_RATIO                        =   2,
        
        CFG_MEM_IF_DQ_WIDTH                     =   40,
        CFG_MEM_IF_DQS_WIDTH                    =   5,
        
        CFG_ECC_CODE_WIDTH                      =   8,
        CFG_ECC_MULTIPLES                       =   1,
        
        CFG_ECC_ENC_REG                         =   0,
        CFG_ECC_DEC_REG                         =   0,
		CFG_ECC_DECODER_REG						=	0,
        CFG_ECC_RDATA_REG                       =   0,
        
        CFG_PORT_WIDTH_INTERFACE_WIDTH          =   8,
        CFG_PORT_WIDTH_ENABLE_ECC               =   1,
        CFG_PORT_WIDTH_GEN_SBE                  =   1,
        CFG_PORT_WIDTH_GEN_DBE                  =   1,
        CFG_PORT_WIDTH_ENABLE_INTR              =   1,
        CFG_PORT_WIDTH_MASK_SBE_INTR            =   1,
        CFG_PORT_WIDTH_MASK_DBE_INTR            =   1,
        CFG_PORT_WIDTH_MASK_CORR_DROPPED_INTR   =   1,
        CFG_PORT_WIDTH_CLR_INTR                 =   1,
        
        STS_PORT_WIDTH_SBE_ERROR                =   1,
        STS_PORT_WIDTH_DBE_ERROR                =   1,
        STS_PORT_WIDTH_SBE_COUNT                =   8,
        STS_PORT_WIDTH_DBE_COUNT                =   8,
        STS_PORT_WIDTH_CORR_DROP_ERROR          =   1,
        STS_PORT_WIDTH_CORR_DROP_COUNT          =   8
    )
    (
        ctl_clk,
        ctl_reset_n,
        
        // MMR Interface
        cfg_interface_width,
        cfg_enable_ecc,
        cfg_gen_sbe,
        cfg_gen_dbe,
        cfg_enable_intr,
        cfg_mask_sbe_intr,
        cfg_mask_dbe_intr,
        cfg_mask_corr_dropped_intr,
        cfg_clr_intr,
        
        // Wdata & Rdata Interface Inputs
        wdatap_dm,
        wdatap_data,
        wdatap_rmw_partial_data,
        wdatap_rmw_correct_data,
        wdatap_rmw_partial,
        wdatap_rmw_correct,
        wdatap_ecc_code,
        wdatap_ecc_code_overwrite,
        rdatap_rcvd_addr,
        rdatap_rcvd_cmd,
        rdatap_rcvd_corr_dropped,
        
        // AFI Interface Inputs
        afi_rdata,
        afi_rdata_valid,
        
        // Wdata & Rdata Interface Outputs
        ecc_rdata,
        ecc_rdata_valid,
        
        // AFI Inteface Outputs
        ecc_dm,
        ecc_wdata,
        
        // ECC Error Information
        ecc_sbe,
        ecc_dbe,
        ecc_code,
        ecc_interrupt,
        
        // MMR ECC Information
        sts_sbe_error,
        sts_dbe_error,
        sts_sbe_count,
        sts_dbe_count,
        sts_err_addr,
        sts_corr_dropped,
        sts_corr_dropped_count,
        sts_corr_dropped_addr
    );
//--------------------------------------------------------------------------------------------------------
//
//  Important Note:
//  
//  This block is coded with the following consideration in mind
//  - Parameter
//      - maximum LOCAL_DATA_WIDTH will be (40 * DWIDTH_RATIO)
//      - maximum ECC_DATA_WIDTH will be (40 * DWIDTH_RATIO)
//  - MMR configuration
//      - ECC option disabled:
//          - maximum DQ width is 40
//          - maximum LOCAL_DATA width is (40 * DWIDTH_RATIO)
//          - WDATAP_DATA and ECC_DATA size will match (no ECC code)
//      - ECC option enabled:
//          - maximum DQ width is 40
//          - maximum LOCAL_DATA width is (32 * DWIDTH_RATIO)
//          - WDATAP_DATA width will be (8 * DWIDTH_RATIO) lesser than ECC_DATA (ECC code)
//  
//  Block level diagram
//  -----------------------------------                                                                               
//      Write Data Path (Per DRATE)                                                                                   
//  -----------------------------------                                                                               
//                     __________                    ___________                    ___________                       
//                    |          |                  |           |                  |           |                      
//  Local Write Data  |   Data   |                  |           |                  |           |                      
//  ---- 40 bits ---->|   Mask   |---- 32 bits ---->|  Encoder  |---- 40 bits ---->|  ECC MUX  |---- 40 bits ---->    
//                |   |          |                  |           |                  |           |                      
//                |   |__________|                  |___________|                  |___________|                      
//                |                                                                      ^                            
//                |---------------------------------- 40 bits ---------------------------|                            
//                                                                                                                    
//                                                                                                                    
//  -----------------------------------                                                                               
//      Read Data Path (Per DRATE)                                                                                    
//  -----------------------------------                                                                               
//                     __________                    ___________                    ___________                       
//                    |          |                  |           |                  |           |                      
//    AFI Read Data   |   Data   |                  |           |                  |           |                      
//  ---- 40 bits ---->|   Mask   |---- 40 bits ---->|  Decoder  |---- 32 bits ---->|  ECC MUX  |---- 40 bits ---->    
//                |   |          |                  |           |                  |           |                      
//                |   |__________|                  |___________|                  |___________|                      
//                |                                                                      ^                            
//                |---------------------------------- 40 bits ---------------------------|                            
//                                                                                                                    
//--------------------------------------------------------------------------------------------------------

localparam CFG_MEM_IF_DQ_PER_DQS         = CFG_MEM_IF_DQ_WIDTH / CFG_MEM_IF_DQS_WIDTH;

localparam CFG_ECC_DATA_WIDTH            = CFG_MEM_IF_DQ_WIDTH  * CFG_DWIDTH_RATIO;
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

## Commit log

2015-03-25 Add pin mapping for Stream v2 boards
2015-03-25 Add internal SPI master
2015-03-25 Add more sw drivers
2015-03-26 Added enclosure design
2015-04-13 Added enclosure Solidworks and IGES CAD files
    [STREAM_enclosure_base.IGS, STREAM_enclosure_base.SLDPRT, STREAM_enclosure_top.IGS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]
2015-12-03 Added uSTREAM hardware design and examples
    [Board block diagram.sch, Board power supply 1.sch, Board power supply 2.sch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]

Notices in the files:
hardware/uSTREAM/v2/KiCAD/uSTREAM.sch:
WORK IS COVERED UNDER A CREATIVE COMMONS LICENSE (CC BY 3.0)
